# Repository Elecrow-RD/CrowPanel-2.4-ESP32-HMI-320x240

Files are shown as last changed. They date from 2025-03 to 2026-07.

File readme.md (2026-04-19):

### 1, Product picture

2 4_hmi_display

### 2, Product version number

| | Hardware | Software | Remark |
| ---- | --- | --- | --- |
| 1 | V1.0 | V1.0 | old |
| 1 | V1.1 | V1.0 | old |
| 1 | V2.0 | V1.0 | old |
| 1 | V2.1 | V1.0 | latest |

**Version 2.0/2.1** upgrades the automatic download feature from Version 1.0.

### 3, product information

- Model: 2.4 inches-CrowPanel ESP32 display
- Main Processor: ESP32-WROOM-32-N4
- Resolution: 240*320
- Touch Type: Resistive Touch Screen
- Display Type: TN Panel
- Screen: TFT-LCD Screen
- Display driver: ILI9341V
- External power supply: DC5V-2A
- Interface: 1\*TF Card Slot, 1* I2C, 1* GPIO, 1\*Speak, 1* UART1, 1*UART0
- Button: BOOT Button and Reset Button
- Active Area: 36.72\*48.96mm(W*H)
- Working Temperature: -20℃～70℃
- Storage Temperature: -30℃～80℃

### 4, Use the driver module

| Name | dependency library |
| ---- | --- |
| LVGL | lvgl/lvgl@8.3.3 |

### 5,Quick Start

##### Arduino IDE starts

1.Download the library files used by this product to the 'libraries' folder.

C:\Users\Documents\Arduino\libraries\



2.Open the Arduino IDE

arduino1

3.Open the code configuration environment and burn it

arduino2

##### ESP-IDF starts

1.Right-click on an empty space in the project folder and select "Open with VS Code" to open the project.



2.In the IDF plug-in, select the port, then compile and flash



##### PlatformIO starts

1.Right-click on an empty space in the project folder and select "Open with VS Code" to open the project.



2.In the PlatformIO plug-in, select the port, then compile and flash

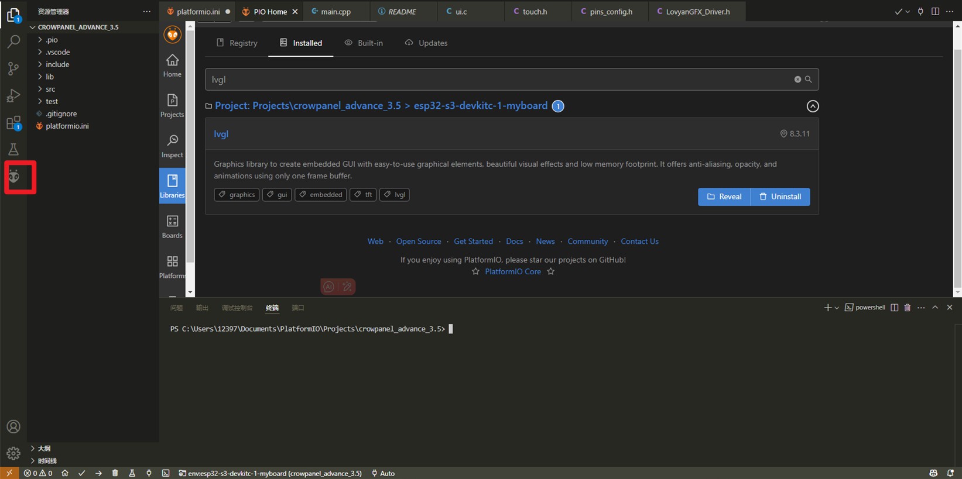
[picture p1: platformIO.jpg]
platformIO


##### Micropython starts

1,Right-click on an empty space in the project folder and select "Thonny" to open the project.

thonny

2,In thonny software, select the master and port, then run the program

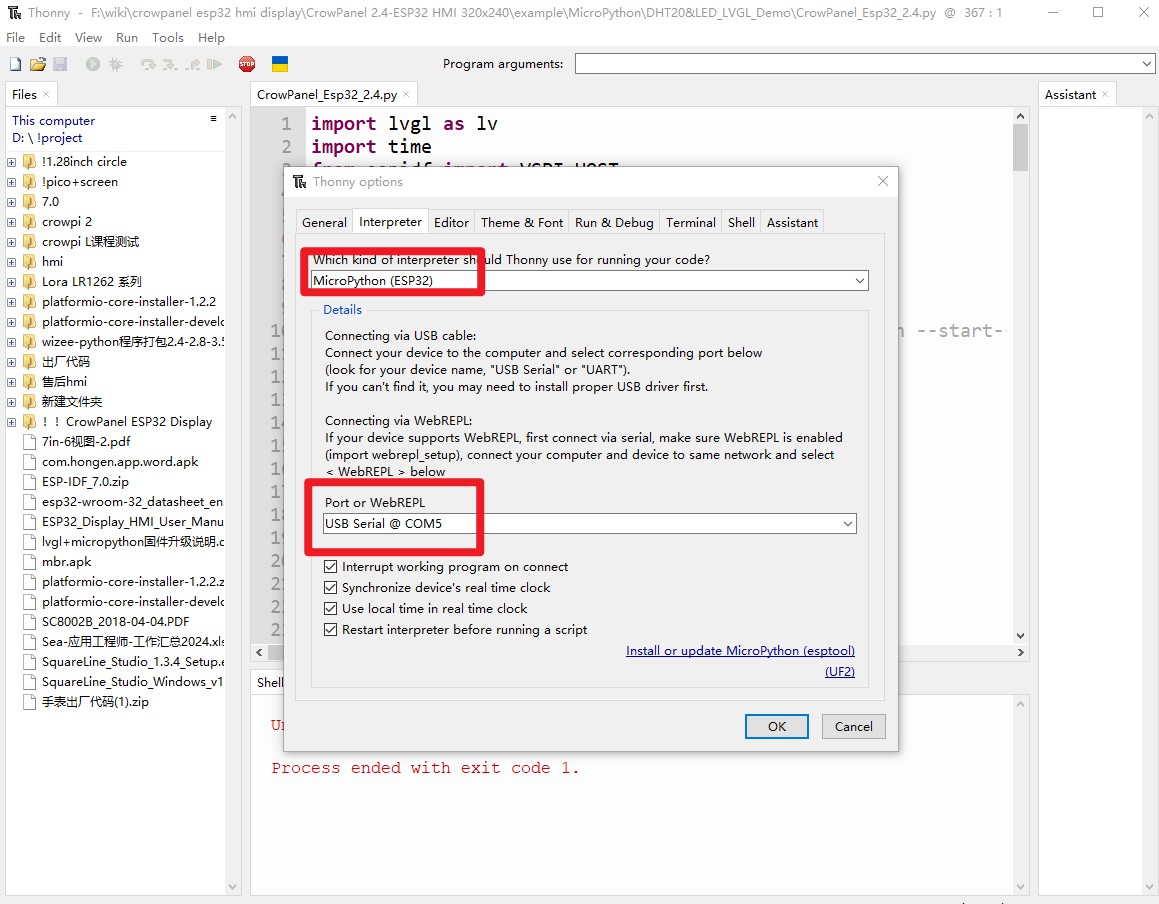
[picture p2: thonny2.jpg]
thonny2


### 6,Folder structure.

|--3D file： Contains 3D model files (.stp) for the hardware. These files can be used for visualization, enclosure design, or integration into CAD software.

|--Datasheet: Includes datasheets for components used in the project, providing detailed specifications, electrical characteristics, and pin configurations.

|--Eagle_SCH&PCB: Contains **Eagle CAD** schematic (`.sch`) and PCB layout (`.brd`) files. These are used for circuit design and PCB manufacturing.

|--example: Provides example code and projects to demonstrate how to use the hardware and libraries. These examples help users get started quickly.

|--factory_firmware: Stores pre-compiled factory firmware that can be directly flashed onto the device. This ensures the device runs the default functionality.

|--factory_sourcecode: Contains the source code for the factory firmware, allowing users to modify and rebuild the firmware as needed.

### 7,Pin definition

#define SD_MOSI 23

#define SD_MISO 19

#define SD_SCK 18

#define SD_CS 5

iic:

  Wire.begin(22, 21);

\#define TFT_BL   27            // LED back-light control pin

#define TFT_MISO 12 

#define TFT_MOSI 13 // In some display driver board, it might be written as "SDA" and so on. 

#define TFT_SCLK 14 #define TFT_CS   15  // Chip select control pin 

#define TFT_DC   2  // Data Command control pin 

#define TFT_RST  -1  // Reset pin (could connect to Arduino RESET pin) 

#define TFT_BL   27  // LED back-light 

#define TOUCH_CS 33     // Chip select pin (T_CS) of touch screen

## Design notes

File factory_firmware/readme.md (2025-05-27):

# How to install the factory demo firmware with flash download tool?

#### 1.Preparation:

- USB C cable
- Laptop/PC
- Crowpanel 2.4 HMI ESP32 Display
- Flash download tool

Check whether the materials on the PCBA board are defective. Such as less material, false welding, tin and other bad phenomena.

#### 2.Flash the firmware 

##### Step1 Connect the ESP32 display to the laptop/PC with USB-C cable. The power indicator will light up.

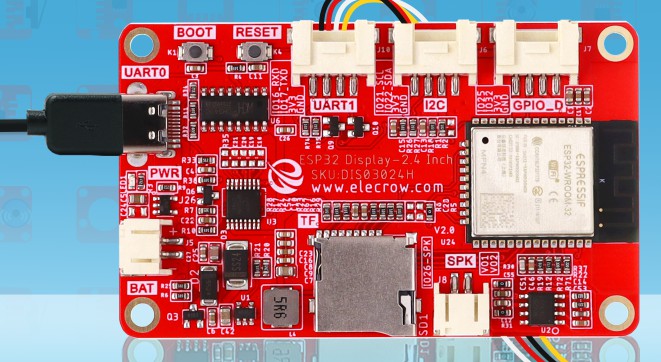
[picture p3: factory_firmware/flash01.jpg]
flash01


##### Step2 Open the flash download tool. 

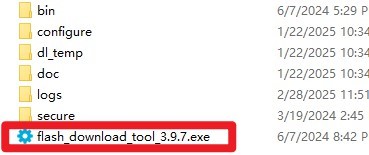
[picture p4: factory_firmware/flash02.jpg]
flash02


For the  Crowpanel 2.4 HMI ESP32 Display, the chip select ESP32:

firmware1

##### Step3

①Choose the firmware files;

flash0

②Enter the address: 

boot_app0.bin------0xe000

xxxx.ino.bin--------0x10000

xxxx.ino.bootloader.bin------0x1000

xxxx.ino.partitions.bin-------0x8000

③Check the firmware files;

④Select the correct port number;

⑤Click “Start” to download

firmware2

### Note: If it is v1.0 version, before downloading firmware or program, you need to press the boot button, then short press the reset button, and then release the boot button to enter the burn mode. If it is v2.0 or above, this step is not needed, it will automatically enter into burn mode.

##### Step5 After the download is complete, blue FINISH will be displayed, and the progress bar at the bottom shows that it has come to an end.

firmware3

##### Step6 Press the reset button to show the demo.

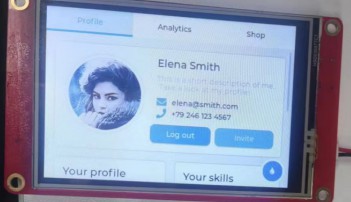
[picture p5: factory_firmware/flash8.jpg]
flash8


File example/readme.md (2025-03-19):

**Arduino**: This folder contains sample programs for the Arduino platform, which is known for its ease of use and versatility in creating interactive electronic projects.

#### NOTE!!!:When running this program , you need to download the officially provided libraries and place them in the libraries of arduino. esp32 version needs to be 2.0.14/2.0.15. the version of the libraries is the same as the officially provided version.

Link to the corresponding course wiki:https://www.elecrow.com/wiki/2.4-inch-esp32-dispaly-arduino-tutorial.html

homeassitant wiki:https://www.elecrow.com/wiki/2.4-inch-esp32-dispaly-homeAssistant-tutorial.html

Video Tutorial Links：https://www.youtube.com/watch?v=x4LrIeEJTls&t=2s

**ESP_IDF**: This directory holds example code for the Espressif IoT Development Framework (ESP-IDF), designed for developing applications on ESP32 and ESP8266 microcontrollers.

Link to the corresponding course wiki:https://www.elecrow.com/wiki/CrowPanel-ESP32-2.4-inch-with-ESP-IDF.html

**Esphome**: Here you'll find sample programs for Esphome, a firmware framework that simplifies the process of creating smart home devices using ESP8266/ESP32 chips.

Link to the corresponding course wiki:https://www.elecrow.com/wiki/CrowPanel_ESP32_2.4-inch_with_ESPHome.html

**MicroPython**: This section includes examples for MicroPython, a lean and efficient implementation of the Python programming language that can run on microcontrollers.

Link to the corresponding course wiki:https://www.elecrow.com/wiki/2.4-inch_ESP32_Display_MicroPython_Tutorial.html

**PlatformIO**: This folder contains sample projects for PlatformIO, an open-source ecosystem that streamlines the development process across various embedded platforms by providing a consistent environment for coding, compiling, and uploading firmware.:

Link to the corresponding course wiki:https://www.elecrow.com/wiki/CrowPanel_ESP32_2.4-inch_with_PlatformIO.html

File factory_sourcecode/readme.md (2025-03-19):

### NOTE!!!:When running this program arduino factory program, you need to download the officially provided libraries and place them in the libraries of arduino. esp32 version needs to be 2.0.14/2.0.15. the version of the libraries is the same as the officially provided version.

## Key Functions in the Arduino Program

### `setup()`
The `**setup()**` function is called once when the program starts. It initializes the serial communication, sets up the display, touchpad, and initializes the LVGL graphics library. It also sets the display rotation and initializes the display driver and input device driver for LVGL.

- `Serial.begin(115200)`: Initializes the serial communication with a baud rate of 115200.
- `lcd.begin()`: Initializes the TFT display.
- `lv_init()`: Initializes the LVGL graphics library.
- `lv_disp_drv_register(&disp_drv)`: Registers the display driver with LVGL.
- `lv_indev_drv_register(&indev_drv)`: Registers the input device driver (touchpad) with LVGL.
- `ui_init()`: Initializes the user interface.

### `loop()`
The `**loop()**` function is called repeatedly after `setup()`. It handles the main program logic, updating the display with temperature and humidity data and toggling an LED based on the `led` variable.

- `lv_label_set_text(ui_Label1, DHT_buffer)`: Updates the text of a label on the UI with the temperature value.
- `lv_label_set_text(ui_Label2, DHT_buffer)`: Updates the text of a label on the UI with the humidity value.
- `digitalWrite(25, HIGH)` and `digitalWrite(25, LOW)`: Sets the state of the LED connected to pin 25.
- `lv_timer_handler()`: Calls the LVGL task handler to process GUI tasks.

### `my_disp_flush()`
The `**my_disp_flush()**` function is a callback function used by LVGL to flush the display buffer to the screen.

- `lcd.startWrite()`: Begins a write transaction to the TFT display.
- `lcd.setAddrWindow(area->x1, area->y1, w, h)`: Sets the address window for the TFT display.
- `lcd.pushColors((uint16_t *)&color_p->full, w * h, true)`: Sends the color data to the TFT display.
- `lv_disp_flush_ready(disp)`: Informs LVGL that the flushing is done.

### `my_touchpad_read()`
The `**my_touchpad_read()**` function is a callback function used by LVGL to read touchpad data.

- `lcd.getTouch(&touchX, &touchY, 600)`: Reads the touch coordinates from the TFT display.
- `data->state = LV_INDEV_STATE_PR` or `LV_INDEV_STATE_REL`: Sets the state of the touchpad (pressed or released).
- `data->point.x = touchX` and `data->point.y = touchY`: Sets the touch coordinates for LVGL.

### `clearBufferArray()`
The `**clearBufferArray()**` function clears the serial buffer array.

- `buffer[i] = NULL`: Sets each element of the buffer array to NULL, effectively clearing it.

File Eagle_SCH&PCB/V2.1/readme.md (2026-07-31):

# CrowPanel ESP32 Display 2.4 V2.1 Hardware Driver Documentation

| Item | Content |
|---|---|
| Document Version | V1.0 |
| Corresponding Hardware | CrowPanel ESP32 Display-2.4 V2.1 (Schematic dated 2024-03-14) |
| Document Date | 2026-07-29 |
| Author | Codex (compiled by cross-referencing the project schematic and verified in-repo examples) |
| Intended Use | Hardware maintenance, Arduino driver porting, functional regression, and onboarding for new team members |

## 1. Scope and Validation Rules

The hardware basis for this documentation is `V2.1/CrowPanel ESP32 Display-2.4-V2.1-20240314.sch` (EAGLE 9.5.1) and the same-named PDF/BRD files; the software basis is the 8 peripheral examples under `Arduino/Course`, the LVGL composite example, and the project-bundled library configurations for TFT_eSPI/U8g2/XPT2046/SD/Crowbits_DHT20.

The evidence priority is as follows:

1. **Verified code (highest)**: The GPIO, bus mode, polarity, and parameters actually invoked in the examples.
2. **Project-specific library configuration**: Especially the active macros in `TFT_eSPI/User_Setup.h`.
3. **Schematic net connections**: Used to confirm electrical connections, pull-ups/pull-downs, power amplifiers, power supplies, and circuits not covered by code.
4. **General device characteristics**: Used only for explanation, not as a substitute for this board's measured behavior; content that cannot be verified from the repository is marked "to be measured."

Verification status definitions: **A** = confirmed by both schematic and running example; **B** = confirmed by schematic and project configuration but lacking an independent running example; **C** = confirmed by schematic only; **D** = externally connected expansion example, not an onboard device.

> Important: The repository contains no test logs, no pinned build-environment version files, and no measured waveforms. This documentation treats `Arduino/Course` as the "verified working code" referenced by the task, but it does not fabricate experimental results such as temperature, current, or waveforms.

## 2. Product and Software Architecture Overview

- Main controller: ESP32-WROOM-32-N4, 3.3 V logic, module integrates 4 MB SPI Flash and 2.4 GHz Wi-Fi/BLE.
- Software layer: Arduino-ESP32 (Arduino API + ESP-IDF driver headers), with no standalone RTOS tasks; the underlying FreeRTOS/Wi-Fi/BLE protocol stacks are managed by the Arduino core.
- Display: 2.4-inch 320×240 TFT module J1 (schematic library part `QD281801`), configured to run as **ILI9341, 4-wire SPI**.
- Input: 4-wire resistive touchscreen + XPT2046; two onboard buttons, BOOT and RESET.
- Storage: onboard microSD/TF card socket, on an independent VSPI bus.
- Audio: ESP32 DAC2 → SC8002B power amplifier → 2-pin speaker connector.
- Peripheral expansion: I2C, UART2, GPIO/ADC/DAC Crowtail/Twig interfaces.
- Power/Download: USB Type-C, CH340C, auto-download circuit, Li-ion charging/power path, RY3420 3.3 V regulator.

## 3. Peripheral Overview Table

| Peripheral/Device | Reference/Position | Interface and Key Pins (final code values) | Software/Driver | Status |
|---|---|---|---|---|
| ESP32-WROOM-32-N4 | U24 | GPIO0~39; UART0 GPIO1/3 | Arduino-ESP32 / ESP-IDF | A |
| ILI9341 TFT 320×240 | J1 | HSPI: SCLK14, MOSI13, MISO12, CS15, DC2; RST=-1; BL27 | TFT_eSPI | A |
| XPT2046 resistive touch | U3/J1 | Shares SCLK14/MOSI13/MISO12 with TFT; CS33; IRQ36 (unused in code) | TFT_eSPI built-in touch path | A/B |
| microSD/TF card | SD1 | VSPI: SCK18, MISO19, MOSI23, CS5 | SPI + SD + FS | A |
| 3.3 V power indicator LED | LED1 | 3V3→R3 4.7 kΩ→LED1→GND, always on | Pure hardware | C |
| GPIO25 controllable LED (code-defined) | Not mapped to LED1 in schematic | GPIO25; active-high (per verified code) | Arduino GPIO | A/C (with discrepancy) |
| Audio DAC/amplifier | U2/J8 | GPIO26/DAC2 → SC8002B → J8 | ESP-IDF `driver/dac.h` | A |
| I2C expansion port | J6 | **SDA22, SCL21**, 3V3, GND | Wire/U8g2/DHT20 | A/D |
| UART2 expansion port | J10 | MCU RX=16, TX=17, 3V3, GND | HardwareSerial(2) | A/D |
| GPIO/analog expansion port | J7 | GPIO25, GPIO32, 3V3, GND | GPIO/ADC/DAC (by usage) | C |
| Reserved analog/GPIO | Test/reserved nets | GPIO4, 34, 35, 39 | GPIO/ADC (34/35/39 input-only) | C |
| BOOT button | K1 | GPIO0, pulls to GND when pressed, active-low | ROM download boot strap | B |
| RESET button | K4 | EN, pulls to GND when pressed, active-low | Hardware reset | B |
| USB-UART | J3/U6 | Type-C D+/D− → CH340C → UART0 GPIO3/1 | USB serial driver + Serial | B |
| Auto-download | Q9/Q10 | CH340C DTR#/RTS# → GPIO0/EN | esptool/Arduino uploader | B |
| Wi-Fi | U24 internal | 2.4 GHz RF; no external GPIO | WiFi.h | A |
| Bluetooth LE | U24 internal | 2.4 GHz RF; no external GPIO | ESP32 BLE Arduino | A |
| Li-ion charging/power path | U26/Q3/D2/J5 | USB VBUS, BAT+, VIN | 4054A-class linear charging + PMOS/Schottky | C |
| 3.3 V power supply | U1/L4 | VIN → RY3420/HM3420B → 3V3 | Pure hardware, no software driver | C |
| External SSD1306 OLED | J6 external | SDA22, SCL21; software I2C | U8g2 | D |
| External DHT20 | J6 external | SDA22, SCL21; I2C address managed by library | Crowbits_DHT20 + Wire | D |
| External GPS | J10 external | GPS TX→GPIO16(RX2), GPS RX←GPIO17(TX2) | HardwareSerial(2) | D |

## 4. GPIO and Bus Resource Summary

| GPIO | Final Usage | Direction/Alternate | Electrical and Sharing Relationships |
|---:|---|---|---|
| 0 | BOOT | Input/boot strap | Pulled to GND when K1 pressed; must stay high during boot to boot normally from Flash |
| 1 | UART0 TX | Output/U0TXD | Via 22 Ω to CH340C RXD; used for download log |
| 2 | TFT D/C (RS) | Push-pull output | ESP32 boot strap pin; peripherals must not forcibly drive it to a wrong level during power-up |
| 3 | UART0 RX | Input/U0RXD | Via 22 Ω to CH340C TXD |
| 4 | Reserved GPIO/ADC2_CH0 | Bidirectional/ADC | ADC2 use is limited when concurrent with Wi-Fi |
| 5 | TF CS | Push-pull output/VSPI CS | Boot-strap-related pin; card socket has 10 kΩ pull-up network |
| 12 | TFT/touch MISO | Input/HSPIQ | GPIO12 is boot strap MTDI; being pulled high by a peripheral at power-up may change the Flash voltage configuration |
| 13 | TFT/touch MOSI | Output/HSPID | Shared by two devices, arbitrated by independent CS |
| 14 | Upper: TFT/touch SCLK | Output/HSPICLK | Shared by two devices; LCD 15.999999 MHz, touch 600 kHz |
| 15 | TFT CS | Push-pull output/HSPICS0 | Boot strap MTDO; should remain unselected before initialization |
| 16 | UART2 RX | Input/U2RXD | J10 pin 1; connects to peripheral TX |
| 17 | UART2 TX | Output/U2TXD | J10 pin 2; connects to peripheral RX |
| 18 | TF SCK | Output/VSPICLK | SD dedicated bus |
| 19 | TF MISO | Input/VSPIQ | SD dedicated bus |
| 21 | I2C SCL | Open-drain bidirectional (code role) | J6 pin 1, via 1 kΩ series; schematic net name `IO21_SCL` |
| 22 | I2C SDA | Open-drain bidirectional (code role) | J6 pin 2, via 1 kΩ series; schematic net name `IO22_SDA` |
| 23 | TF MOSI | Output/VSPID | SD dedicated bus |
| 25 | Code-defined controllable LED/J7 pin 1 | Push-pull output; also DAC1/ADC2 | Code controls LED high/low; V2.1 schematic only clearly connects it to J7, not to LED1 |
| 26 | Speaker | DAC2 analog output | Fed to SC8002B via coupling/feedback network; must not be reused as a normal digital peripheral |
| 27 | LCD backlight | Push-pull/PWM optional | Drives 2N7002 gate; code HIGH turns it on |
| 32 | J7 pin 2 | GPIO/ADC1_CH4 | 3.3 V logic; usable as a reliable ADC input |
| 33 | Touch CS | Push-pull output | Independent chip-select for XPT2046 |
| 34 | Reserved ADC1_CH6 | **Input only** | No internal output drive capability |
| 35 | Reserved ADC1_CH7 | **Input only** | No internal output drive capability |
| 36 | Touch IRQ | **Input only**/ADC1_CH0 | XPT2046 PENIRQ; current example polls, no attachInterrupt |
| 39 | Reserved ADC1_CH3 | **Input only** | No internal output drive capability |

Bus isolation: display/touch use the HSPI pin group 12/13/14, while the TF card uses the VSPI pin group 19/23/18, so they can operate in parallel; on the same HSPI bus, TFT CS15 and Touch CS33 must be mutually exclusive.

## 5. Per-Peripheral Driver Description

### 5.1 ESP32-WROOM-32-N4 Main Controller

**Hardware**: U24, 3.3 V supply, module model explicitly N4 (4 MB Flash). EN is pulled up by 10 kΩ and connected to the reset button/auto-download circuit; GPIO0 is controlled by the BOOT button and the auto-download circuit. UART0 connects to USB via CH340C.

**Software layer**: Arduino sketch → Arduino-ESP32 core → ESP-IDF HAL/drivers and FreeRTOS. The code contains no bare-metal register writes and no self-created RTOS tasks.

**Basic configuration example**:

```cpp
void setup() {
  Serial.begin(115200);       // Debug baud rate used by most examples
  pinMode(25, OUTPUT);
}
```

When porting, select the classic ESP32 target (not S2/S3/C3), and configure Flash to at least 4 MB. The repository does not record the Arduino core version, partition table, CPU frequency, or Flash mode, so a build manifest should be added during maintenance.

### 5.2 TFT LCD (J1, code configured as ILI9341)

**Connections**: GPIO14=SCLK, 13=MOSI/SDI, 12=MISO/SDO, 15=CS, 2=D/C; TFT RESET does not occupy a GPIO—the project configures `TFT_RST -1`, and the schematic's `TFT_RESET` connects to the main reset EN via R5/C28. GPIO27 controls the backlight cathode through a 2N7002, HIGH turns it on. The display supply and LED anode are 3.3 V.

**Protocol/parameters**: 4-wire hardware SPI; ILI9341; physically portrait 240×320, rotated to 320×240 after the composite example calls `setRotation(1)`; write frequency **15,999,999 Hz**, read frequency 20 MHz. TFT_eSPI's `lcd.begin()` sends the controller initialization register table.

**Software dependencies**: TFT_eSPI; the LVGL example additionally depends on LVGL 9-style APIs. The key project configuration is in `Arduino/libraries/TFT_eSPI/User_Setup.h`.

```cpp
#define ILI9341_DRIVER
#define TFT_MISO 12
#define TFT_MOSI 13
#define TFT_SCLK 14
#define TFT_CS   15
#define TFT_DC    2
#define TFT_RST  -1
#define TFT_BL   27
#define SPI_FREQUENCY 15999999

TFT_eSPI lcd;
lcd.begin();
lcd.fillScreen(TFT_BLACK);
pinMode(27, OUTPUT);
digitalWrite(27, HIGH);
lcd.setRotation(1);
```

**Initialization order**: SPI/controller init → clear to black → delay 300 ms (composite example) → backlight HIGH → set rotation → register LVGL flush. This reduces power-on display artifacts.

**Discrepancy note**: The schematic only uses the module part number `QD281801` and does not directly state ILI9341; the code and the active TFT_eSPI macros explicitly select ILI9341, so maintenance and porting should be based on ILI9341. The `TFT_WIDTH/TFT_HEIGHT` comment text mentions ST7789, but the active driver is ILI9341; this is leftover commentary from a generic configuration file and does not mean this board uses ST7789.

### 5.3 XPT2046 Resistive Touch

**Connections**: XPT2046 U3 shares GPIO14/DCLK, 13/DIN, 12/DOUT with the TFT; GPIO33=CS; GPIO36=PENIRQ. The touchscreen's four wires XP/XN/YP/YN connect to J1 through 100 pF filter capacitors. Supply/IOVDD/VREF are all 3.3 V.

**Protocol/parameters**: SPI, project sets `SPI_TOUCH_FREQUENCY 600000` (600 kHz); CS active-low. The current code polls using `lcd.getTouch()`, with a pressure threshold of 600 and no GPIO36 interrupt. The calibration array is for this specific unit/orientation: `{557, 3263, 369, 3493, 3}`.

```cpp
#define TOUCH_CS 33
#define SPI_TOUCH_FREQUENCY 600000
uint16_t calData[5] = {557, 3263, 369, 3493, 3};
lcd.setRotation(1);
lcd.setTouch(calData);
bool pressed = lcd.getTouch(&x, &y, 600);
```

**Note**: After changing the screen, changing the touch lamination orientation, or changing rotation, `calibrateTouch()` must be re-run; do not treat this calibration set as valid across the entire production batch. If switching to interrupt mode, GPIO36 is input-only—confirm on the actual board using PENIRQ active-low/falling-edge before enabling.

### 5.4 microSD/TF Card

**Connections**: GPIO18=SCK, 23=MOSI/CMD, 19=MISO/DATA0, 5=CS/DATA3, 3.3 V supply. CMD, CS, and DATA0/1/2/3 all have 10 kΩ pull-ups, meeting SD/SPI idle requirements.

**Protocol/parameters**: SPI mode of the Arduino SD library. The code explicitly maps VSPI pins and calls `SD.begin(5)` after a 100 ms wait; no frequency is passed, so the actual initial/operating frequency is determined by the Arduino-ESP32 SD library version in use—the repository cannot give a fixed value.

```cpp
SPI.begin(18, 19, 23);  // SCK, MISO, MOSI
delay(100);
if (!SD.begin(5)) { /* mount failed */ }
```

**Dependencies**: `SPI.h`, `SD.h`, `FS.h`. The example verifies mounting, card type, capacity, and two-level directory traversal.

**Note**: The card accepts 3.3 V signals only; the filesystem must finish writing before hot-swapping. The board has no card-detect GPIO confirmed from code/net names, so applications should judge insertion/removal via `SD.begin()`/I/O errors.

### 5.5 Power Indicator LED, GPIO25 Controllable LED, and GPIO Expansion

The LED1 in the schematic is a red **power indicator LED**: 3V3 connects through R3=4.7 kΩ to the LED1 anode, with the cathode to GND, so it stays on during power-up and has no electrical connection to GPIO25. GPIO25 connects to J7 pin 1 through R18=1 kΩ.

The verified example explicitly defines GPIO25 as the `on-board LED`, turned on with HIGH and off with LOW. Following the "make code run first" principle, software porting still uses GPIO25 and this polarity as the effective driving baseline; however, the V2.1 schematic cannot explain this controllable LED's on-board connection—it may be a board revision not synchronized with the schematic, an example targeting a different assembly version, or an LED that must be externally connected via J7. Maintenance personnel should confirm via PCB trace inspection/continuity testing with a multimeter, and must not treat the schematic's LED1 as this GPIO25 controllable LED.

```cpp
pinMode(25, OUTPUT);
digitalWrite(25, HIGH); // Verified example: LED on
```

J7: pin1=GPIO25, pin2=GPIO32, pin3=3V3, pin4=GND. GPIO25 also has DAC1/ADC2, and GPIO32 has ADC1_CH4; expansion peripherals will share GPIO25 with the code-defined LED control. Peripheral current must not directly exceed the ESP32 GPIO drive capability; high loads should add a MOSFET/transistor.

### 5.6 Speaker and SC8002B Amplifier

**Connections**: GPIO26/DAC2 enters U2 SC8002B through R12=4.7 kΩ and an AC/feedback network; U2 is 3.3 V supplied, with differential outputs VO1/VO2 connecting to the J8 speaker connector—neither end may be grounded. The schematic connects SHUTDOWN to AGND and assigns no software enable pin.

**Drive method**: ESP32 built-in 8-bit DAC channel 2. The example outputs via busy-waiting using a 256-point sine table; at 1 kHz the nominal sample rate is 256 ksample/s, playing for 1 s, muted for 2 s, then returning to the mid code 128 at the end to reduce DC step.

```cpp
#include <driver/dac.h>
dac_output_enable(DAC_CHANNEL_2);       // GPIO26
dac_output_voltage(DAC_CHANNEL_2, sample8bit);
```

**Risk**: The current `delayMicroseconds()` software timing occupies the CPU, and the actual frequency is affected by function overhead, making it unsuitable for high-fidelity output or strong concurrency with UI/Wi-Fi. For production, switch to I2S/DAC DMA or timer-driven output, and measure the amplifier gain, clipping, speaker impedance, and temperature rise. Do not perform single-ended oscilloscope ground measurements on the bridged amplifier output.

### 5.7 I2C Expansion Port, SSD1306, and DHT20

J6 pin1=GPIO21, pin2=GPIO22, pin3=3V3, pin4=GND; each signal has a 1 kΩ series resistor. **The final software definition is GPIO22=SDA, GPIO21=SCL**.

```cpp
Wire.begin(22, 21); // SDA, SCL
Crowbits_DHT20 dht20;
dht20.begin();
```

The external OLED example uses U8g2 software I2C:

```cpp
U8G2_SSD1306_128X64_NONAME_F_SW_I2C u8g2(
  U8G2_R0, /* clock */ 21, /* data */ 22, U8X8_PIN_NONE);
u8g2.begin();
```

**Parameters**: The SSD1306 example is 128×64 with no independent reset; the DHT20 example does not set address/frequency at the application layer and uses library defaults. The repository code does not lock the I2C clock and slave address, so they should be verified via the library implementation/bus scan before porting; common values cannot substitute for this project's evidence.

**Schematic discrepancy**: The net names are `IO21_SCL`, `IO22_SDA`, which are consistent with the code and the Arduino `Wire.begin(SDA,SCL)` parameters forming the "21=SCL, 22=SDA" connection; this itself is consistent, but old comments in the example files have easily caused the two to be misread in order. All new code must explicitly write `Wire.begin(22,21)`, and must not guess the parameter order based solely on interface names.

### 5.8 UART2 / External GPS

J10 pin1=GPIO16/RX2, pin2=GPIO17/TX2, pin3=3V3, pin4=GND. The example bridges GPS and the USB serial using UART2, 9600 baud, 8N1 full-duplex:

```cpp
HardwareSerial gpsSerial(2);
gpsSerial.begin(9600, SERIAL_8N1, 16, 17); // RX, TX
```

Wiring must be crossed: GPS TX→J10 RX/GPIO16, GPS RX←J10 TX/GPIO17, and share ground. J10 logic level is 3.3 V and must not be directly connected to RS-232 levels. The composite LVGL example only writes `Serial2.begin(9600)`, relying on the ESP32 default UART2 mapping; when porting, explicitly specifying 16/17 is recommended to avoid core/board-type differences.

### 5.9 Wi-Fi

The ESP32 module has built-in 2.4 GHz Wi-Fi with no additional driver GPIO. The example uses Arduino `WiFi.h`, STA mode, auto-reconnect, and blocks waiting for connection:

```cpp
WiFi.begin(ssid, password);
WiFi.setAutoReconnect(true);
while (WiFi.status() != WL_CONNECTED) delay(100);
```

The example contains plaintext demonstration SSID/password and should not enter production firmware. The blocking wait has no timeout; production code should add a timeout, network provisioning, and secure credential storage. When using Wi-Fi, analog sampling on ADC2 (GPIO2/4/12/13/14/15/25/26, etc.) is limited by ESP32 hardware constraints; prefer ADC1's GPIO32/34/35/36/39.

### 5.
10 Bluetooth Low Energy

Using the classic ESP32 BLE Arduino stack, device name `ESP32SPI-BLE`; establish a custom service and a READ/WRITE/NOTIFY characteristic:

```cpp
BLEDevice::init("ESP32SPI-BLE");
auto server = BLEDevice::createServer();
auto service = server->createService(SERVICE_UUID);
auto characteristic = service->createCharacteristic(
  CHARACTERISTIC_UUID,
  BLECharacteristic::PROPERTY_READ |
  BLECharacteristic::PROPERTY_WRITE |
  BLECharacteristic::PROPERTY_NOTIFY);
```

This example has no pairing, encryption, authentication, or write callback and cannot be used directly as a secure product protocol.
If you need to notify the client, you must also set a new value after connection and call `notify()`; the example only demonstrates the advertising/GATT setup path.

### 5.11 USB Type-C, CH340C, and Auto-Download

J3 is the USB Type-C USB 2.0 data/5 V input; CC1/CC2 each have a 5.1 kΩ pulldown, declaring the device side (sink/UFP). D+/D− run through 22 Ω series resistors to CH340C U6. The CH340C UART connects to ESP32 UART0 via 22 Ω: CH340 TXD → GPIO3/RX0, CH340 RXD ← GPIO1/TX0.

The CH340C DTR#/RTS# automatically control GPIO0 and EN via Q9/Q10 (S9013), implementing the download/reset sequence; K1/K4 allow manual control of BOOT/RESET. On the software side, `Serial` uses UART0; the example baud rates are inconsistent between 9600 and 115200, so the serial monitor must match the current sketch.

Maintenance note: UART0 handles both downloading and logging; external devices must not drive GPIO1/3 strongly during reset/download. Type-C only depicts USB 2.0 and does not support USB-PD negotiation; it must not be powered via PD high voltage.

### 5.12 Battery Charging, Power Path, and 3.3 V Supply

**Charging/Path**: J5 is the battery connector, pin1=BAT+, the remaining visible pins are grounded; U26 is marked `4054A`, powered by USB VBUS, with PROG setting the charge current via R9=2 kΩ; Q3 (PMOS-3401) and D2 (1N5817) form the USB/battery-to-VIN path and reverse-current protection. The specific charge-current formula, termination voltage, and battery polarity must be verified against the actual mounted U26 datasheet and silkscreen; the repository contains no BOM/datasheet, and this document makes no assumptions.

**3.3 V**: U1 schematic deviceset `HM3420B`, value `RY3420`, L4=5.6 µH; feedback R20=45.3 kΩ, R21=10 kΩ, output net name 3V3. It is a switching power supply topology supplying the MCU, LCD, touch, SD, and interfaces. The code has no power enable control.

**Risks**:

- Only allow a single-cell Li-ion system to be connected after confirming the specific U26 model; J5 polarity must be verified on the actual board.
- The charge current corresponding to R9=2 kΩ must not be taken into mass production directly from a generic 4054 formula; the actual part number must be checked and temperature rise verified.
- USB/battery switching, undervoltage behavior, maximum 3.3 V load, and ripple are not covered by the software example and require dedicated power testing.
- All external interfaces are rated at 3.3 V nominal; 5 V GPIO levels must not be applied.

### 5.13 BOOT, RESET, and Reserved Analog Pins

- K1: GPIO0→GND, active low; hold BOOT then reset to enter ROM download mode.
- K4: EN→GND, active low hard reset; EN has a pull-up and capacitor forming the power-on reset.
- GPIO34/35/39: schematic marked as a reserved ADC/analog network, input only, with no internal pull-up/pull-down.
- GPIO4: reserved GPIO/ADC2; its ADC2 function should not be relied upon when Wi-Fi is in use.
- GPIO36: already connected to touch PENIRQ and cannot be used unconditionally as a general-purpose ADC.

## 6. LVGL Comprehensive Driver Path

The comprehensive example simultaneously validates TFT, touch, GPIO25, I2C DHT20, and retains UART2 initialization. LVGL uses a 320×240 landscape display with a 1/8-screen single buffer: `320*240/8` `lv_color_t` units. The flush callback writes via a TFT_eSPI transaction; the input callback polls the touch.

```cpp
static lv_color_t buf1[320 * 240 / 8];
lv_init();
lv_tick_set_cb(millis);

lv_display_t *disp = lv_display_create(320, 240);
lv_display_set_flush_cb(disp, my_disp_flush);
lv_display_set_buffers(disp, buf1, NULL, sizeof(buf1),
                       LV_DISPLAY_RENDER_MODE_PARTIAL);

lv_indev_t *indev = lv_indev_create();
lv_indev_set_type(indev, LV_INDEV_TYPE_POINTER);
lv_indev_set_read_cb(indev, my_touchpad_read);
```

The main loop calls `lv_timer_handler()` every 10 ms but also synchronously reads DHT20 and prints heavily to the serial port. For production, the sensor sampling frequency should be reduced (e.g., via a separate timer/timestamp period) to avoid I2C or serial blocking that degrades UI frame rate.

## 7. Schematic–Code Cross-Verification Conclusions

| Item | Schematic | Verified Code/Config | Conclusion and Handling |
|---|---|---|---|
| LCD controller | J1 only marked `QD281801` | `ILI9341_DRIVER` | Use ILI9341 as reference; module part number does not equal controller name |
| LCD SPI | 14/13/12, CS15, DC2 | exactly the same | Consistent |
| LCD reset | `TFT_RESET` to EN (via R5/C28) | `TFT_RST=-1` | Consistent: no independent GPIO |
| Backlight | GPIO27→2N7002 | GPIO27 HIGH then lights up | Consistent; PWM can be added |
| Touch | XPT2046, shared SPI, CS33, IRQ36 | Shared SPI, CS33; polling does not use IRQ | Connection consistent; IRQ function not verified in code |
| TF card | SCK18/MOSI23/MISO19/CS5 | exactly the same | Consistent |
| I2C | Net name 21=SCL, 22=SDA | `Wire.begin(22,21)` | Consistent; note the API parameter order is SDA, SCL |
| UART2 | RX16/TX17 | Explicit example identical | Consistent; comprehensive example suggests adding explicit pins |
| Speaker | GPIO26/DAC2→SC8002B | DAC_CHANNEL_2 | Consistent |
| LED | LED1 is a 3V3 always-on power light; GPIO25 only clearly connects to J7 | Code refers to GPIO25 as the onboard LED, HIGH=on | Clearly inconsistent; drive follows code, physical connection reason pending continuity confirmation |
| TFT SPI frequency | Undefined in schematic | 15,999,999 Hz | Follow project configuration |
| Touch SPI frequency | Undefined in schematic | 600 kHz | Follow project configuration |
| DHT20/OLED/GPS | Only expansion ports provided, no onboard devices | External module examples | Marked as external capability, not listed as onboard devices |

Apart from the GPIO25 controllable LED, no clear "schematic pin conflicting with running code" was found. The GPIO25 discrepancy can only list possible causes (board revision/assembly version/external LED), and without physical continuity evidence no single cause can be asserted.

## 8. Risks and Notes Checklist

### 8.1 High Priority

1. **Strap-pin conflict**: GPIO0, 2, 5, 12, and 15 all involve boot configuration or onboard SPI; peripherals strongly pulling at power-on may prevent booting. In particular, a high level on GPIO12 may select an incompatible Flash power-supply configuration.
2. **3.3 V level**: I2C/UART/GPIO/SPI are not 5 V-tolerant interfaces; 5 V modules must add level shifting.
3. **Amplifier is differential output**: Neither terminal of J8 is ground; do not ground the negative terminal or directly short it with a grounded oscilloscope probe clip.
4. **Battery safety not closed**: With no BOM and no specific U26 datasheet, charge current, temperature rise, battery polarity, and protection capability must be confirmed by measurement.
5. **Credential leakage**: The Wi-Fi example contains a plaintext demo password; for mass production it must be removed and the real credentials rotated.

### 8.2 Medium Priority

1. GPIO25 simultaneously carries the code-defined LED function and an expansion port; GPIO36 simultaneously connects to the touch IRQ; do not reassign them. GPIO25's LED physical connection needs re-checking per the discrepancy noted above.
2. TFT and touch share SPI; any self-written driver must correctly pull up the non-target CS and avoid holding transactions across devices.
3. GPIO34/35/36/39 are input only; they cannot drive an LED, CS, or bus clock.
4. ADC2 conflicts with Wi-Fi concurrency; analog sampling should prefer GPIO32/34/35/39 (of which 36 is already occupied).
5. The software DAC sine implementation keeps the CPU busy and jitters under UI, BLE/Wi-Fi concurrency.
6. Touch calibration is related to screen orientation/individual unit; recalibrate after changing the screen.
7. The SD card has no card-detect pin visible; removing the card during writing will corrupt the filesystem.

### 8.3 Maintainability

1. The repository does not pin versions of Arduino-ESP32, TFT_eSPI, LVGL, etc.; a reproducible build manifest should be added.
2. Example serial baud rates mix 9600/115200; unify the product logging configuration.
3. `TFT_eSPI/User_Setup.h` is a global library configuration that may be overwritten on library upgrade/reinstall; migrate it to a standalone setup file or build macro.
4. The comprehensive example has no explicit touch `setTouch(calData)`; if the library does not save/load calibration, coordinates may be wrong and should be set explicitly during product initialization.
5. The BLE example has no security mechanism and the Wi-Fi connection has no timeout; both are teaching code and should not be carried into production as-is.

## 9. Driver Porting Checklist

1. Select the classic ESP32 target, 4 MB Flash, and confirm Flash mode and the GPIO12 boot state.
2. Pin the versions of Arduino-ESP32, TFT_eSPI, LVGL, U8g2, SD, and Crowbits_DHT20.
3. Import this project's valid TFT_eSPI macros; confirm ILI9341 and HSPI 12/13/14.
4. Keep TFT CS15, Touch CS33, and SD CS5 deselected at power-on.
5. Start the display following the sequence "LCD init and clear screen → backlight GPIO27 HIGH".
6. After setting rotation=1, recalibrate the touch and save calibration data for each screen assembly orientation.
7. For I2C explicitly call `Wire.begin(22,21)`; for UART2 explicitly call `begin(...,16,17)`.
8. For SD explicitly call `SPI.begin(18,19,23)` then `SD.begin(5)`, and perform plug/unplug and power-loss tests.
9. Check that GPIO25, 26, 27, 36, and the strap pins are not re-assigned by the application.
10. Complete USB/battery switching, maximum load, backlight PWM, audio clipping/temperature-rise, and EMC measurements.

## 10. Suggested Hardware Regression Tests

| Test | Method | Pass Criteria |
|---|---|---|
| Boot/Download | USB cold start, auto-download, manual BOOT+RESET, 20 times each | No boot failures, stable download |
| 3.3 V Supply | USB/battery, no-load/full-load ripple and drop measurement | Meets MCU/LCD/SD device specifications |
| LCD | RGB/solid color/full-screen refresh/read ID (if supported) | No glitch, color error, or tearing anomaly |
| Backlight | GPIO27 switch and PWM sweep | No flicker; MOS/LED temperature rise qualified |
| Touch | Five-point calibration, corners, long press, swipe | Coordinate error meets product spec, no false touches |
| SD | Multiple capacity/speed-class cards, repeated mount and large-file read/write | No CRC/I/O errors; power-loss strategy effective |
| I2C | Scan, DHT20/OLED on same bus, long-line stress | No address conflict/NACK; waveform rise time qualified |
| UART2 | 9600 8N1 loopback and GPS long-duration reception | No packet loss/frame error |
| Audio | Multiple frequency/amplitude, rated speaker, temperature rise | No obvious clipping/DC bias; temperature rise qualified |
| RF | Wi-Fi/BLE concurrency, throughput during LCD/SD refresh | No unacceptable dropout or interference |
| Battery | Charge curve, termination, hot-plug, reverse current, undervoltage | Complies with actual U26/battery specifications and safety requirements |

## 11. Evidence File Index

- Schematic: `V2.1/CrowPanel ESP32 Display-2.4-V2.1-20240314.sch`
- Schematic PDF: `V2.1/CrowPanel ESP32 Display-2.4-V2.1-20240314.pdf`
- PCB: `V2.1/CrowPanel ESP32 Display-2.4-V2.1-20240314.brd`
- LCD/touch config: `Arduino/libraries/TFT_eSPI/User_Setup.h`
- Comprehensive example: `Arduino/Course/LVGL_Arduino2.4/LVGL_Arduino2.4.ino`
- Single examples: `Arduino/Course/Example1_LED_blinking` through `Example8_GPS_Module`
- Related libraries: TFT_eSPI, XPT2046_Touchscreen, SD, U8g2, Crowbits_DHT20, LVGL

---

**Handoff Conclusion**: The core driver baseline of this board consists of two non-overlapping SPI groups (LCD/touch HSPI and TF VSPI), I2C SDA22/SCL21, UART2 RX16/TX17, DAC2/GPIO26 audio, GPIO27 high-active backlight, and the code-defined GPIO25 controllable LED (whose on-board connection requires physical verification). The most error-prone aspects when porting are the TFT_eSPI global configuration, touch calibration, I2C API parameter order, external levels on the strap pins, and carrying the teaching examples' blocking/plaintext/no-security logic directly into product firmware.

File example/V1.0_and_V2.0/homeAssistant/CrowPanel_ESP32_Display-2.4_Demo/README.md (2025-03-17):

**If you are using this demo code for the first time, I suggest that you watch this video lesson first.**

video link:

[Create and Export Stunning UI with SquareLine Studio for ESP32 Display | LVGL Tutorial - YouTube](https://www.youtube.com/watch?v=Ls0uLyeAgiw)

---

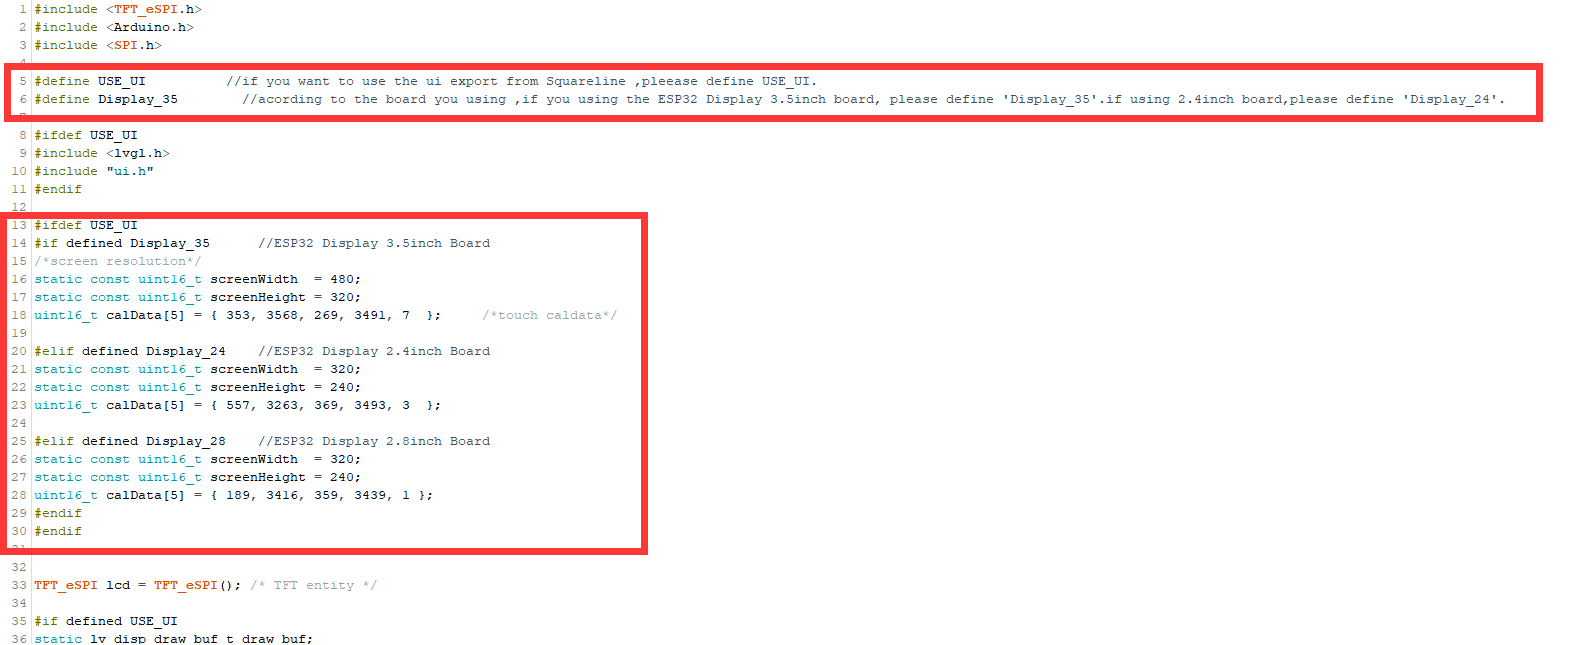
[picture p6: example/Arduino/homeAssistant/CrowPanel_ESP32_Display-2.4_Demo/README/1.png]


Please notice the tips inside the demo code,that is very important.

**If you don't want to use the UI export from Squareline Studio ,please del the UI file, and open the demo program again, then you can compile the program, or your program may happen some errors.**

---

And make sure that the 'User_Setup.h' file of the TFT_eSPI library is already correctly configured.

Or you can find the 'User_Setup.h' file from the 'User_Setup' floder.

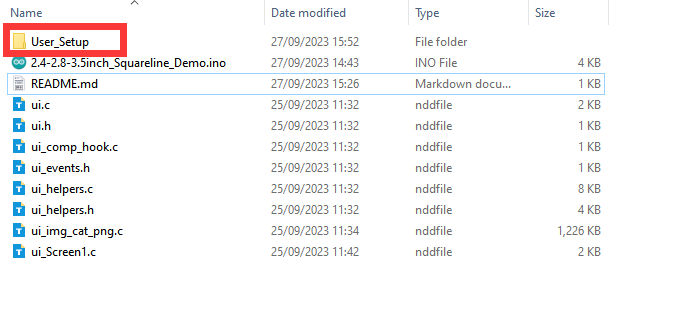
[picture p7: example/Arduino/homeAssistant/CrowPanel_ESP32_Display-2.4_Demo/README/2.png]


You need to copy the 'User_Setup.h' file according the board you're using to the TFT_eSPI library directory, and then, rename it to 'User_Setup.h'

If you already have a 'User_Setup.h' file in the TFT_eSPI library directory, replace it.

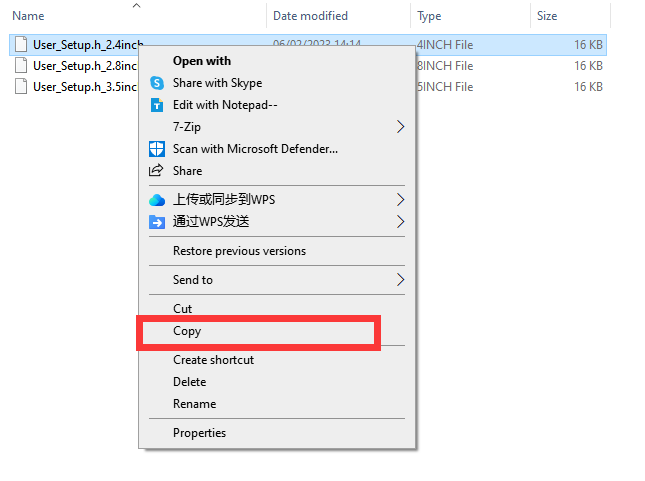
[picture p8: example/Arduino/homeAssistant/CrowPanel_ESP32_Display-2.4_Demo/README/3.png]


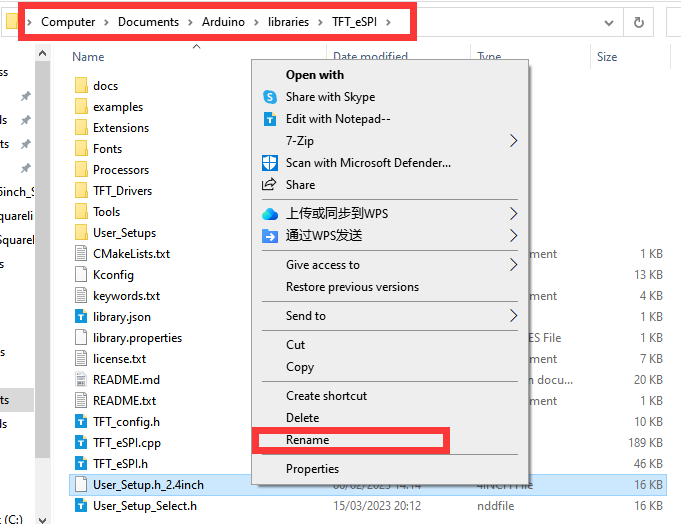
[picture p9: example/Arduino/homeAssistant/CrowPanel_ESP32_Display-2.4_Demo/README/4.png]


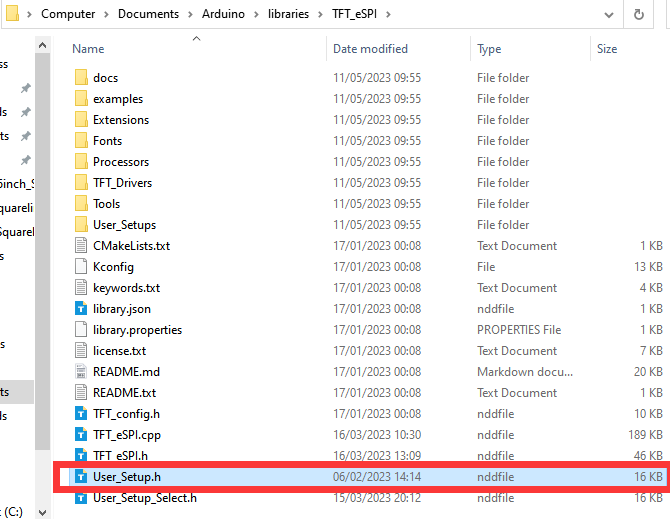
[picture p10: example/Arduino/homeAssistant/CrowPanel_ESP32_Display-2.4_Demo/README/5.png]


-------------------------------------------------------------END----------------------------------------------------------

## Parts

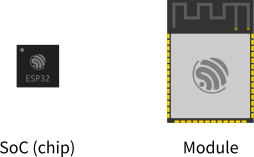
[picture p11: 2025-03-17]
example/V1.0_and_V2.0/ESP_IDF/ESP-IDF_2.4/2.4/Demo/components/arduino-esp32-master/docs/source/_static/soc-module.png

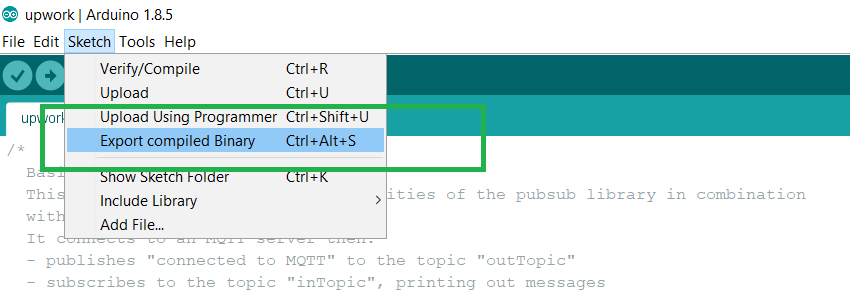
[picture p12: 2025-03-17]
example/V1.0_and_V2.0/ESP_IDF/ESP-IDF_2.4/2.4/Demo/components/arduino-esp32-master/docs/source/_static/ota_export_to_binary.png

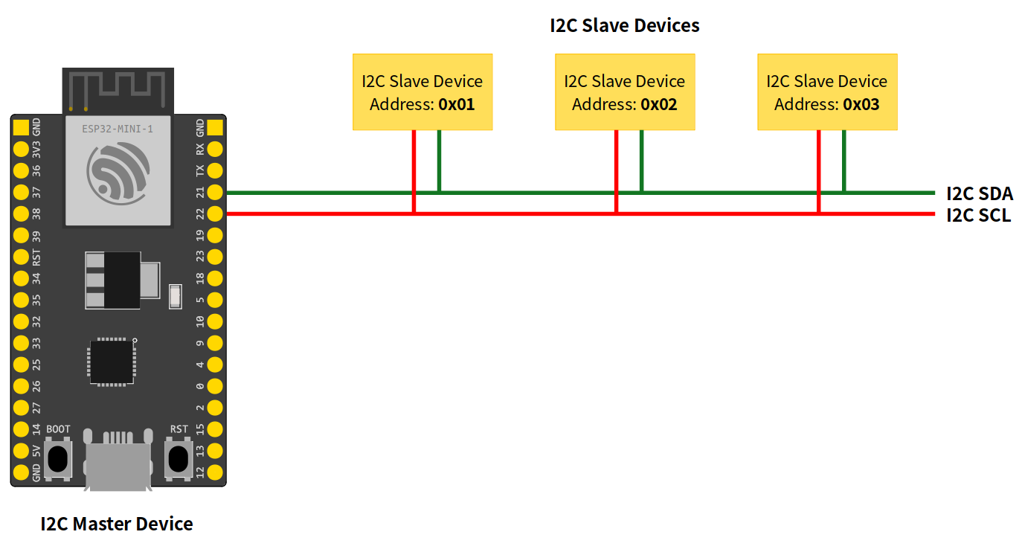
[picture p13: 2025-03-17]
example/V1.0_and_V2.0/ESP_IDF/ESP-IDF_2.4/2.4/Demo/components/arduino-esp32-master/docs/source/_static/arduino_i2c_master.png

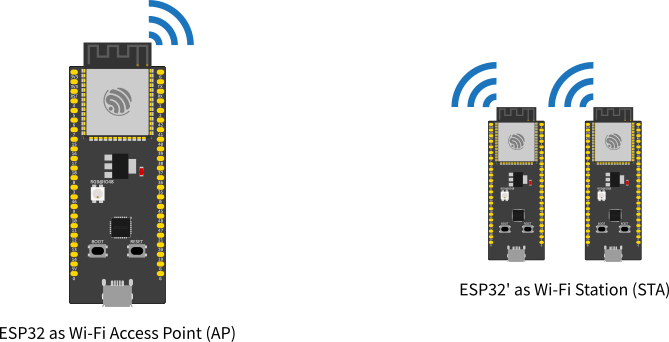
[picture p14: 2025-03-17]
example/V1.0_and_V2.0/ESP_IDF/ESP-IDF_2.4/2.4/Demo/components/arduino-esp32-master/docs/source/_static/wifi_esp32_ap.png

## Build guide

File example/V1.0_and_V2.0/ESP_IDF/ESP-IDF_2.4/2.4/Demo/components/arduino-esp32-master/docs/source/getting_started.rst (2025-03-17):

###############
Getting Started
###############

About Arduino ESP32
-------------------

Welcome to the Arduino ESP32 support documentation! Here you will find important information on how to use the project.

First Things First
------------------

.. note::
    Before continuing, we must be clear that this project is supported by `Espressif Systems`_ and the community.
    Everyone is more than welcome to contribute back to this project.

ESP32 is a single 2.4 GHz Wi-Fi-and-Bluetooth SoC (System On a Chip) designed by `Espressif Systems`_.

ESP32 is designed for mobile, wearable electronics, and Internet-of-Things (IoT) applications. It features all the state-of-the-art characteristics 
of low-power chips, including fine-grained clock gating, multiple power modes,and dynamic power scaling. For instance, in a low-power IoT sensor 
hub application scenario, ESP32 is woken-up periodically and only when a specified condition is detected. Low-duty cycle is used to minimize the 
amount of energy that the chip expends. 

The output of the power amplifier is also adjustable, thus contributing to an optimal trade-off between communication range, data rate and 
power consumption.

The ESP32 series is available as a chip or module.

.. _supported_socs:

Supported SoC's
---------------

Here are the ESP32 series supported by the Arduino-ESP32 project:

======== ====== =========== ===================================
SoC      Stable Development Datasheet
======== ====== =========== ===================================
ESP32    Yes    Yes         `ESP32`_
ESP32-S2 Yes    Yes         `ESP32-S2`_
ESP32-C3 Yes    Yes         `ESP32-C3`_
ESP32-S3 No     Yes         `ESP32-S3`_
======== ====== =========== ===================================

See `Boards <boards/boards.html>`_ for more details about ESP32 development boards.

Arduino Core Reference
----------------------

This documentation is built on the ESP32 and we are not going to cover the common Arduino API. To see the Arduino reference documentation, 
please consider reading the official documentation.

Arduino Official Documentation: `Arduino Reference`_.

Supported Operating Systems
---------------------------

+-------------------+-------------------+-------------------+
|     |       |       |
+-------------------+-------------------+-------------------+
| Windows           | Linux             | macOS             |
+-------------------+-------------------+-------------------+





Supported IDEs
---------------------------

Here is the list of supported IDE for Arduino ESP32 support integration.

+-------------------+-------------------+
|     |         |
+-------------------+-------------------+
| Arduino IDE       | PlatformIO        |
+-------------------+-------------------+




See `Installing Guides <installing.html>`_ for more details on how to install the Arduino ESP32 support.

Support
-------

This is an open project and it's supported by the community. Fell free to ask for help in one of the community channels.

Community
---------

The Arduino community is huge! You can find a lot of useful content on the Internet.
Here are some community channels where you may find information and ask for some help, if needed.

- `ESP32 Forum`_: Official Espressif Forum.
- `ESP32 Forum - Arduino`_: Official Espressif Forum for Arduino related discussions.
- `ESP32 Forum - Hardware`_: Official Espressif Forum for Hardware related discussions.
- `Gitter`_
- `Espressif MCUs (Discord)`_
- `ESP32 on Reddit`_

Issues Reporting
----------------

Before opening a new issue, please read this: 

Be sure to search for a similar reported issue. This avoids duplicating or creating noise in the GitHub Issues reporting.
We also have the troubleshooting guide to save your time on the most common issues reported by users.

For more details about creating new Issue, see the `Issue Template <https://github.com/espressif/arduino-esp32/blob/master/.github/ISSUE_TEMPLATE/Issue-report.yml>`_.

If you have any new idea, see the `Feature request Template <https://github.com/espressif/arduino-esp32/blob/master/.github/ISSUE_TEMPLATE/Feature-request.yml>`_.

First Steps
-----------

Here are the first steps to get the Arduino ESP32 support running.

To install Arduino-ESP32, please see the dedicated section on the Installation guide. We recommend you install it using the boards manager.

.. toctree::
    :maxdepth: 2
    
    How to Install <installing>
    Development Boards <boards/boards>

Examples
--------

After installing the toolchain into your environment, you will be able to see all the dedicated examples for the ESP32. These examples are located
in the examples menu or inside each library folder.

    https://github.com/espressif/arduino-esp32/tree/master/libraries

.. include:: common/datasheet.inc

Resources
---------

.. _Espressif Systems: https://www.espressif.com 
.. _Espressif Product Selector: https://products.espressif.com/
.. _Arduino.cc: https://www.arduino.cc/en/Main/Software
.. _Arduino Reference: https://www.arduino.cc/reference/en/
.. _ESP32 Forum: https://esp32.com
.. _ESP32 Forum - Arduino: https://esp32.com/viewforum.php?f=19
.. _ESP32 Forum - Hardware: https://esp32.com/viewforum.php?f=12
.. _Gitter: https://gitter.im/espressif/arduino-esp32
.. _Adafruit (Discord): https://discord.gg/adafruit
.. _Espressif MCUs (Discord): https://discord.gg/nKxMTnkD
.. _ESP32 on Reddit: https://www.reddit.com/r/esp32

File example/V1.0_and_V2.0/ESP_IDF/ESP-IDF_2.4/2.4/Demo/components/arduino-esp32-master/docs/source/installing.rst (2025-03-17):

##########
Installing
##########

This guide will show how to install the Arduino-ESP32 support.

Before Installing
-----------------

We recommend you install the support using your favorite IDE, but other options are available depending on your operating system. 
To install Arduino-ESP32 support, you can use one of the following options.

Installing using Arduino IDE
----------------------------



This is the way to install Arduino-ESP32 directly from the Arduino IDE.

.. note::
   For overview of SoC's support, take a look on `Supported Soc's table <https://docs.espressif.com/projects/arduino-esp32/en/latest/getting_started.html#supported-soc-s>`_ where you can find if the particular chip is under stable or development release.

- Stable release link::

   https://raw.githubusercontent.com/espressif/arduino-esp32/gh-pages/package_esp32_index.json

- Development release link::

   https://raw.githubusercontent.com/espressif/arduino-esp32/gh-pages/package_esp32_dev_index.json

.. note::
   Starting with the Arduino IDE version 1.6.4, Arduino allows installation of third-party platform 
   packages using Boards Manager. We have packages available for Windows, macOS, and Linux.

To start the installation process using the Boards Managaer, follow these steps:

-  Install the current upstream Arduino IDE at the 1.8 level or later. The current version is at the `arduino.cc`_ website.

-  Start Arduino and open the Preferences window.



-  Enter one of the release links above into *Additional Board Manager URLs* field. You can add multiple URLs, separating them with commas.



-  Open Boards Manager from Tools > Board menu and install *esp32* platform (and do not forget to select your ESP32 board from Tools > Board menu after installation).



- Restart Arduino IDE.

Installing using PlatformIO
---------------------------



PlatformIO is a professional collaborative platform for embedded development. It has out-of-the-box support for ESP32 SoCs and allows working with Arduino ESP32 as well as ESP-IDF from Espressif without changing your development environment. PlatformIO includes lots of instruments for the most common development tasks such as debugging, unit testing, and static code analysis.

A detailed overview of the PlatformIO ecosystem and its philosophy can be found in `the official documentation <https://docs.platformio.org/en/latest/core/index.html>`_.

PlatformIO can be used in two flavors:

- `PlatformIO IDE <https://platformio.org/platformio-ide>`_ is a toolset for embedded C/C++ development available on Windows, macOS and Linux platforms

- `PlatformIO Core (CLI) <https://docs.platformio.org/en/latest/core/index.html>`_ is a command-line tool that consists of a multi-platform build system, platform and library managers and other integration components. It can be used with a variety of code development environments and allows integration with cloud platforms and web services

To install PlatformIO, you can follow this Getting Started, provided at `docs.platformio.org`_.

Using the stable code
*********************

.. note::
   A detailed overview of supported development boards, examples and frameworks can be found on `the official Espressif32 dev-platform page <https://registry.platformio.org/platforms/platformio/espressif32>`_ in the PlatformIO Registry.

The most reliable and easiest way to get started is to use the latest stable version of the ESP32 development platform that passed all tests/verifications and can be used in production.

Create a new project and select one of the available boards. You can change after by changing the `platformio.ini <https://docs.platformio.org/en/latest/projectconf/index.html>`_ file.

- For ESP32

.. code-block:: bash

   [env:esp32dev]
   platform = espressif32
   board = esp32dev
   framework = arduino

- For ESP32-S2 (ESP32-S2-Saola-1 board)

.. code-block:: bash

   [env:esp32-s2-saola-1]
   platform = espressif32
   board = esp32-s2-saola-1
   framework = arduino

- For ESP32-C3 (ESP32-C3-DevKitM-1 board)

.. code-block:: bash

   [env:esp32-c3-devkitm-1]
   platform = espressif32
   board = esp32-c3-devkitm-1
   framework = arduino

How to update to the latest code
********************************

To test the latest Arduino ESP32, you need to change your project *platformio.ini* accordingly.
The following configuration uses the upstream version of the Espressif development platform and the latest Arduino core directly from the Espressif GitHub repository:

.. code-block:: bash

   [env:esp32-c3-devkitm-1]
   platform = https://github.com/platformio/platform-espressif32.git
   board = esp32-c3-devkitm-1
   framework = arduino
   platform_packages =
       framework-arduinoespressif32 @ https://github.com/espressif/arduino-esp32#master

To get more information about PlatformIO, see the following links:

- `PlatformIO Core (CLI) <https://docs.platformio.org/en/latest/core/index.html>`_

- `PlatformIO Home <https://docs.platformio.org/en/latest/home/index.html>`_

- `Tutorials and Examples <https://docs.platformio.org/en/latest/tutorials/index.html>`_

- `Library Management <https://docs.platformio.org/en/latest/librarymanager/index.html>`_

Windows (manual installation)
-----------------------------

.. warning:: Arduino ESP32 core v2.x.x cannot be used on Windows 8.x x86 (32 bits), Windows 7 or earlier. The Windows 32 bits OS is no longer supported by this toolchain.

   The Arduino ESP32 v1.0.6 still works on WIN32. You might want to install python 3.8.x because it is the latest release supported by Windows 7.

Steps to install Arduino ESP32 support on Windows:

**Step 1**

1. Download and install the latest Arduino IDE ``Windows Installer`` from [arduino.cc](https://www.arduino.cc/en/Main/Software)
2. Download and install Git from [git-scm.com](https://git-scm.com/download/win)
3. Start ``Git GUI`` and do the following steps:

- Select ``Clone Existing Repository``



- Select source and destination
   - Sketchbook Directory: Usually ``C:/Users/[YOUR_USER_NAME]/Documents/Arduino`` and is listed underneath the "Sketchbook location" in Arduino preferences.
   - Source Location: ``https://github.com/espressif/arduino-esp32.git``
   - Target Directory: ``[ARDUINO_SKETCHBOOK_DIR]/hardware/espressif/esp32``
   - Click ``Clone`` to start cloning the repository

**Step 2**



**Step 3**



- open a `Git Bash` session pointing to ``[ARDUINO_SKETCHBOOK_DIR]/hardware/espressif/esp32`` and execute ```git submodule update --init --recursive``` 
- Open ``[ARDUINO_SKETCHBOOK_DIR]/hardware/espressif/esp32/tools`` and double-click ``get.exe``

**Step 4**



- When ```get.exe``` finishes, you should see the following files in the directory

**Step 5**



1. Plug your ESP32 board and wait for the drivers to install (or install manually any that might be required)
2. Start Arduino IDE
3. Select your board in ``Tools > Board`` menu
4. Select the COM port that the board is attached to
5. Compile and upload (You might need to hold the boot button while uploading)



How to update to the latest code
********************************

1. Start ``Git GUI`` and you should see the repository under ``Open Recent Repository``. Click on it!



1. From menu ``Remote`` select ``Fetch from`` > ``origin``



1. Wait for git to pull any changes and close ``Git GUI``
2. Open ``[ARDUINO_SKETCHBOOK_DIR]/hardware/espressif/esp32/tools`` and double-click ``get.exe``



Linux
-----



Debian/Ubuntu
*************

- Install latest Arduino IDE from `arduino.cc`_.

- Open Terminal and execute the following command (copy -> paste and hit enter):

.. code-block:: bash

   sudo usermod -a -G dialout $USER && \
   sudo apt-get install git && \
   wget https://bootstrap.pypa.io/get-pip.py && \
   sudo python3 get-pip.py && \
   sudo pip3 install pyserial && \
   mkdir -p ~/Arduino/hardware/espressif && \
   cd ~/Arduino/hardware/espressif && \
   git clone https://github.com/espressif/arduino-esp32.git esp32 && \
   cd esp32/tools && \
   python3 get.py

- Restart Arduino IDE.

- If you have Arduino installed to ~/, modify the installation as follows, beginning at `mkdir -p ~/Arduino/hardware`:

.. code-block:: bash

   cd ~/Arduino/hardware
   mkdir -p espressif && \
   cd espressif && \
   git clone https://github.com/espressif/arduino-esp32.git esp32 && \
   cd esp32/tools && \
   python3 get.py

Fedora
******

- Install the latest Arduino IDE from `arduino.cc`_.

.. note::
   Command ``$ sudo dnf -y install arduino`` will most likely install an older release.

- Open Terminal and execute the following command (copy -> paste and hit enter):

.. code-block:: bash

   sudo usermod -a -G dialout $USER && \
   sudo dnf install git python3-pip python3-pyserial && \
   mkdir -p ~/Arduino/hardware/espressif && \
   cd ~/Arduino/hardware/espressif && \
   git clone https://github.com/espressif/arduino-esp32.git esp32 && \
   cd esp32/tools && \
   python get.py

- Restart Arduino IDE.

openSUSE
********

- Install the latest Arduino IDE from `arduino.cc`_.

- Open Terminal and execute the following command (copy -> paste and hit enter):

.. code-block:: bash

   sudo usermod -a -G dialout $USER && \
   if [ `python --version 2>&1 | grep '2.7' | wc -l` = "1" ]; then \
   sudo zypper install git python-pip python-pyserial; \
   else \
   sudo zypper install git python3-pip python3-pyserial; \
   fi && \
   mkdir -p ~/Arduino/hardware/espressif && \
   cd ~/Arduino/hardware/espressif && \
   git clone https://github.com/espressif/arduino-esp32.git esp32 && \
   cd esp32/tools && \
   python get.py

- Restart Arduino IDE.

macOS
-----

- Install the latest Arduino IDE from `arduino.cc`_.

- Open Terminal and execute the following command (copy -> paste and hit enter):

.. code-block:: bash

   mkdir -p ~/Documents/Arduino/hardware/espressif && \
   cd ~/Documents/Arduino/hardware/espressif && \
   git clone https://github.com/espressif/arduino-esp32.git esp32 && \
   cd esp32/tools && \
   python get.py 

Where ``~/Documents/Arduino`` represents your sketch book location as per "Arduino" > "Preferences" > "Sketchbook location" (in the IDE once started). Adjust the command above accordingly.

- If you get the error below, install through the command line dev tools with `xcode-select --install` and try the command above again:

.. code-block:: bash

   xcrun: error: invalid active developer path (/Library/Developer/CommandLineTools), missing xcrun at: /Library/Developer/CommandLineTools/usr/bin/xcrun

- Run the command:

.. code-block:: bash

   xcode-select --install

- Try ``python3`` instead of ``python`` if you get the error: ``IOError: [Errno socket error] [SSL: TLSV1_ALERT_PROTOCOL_VERSION] tlsv1 alert protocol version (_ssl.c:590)`` when running ``python get.py``

- If you get the following error when running ``python get.py`` urllib.error.URLError: <urlopen error SSL: CERTIFICATE_VERIFY_FAILED, go to Macintosh HD > Applications > Python3.6 folder (or any other python version), and run the following scripts: Install Certificates.command and Update Shell Profile.command

- Restart Arduino IDE.

.. _Arduino.cc: https://www.arduino.cc/en/Main/Software
.. _docs.platformio.org: https://docs.platformio.org/en/latest/integration/ide/pioide.html

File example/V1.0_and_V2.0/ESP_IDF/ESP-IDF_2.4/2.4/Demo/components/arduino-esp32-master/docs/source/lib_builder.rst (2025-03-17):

###############
Library Builder
###############

About
-----

Espressif provides a `tool <https://github.com/espressif/esp32-arduino-lib-builder>`_ to simplify building your own compiled libraries for use in Arduino IDE (or your favorite IDE).

This tool can be used to change the project or a specific configuration according to your needs.

Installing
----------

To install the Library Builder into your environment, please, follow the instructions below.

- Clone the ESP32 Arduino lib builder:

.. code-block:: bash

    git clone https://github.com/espressif/esp32-arduino-lib-builder

- Go to the ``esp32-arduino-lib-builder`` folder:

.. code-block:: bash

    cd esp32-arduino-lib-builder

- Build:

.. code-block:: bash

    ./build.sh

If everything works, you may see the following message: ``Successfully created esp32 image.``

Dependencies
************

To build the library you will need to install some dependencies. Maybe you already have installed it, but it is a good idea to check before building.

- Install all dependencies (**Ubuntu**):

.. code-block:: bash

    sudo apt-get install git wget curl libssl-dev libncurses-dev flex bison gperf cmake ninja-build ccache jq

- Install Python and upgrade pip:

.. code-block:: bash

    sudo apt-get install python3
    sudo pip install --upgrade pip

- Install all required packages:

.. code-block:: bash

    pip install --user setuptools pyserial click cryptography future pyparsing pyelftools

Building
--------

If you have all the dependencies met, it is time to build the libraries.

To build using the default configuration:

.. code-block:: bash

    ./build.sh

Custom Build
************

There are some options to help you create custom libraries. You can use the following options:

Usage
^^^^^

.. code-block:: bash

    build.sh [-s] [-A arduino_branch] [-I idf_branch] [-i idf_commit] [-c path] [-t <target>] [-b <build|menuconfig|idf_libs|copy_bootloader|mem_variant>] [config ...]

Skip Install/Update
^^^^^^^^^^^^^^^^^^^

Skip installing/updating of ESP-IDF and all components

.. code-block:: bash

    ./build.sh -s

This option can be used if you already have the ESP-IDF and all components already in your environment.

Set Arduino-ESP32 Branch
^^^^^^^^^^^^^^^^^^^^^^^^

Set which branch of arduino-esp32 to be used for compilation

.. code-block:: bash

    ./build.sh -A <arduino_branch>

Set ESP-IDF Branch
^^^^^^^^^^^^^^^^^^

Set which branch of ESP-IDF is to be used for compilation

.. code-block:: bash

    ./build.sh -I <idf_branch>

Set the ESP-IDF Commit
^^^^^^^^^^^^^^^^^^^^^^

Set which commit of ESP-IDF to be used for compilation

.. code-block:: bash

    ./build.sh -i <idf_commit>

Deploy
^^^^^^

Deploy the build to github arduino-esp32

.. code-block:: bash

    ./build.sh -d

Set the Arduino-ESP32 Destination Folder
^^^^^^^^^^^^^^^^^^^^^^^^^^^^^^^^^^^^^^^^

Set the arduino-esp32 folder to copy the result to. ex. '$HOME/Arduino/hardware/espressif/esp32'

.. code-block:: bash

    ./build.sh -c <path>

This function is used to copy the compiled libraries to the Arduino folder.

Set the Target
^^^^^^^^^^^^^^

Set the build target(chip). ex. 'esp32s3'

.. code-block:: bash

    ./build.sh -t <target>

This build command will build for the ESP32-S3 target. You can specify other targets.

* esp32
* esp32s2
* esp32c3
* esp32s3

Set Build Type
^^^^^^^^^^^^^^

Set the build type. ex. 'build' to build the project and prepare for uploading to a board.

.. note:: This command depends on the ``-t`` argument.

.. code-block:: bash

    ./build.sh -t esp32 -b <build|menuconfig|idf_libs|copy_bootloader|mem_variant>

Additional Configuration
^^^^^^^^^^^^^^^^^^^^^^^^

Specify additional configs to be applied. ex. 'qio 80m' to compile for QIO Flash@80MHz. Requires -b

.. note:: This command requires the ``-b`` to work properly.

.. code-block:: bash

    ./build.sh -t esp32 -b idf_libs qio 80m

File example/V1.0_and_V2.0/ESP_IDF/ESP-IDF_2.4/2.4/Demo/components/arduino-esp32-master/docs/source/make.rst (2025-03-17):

==============
makeEspArduino
==============

The `makeEspArduino <https://github.com/plerup/makeEspArduino>`_ is a generic makefile for any ESP8266/ESP32 Arduino project. 
Using it instead of the Arduino IDE makes it easier to do automated and production builds.

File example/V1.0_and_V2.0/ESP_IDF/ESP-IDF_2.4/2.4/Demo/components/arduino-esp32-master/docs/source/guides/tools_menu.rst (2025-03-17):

######################
Arduino IDE Tools Menu
######################

Introduction
------------

This guide is a walkthrough of the Arduino IDE configuration menu for the ESP32 System on Chip (SoC's). In this guide, you will see the most relevant configuration
to get your project optimized and working.

Since some boards and SoC's may vary in terms of hardware configuration, be sure you know all the board characteristics that you are using, like flash memory size, SoC variant (ESP32 family), PSRAM, etc.

.. note:: To help you identify the characteristics, you can see the `Espressif Product Selector`_.

Arduino IDE
-----------

The Arduino IDE is widely used for ESP32 on Arduino development and offers a wide variety of configurations.

Tools Menu
----------

To properly configure your project build and flash, some settings must be done in order to get it compiled and flashed without any issues.
Some boards are natively supported and almost no configuration is required. However, if your is not yet supported or you have a custom board, you need to configure the environment by yourself.

For more details or to add a new board, see the `boards.txt`_ file.

Generic Options
---------------

Most of the options are available for every ESP32 family. Some options will be available only for specific targets, like the USB configuration.

Board
*****

This option is the target board and must be selected in order to get all the default configuration settings. Once you select the correct board, you will see that some configurations will be automatically selected, but be aware that some boards can have multiple versions (i.e different flash sizes).

To select the board, go to ``Tools -> Board -> ESP32 Arduino`` and select the target board.

If your board is not present on this list, you can select the generic ``ESP32-XX Dev Module``.

Currently, we have one generic development module for each of the supported targets.

If the board selected belongs to another SoC family, you will see the following information at the build output:

    ``A fatal error occurred: This chip is ESP32 not ESP32-S2. Wrong --chip argument?``

Upload Speed
************

To select the flashing speed, change the ``Tools -> Upload Speed``. This value will be used for flashing the code to the device.

.. note:: If you have issues while flashing the device at high speed, try to decrease this value. This could be due to the external serial-to-USB chip limitations.

CPU Frequency
*************

On this option, you can select the CPU clock frequency. This option is critical and must be selected according to the high-frequency crystal present on the board and the radio usage (Wi-Fi and Bluetooth).

In some applications, reducing the CPU clock frequency is recommended in order to reduce power consumption.

If you don't know why you should change this frequency, leave the default option.

Flash Frequency
***************

Use this function to select the flash memory frequency. The frequency will be dependent on the memory model.

* **40MHz**
* **80MHz**

If you don't know if your memory supports **80Mhz**, you can try to upload the sketch using the **80MHz** option and watch the log output via the serial monitor.

.. note:: In some boards/SoC, the flash frequency is automatically selected according to the flash mode. In some cases (i.e ESP32-S3), the flash frequency is up to 120MHz.

Flash Mode
**********

This option is used to select the SPI communication mode with the flash memory.

Depending on the application, this mode can be changed in order to increase the flash communication speed.

* **QIO** - Quad I/O Fast Read
    * Four SPI pins are used to write to the flash and to read from the flash.

* **DIO** - Dual I/O Fast Read
    * Two SPI pins are used to write to the flash and to read from the flash.

* **QOUT** - Quad Output Fast Read
    * Four SPI pins are used to read the flash data.

* **DOUT** - Dual Output Fast Read
    * Two SPI pins are used to read flash data.

* **OPI** - Octal I/O
    * Eight SPI pins are used to write and to read from the flash.

If you don't know how the board flash is physically connected or the flash memory model, try the **QIO** at **80MHz** first.

Flash Size
**********

This option is used to select the flash size. The flash size should be selected according to the flash model used on your board.

* **2MB** (16Mb)
* **4MB** (32Mb)
* **8MB** (64Mb)
* **16MB** (128Mb)

If you choose the wrong size, you may have issues when selecting the partition scheme.

Embedded Flash
^^^^^^^^^^^^^^

Some SoC has embedded flash. The ESP32-S3 is a good example.

.. note:: Check the manufacturer part number of your SoC/module to see the right version.

Example: **ESP32-S3FH4R2**

This particular ESP32-S3 variant comes with 4MB Flash and 2MB PSRAM.

**Options for Embedded Flash**

* **Fx4** 4MB Flash (*QIO*)
* **Fx8** 8MB Flash (*QIO*)
* **V** 1.8V SPI

The **x** stands for the temperature range specification.

* **H** High Temperature (*-40 to 85ºC*)
* **N** Low Temeprature (*-40 to 65ºC*)

For more details, please see the corresponding datasheet at `Espressif Product Selector`_.

Partition Scheme
****************

This option is used to select the partition model according to the flash size and the resources needed, like storage area and OTA (Over The Air updates).

.. note:: Be careful selecting the right partition according to the flash size. If you select the wrong partition, the system will crash.

Core Debug Level
****************

This option is used to select the Arduino core debugging level to be printed to the serial debug.

* **None** - Prints nothing.
* **Error** - Only at error level.
* **Warning** - Only at warning level and above.
* **Info** - Only at info level and above.
* **Debug** - Only at debug level and above.
* **Verbose** - Prints everything.

PSRAM
*****

The PSRAM is an internal or external extended RAM present on some boards, modules or SoC.

This option can be used to ``Enable`` or ``Disable`` PSRAM. In some SoCs, you can select the PSRAM mode as the following.

* **QSPI PSRAM** - Quad PSRAM
* **OPI PSRAM** - Octal PSRAM

Embedded PSRAM
^^^^^^^^^^^^^^

Some SoC has embedded PSRAM. The ESP32-S3 is a good example.

Example: **ESP32-S3FH4R2**

This particular ESP32-S3 comes with 4MB Flash and 2MB PSRAM.

**Options for Embedded Flash and PSRAM**

* **R2** 2MB PSRAM (*QSPI*)
* **R8** 8MB PSRAM (*OPI*)
* **V** 1.8V SPI

The **x** stands for the temperature range specification.

* **H** High Temperature (*-40 to 85ºC*)
* **N** Low Temeprature (*-40 to 65ºC*)

For more details, please see the corresponding datasheet at `Espressif Product Selector`_.

Arduino Runs On
***************

This function is used to select the core that runs the Arduino core. This is only valid if the target SoC has 2 cores.

When you have some heavy task running, you might want to run this task on a different core than the Arduino tasks. For this reason, you have this configuration to select the right core.

Events Run On
*************

This function is also used to select the core that runs the Arduino events. This is only valid if the target SoC has 2 cores.

Port
****

This option is used to select the serial port to be used on the flashing and monitor.

USB Options
-----------

Some ESP32 families have a USB peripheral. This peripheral can be used for flashing and debugging.

To see the supported list for each SoC, see this section: `Libraries <../libraries.html>`_.

The USB option will be available only if the correct target is selected.

USB CDC On Boot
***************

The USB Communications Device Class, or USB CDC, is a class used for basic communication to be used as a regular serial controller (like RS-232).

This class is used for flashing the device without any other external device attached to the SoC.

This option can be used to ``Enable`` or ``Disable`` this function at the boot. If this option is ``Enabled``, once the device is connected via USB, one new serial port will appear in the list of the serial ports.
Use this new serial port for flashing the device.

This option can be used as well for debugging via the ``Serial Monitor`` using **CDC** instead of the **UART0**.

To use the UART as serial output, you can use ``Serial0.print("Hello World!");`` instead of ``Serial.print("Hello World!");`` which will be printed using USB CDC.

USB Firmware MSC On Boot
************************

The USB Mass Storage Class, or USB MSC, is a class used for storage devices, like a USB flash drive.

This option can be used to ``Enable`` or ``Disable`` this function at the boot. If this option is ``Enabled``, once the device is connected via USB, one new storage device will appear in the system as a storage drive.
Use this new storage drive to write and read files or to drop a new firmware binary to flash the device.

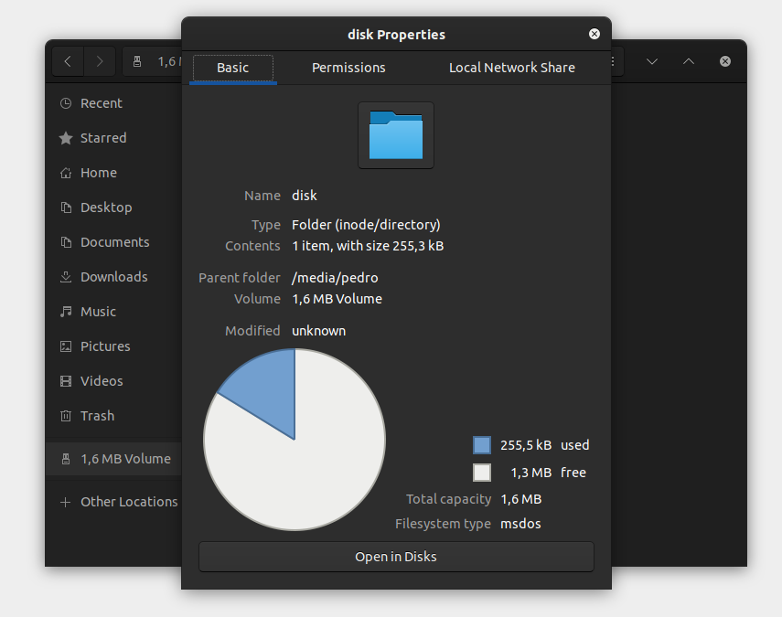
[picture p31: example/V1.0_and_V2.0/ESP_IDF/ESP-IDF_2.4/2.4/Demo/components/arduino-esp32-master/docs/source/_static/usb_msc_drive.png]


USB DFU On Boot
***************

The USB Device Firmware Upgrade is a class used for flashing the device through USB.

This option can be used to ``Enable`` or ``Disable`` this function at the boot. If this option is ``Enabled``, once the device is connected via USB, the device will appear as a USB DFU capable device.

.. _Espressif Product Selector: https://products.espressif.com/
.. _boards.txt: https://github.com/espressif/arduino-esp32/blob/master/boards.txt

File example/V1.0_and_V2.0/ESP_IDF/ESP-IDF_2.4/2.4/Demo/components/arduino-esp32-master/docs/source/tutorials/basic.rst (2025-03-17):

##############
Basic Tutorial
##############

Introduction
------------

This is the basic tutorial and should be used as template for other tutorials.

Requirements
------------

* Arduino IDE
* ESP32 Board
* Good USB Cable

Steps
-----

Here are the steps for this tutorial.

1. Open the Arduino IDE

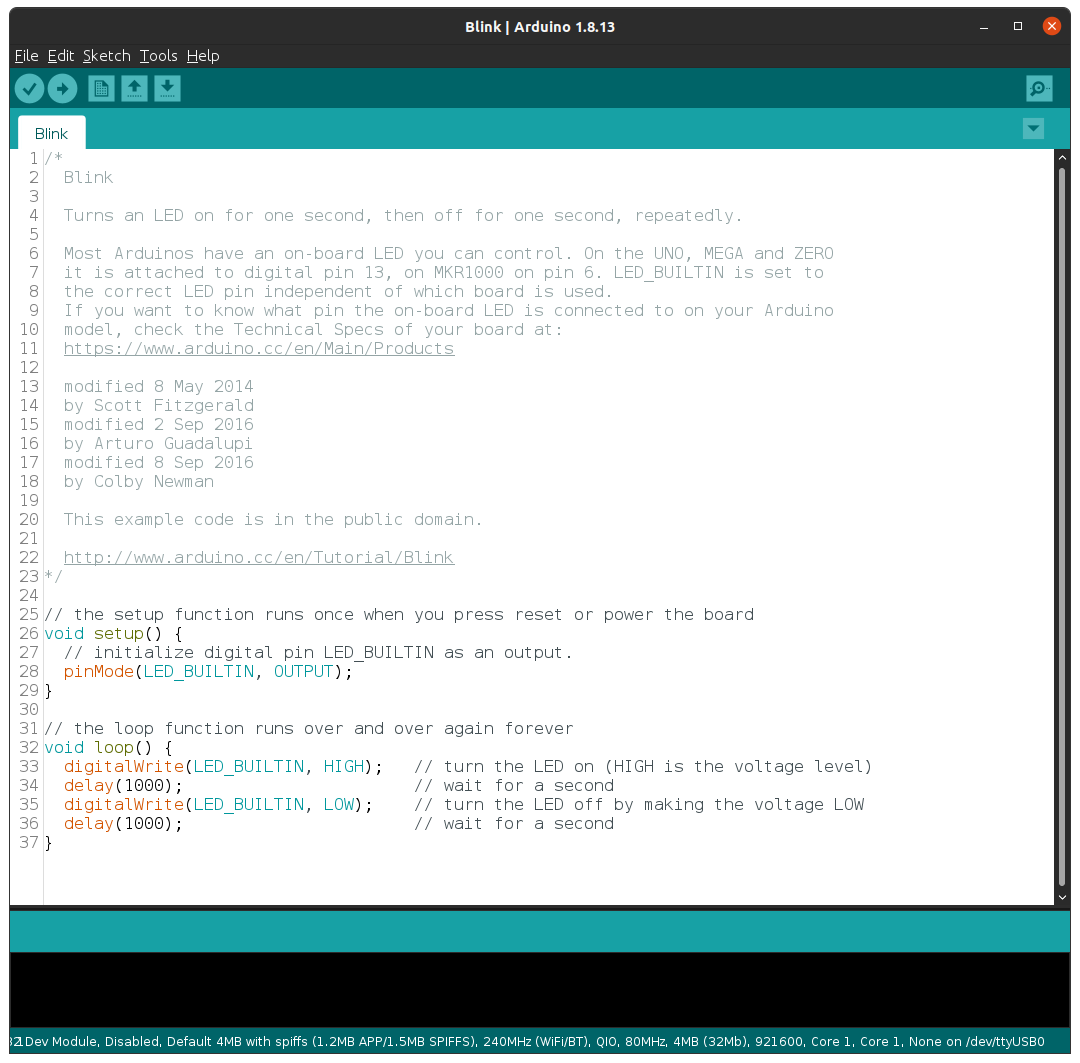
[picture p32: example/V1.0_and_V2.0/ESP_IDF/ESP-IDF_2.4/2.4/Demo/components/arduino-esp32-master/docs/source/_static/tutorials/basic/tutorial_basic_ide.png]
Arduino IDE (click to enlarge)


2. Build and Flash the `blink` project.

Code
----

.. code-block:: arduino
    :caption: Blink.ino

    /*
    Blink

    Turns an LED on for one second, then off for one second, repeatedly.

    Most Arduinos have an on-board LED you can control. On the UNO, MEGA and ZERO
    it is attached to digital pin 13, on MKR1000 on pin 6. LED_BUILTIN is set to
    the correct LED pin independent of which board is used.
    If you want to know what pin the on-board LED is connected to on your Arduino
    model, check the Technical Specs of your board at:
    https://www.arduino.cc/en/Main/Products

    modified 8 May 2014
    by Scott Fitzgerald
    modified 2 Sep 2016
    by Arturo Guadalupi
    modified 8 Sep 2016
    by Colby Newman

    This example code is in the public domain.

    http://www.arduino.cc/en/Tutorial/Blink
    */

    // the setup function runs once when you press reset or power the board
    void setup() {
    // initialize digital pin LED_BUILTIN as an output.
    pinMode(LED_BUILTIN, OUTPUT);
    }

    // the loop function runs over and over again forever
    void loop() {
    digitalWrite(LED_BUILTIN, HIGH);   // turn the LED on (HIGH is the voltage level)
    delay(1000);                       // wait for a second
    digitalWrite(LED_BUILTIN, LOW);    // turn the LED off by making the voltage LOW
    delay(1000);                       // wait for a second
    }

Log Output
----------

If the log output from the serial monitor is relevant, please add here:

.. code-block::

    I (0) cpu_start: App cpu up.
    I (418) cpu_start: Pro cpu start user code
    I (418) cpu_start: cpu freq: 160000000

Resources
---------

* `ESP32 Datasheet`_ (Datasheet)

.. _ESP32 Datasheet: https://www.espressif.com/sites/default/files/documentation/esp32_datasheet_en.pdf

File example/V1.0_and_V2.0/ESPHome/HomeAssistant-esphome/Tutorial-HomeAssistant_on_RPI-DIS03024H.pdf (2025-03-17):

# HOMEASSISTANT---ESPHOME

## DIS03024H

### 1. Go to https://www.home-assistant.io/

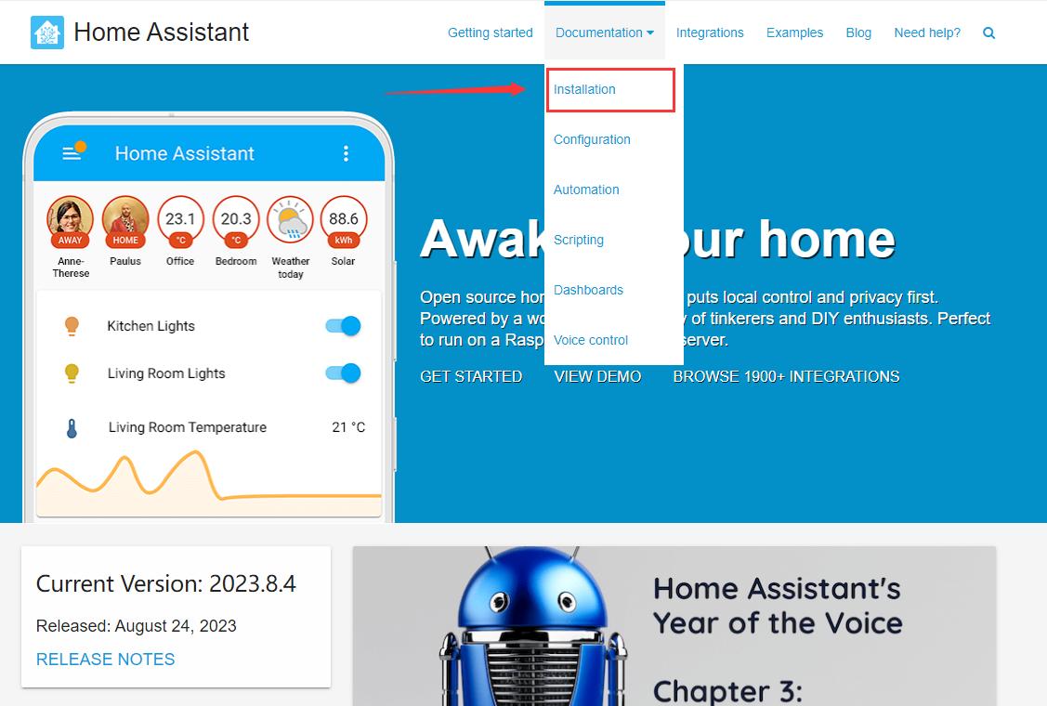
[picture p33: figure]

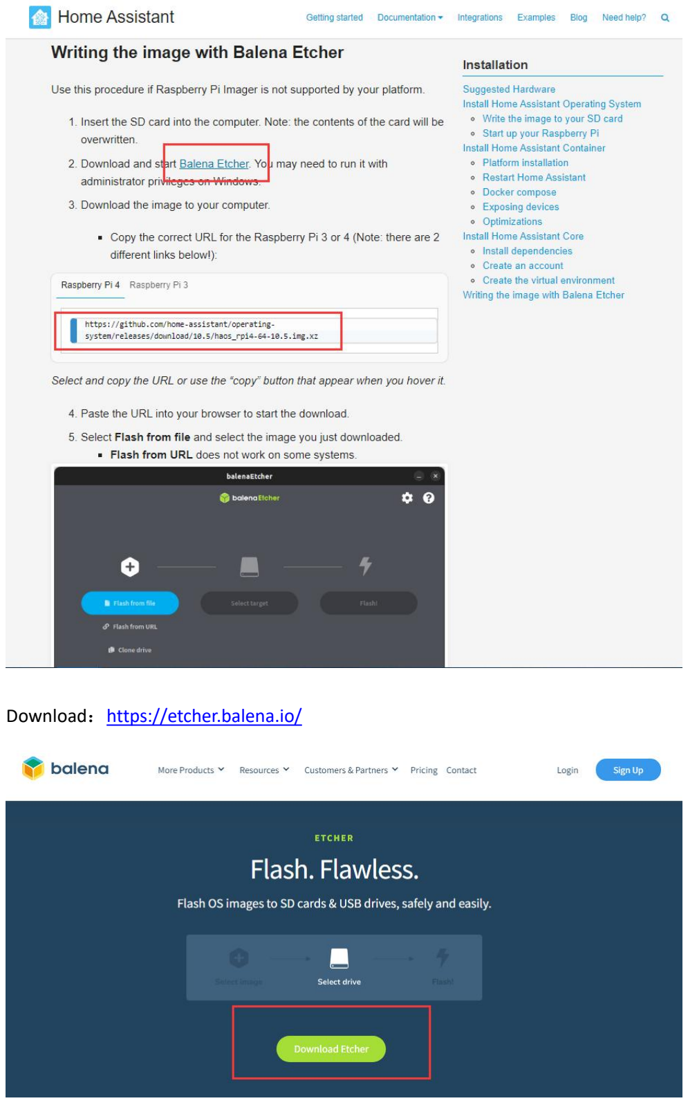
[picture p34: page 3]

Download：https://etcher.balena.io/

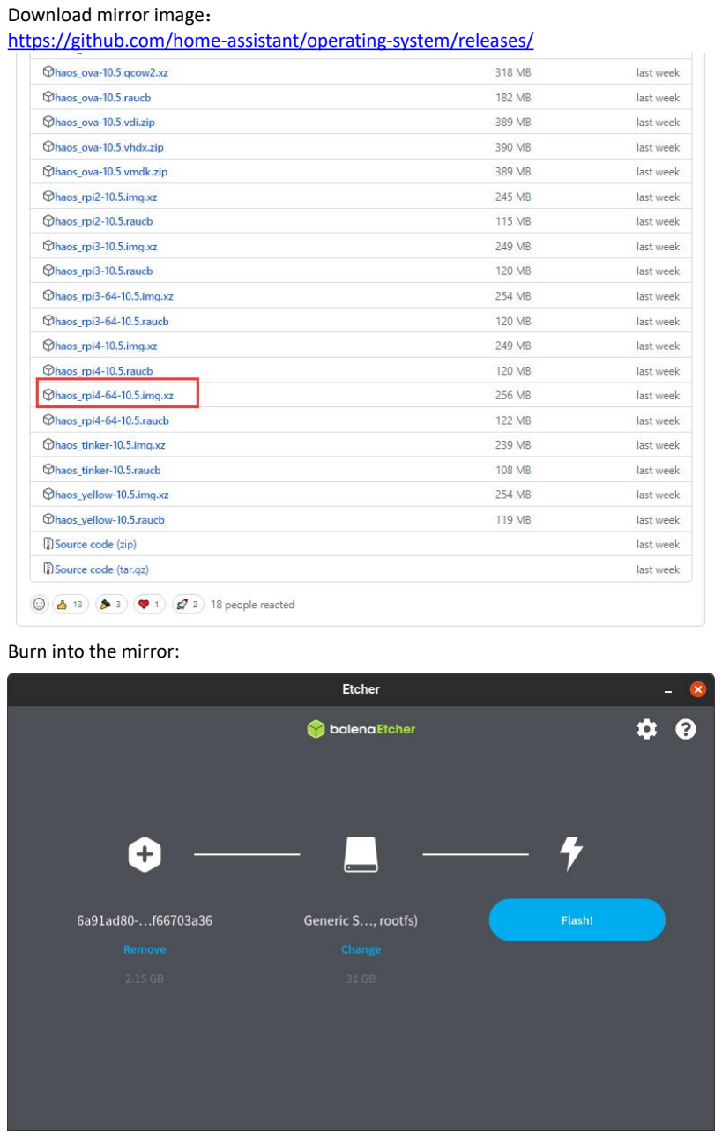
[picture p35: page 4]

Download mirror image：
https://github.com/home-assistant/operating-system/releases/

Burn into the mirror:

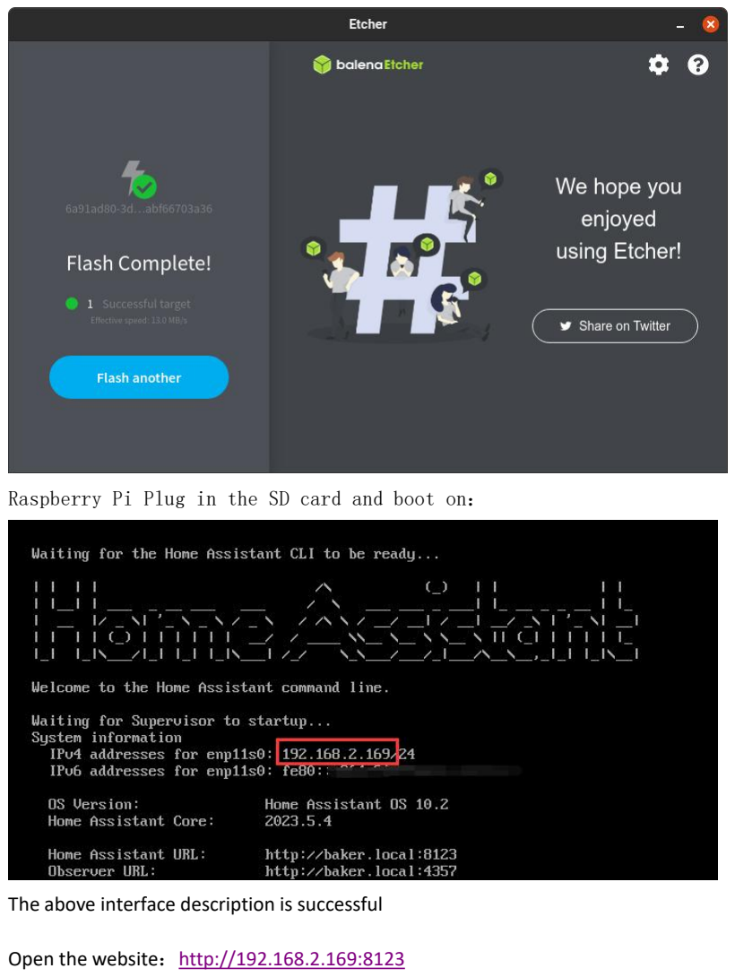
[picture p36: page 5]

Raspberry Pi Plug in the SD card and boot on：

The above interface description is successful

Open the website：http://192.168.2.169:8123

The following interface appears after setting the account and password：

Start downloading and installing the ESPHOME

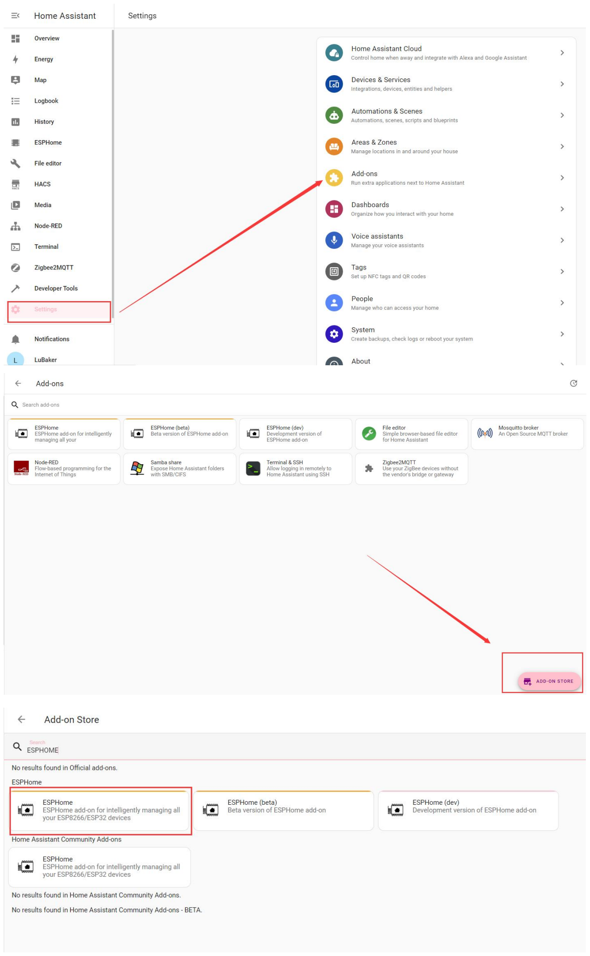
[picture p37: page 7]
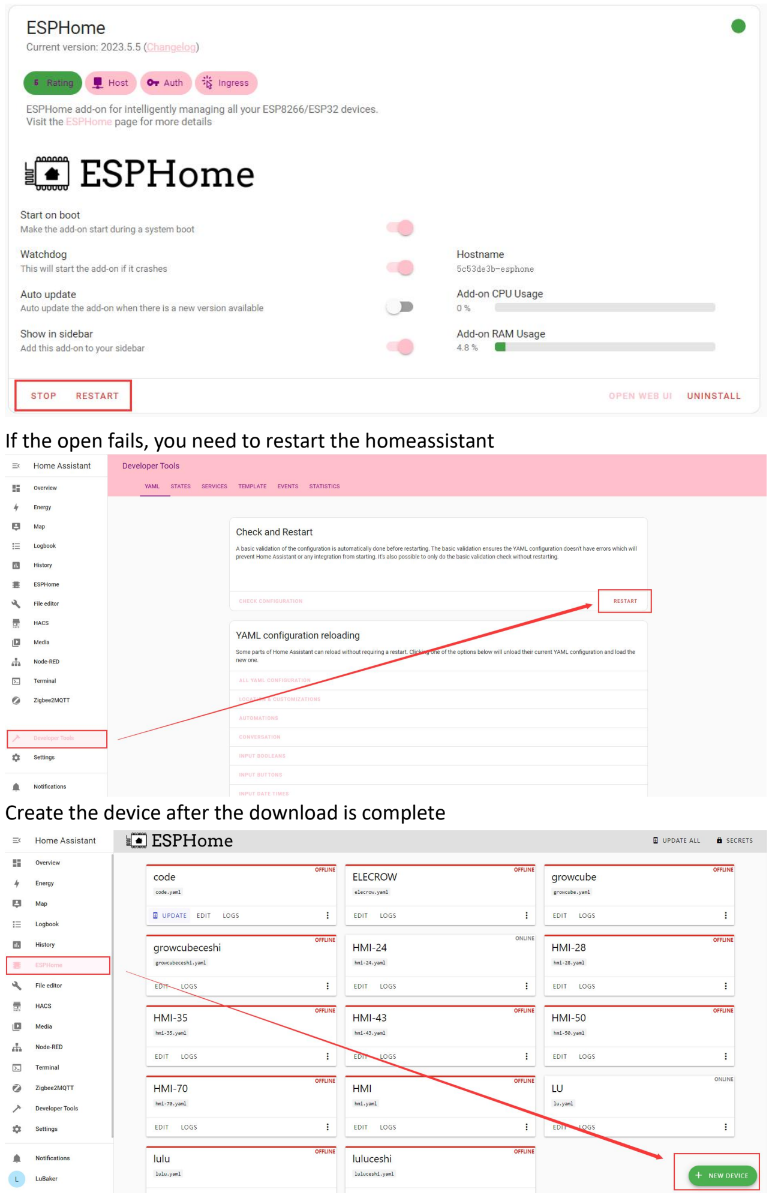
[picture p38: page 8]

If the open fails, you need to restart the homeassistant

Create the device after the download is complete

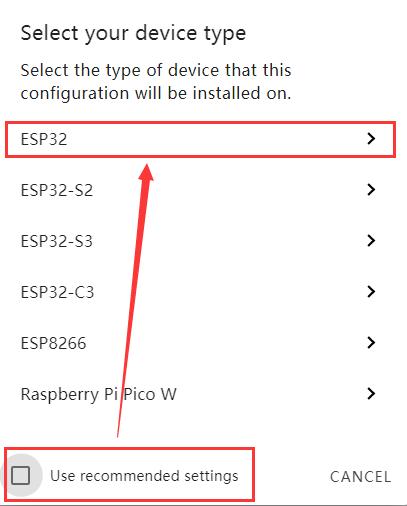
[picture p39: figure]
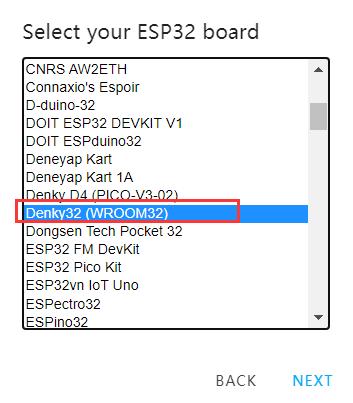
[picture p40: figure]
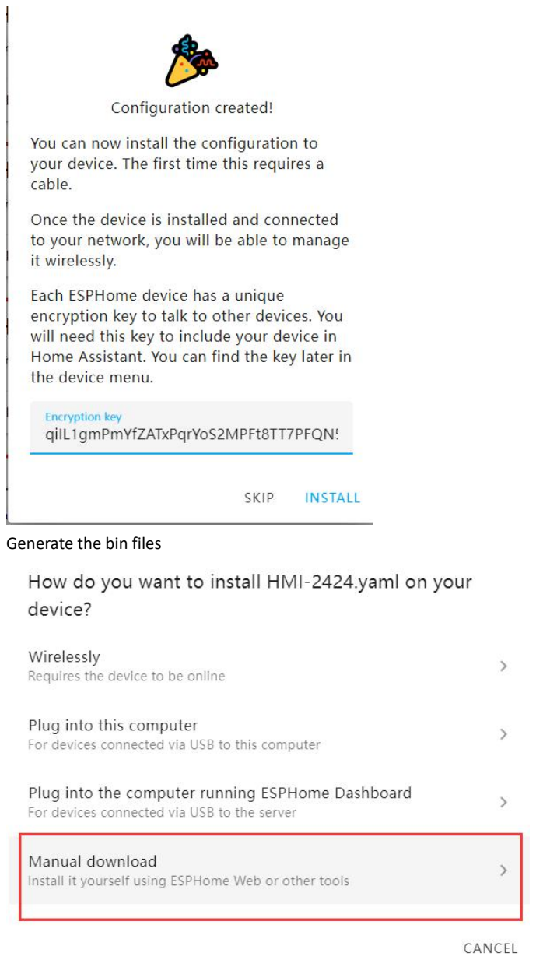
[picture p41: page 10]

Generate the bin files

Open the website:https://web.esphome.io/?dashboard_wizard

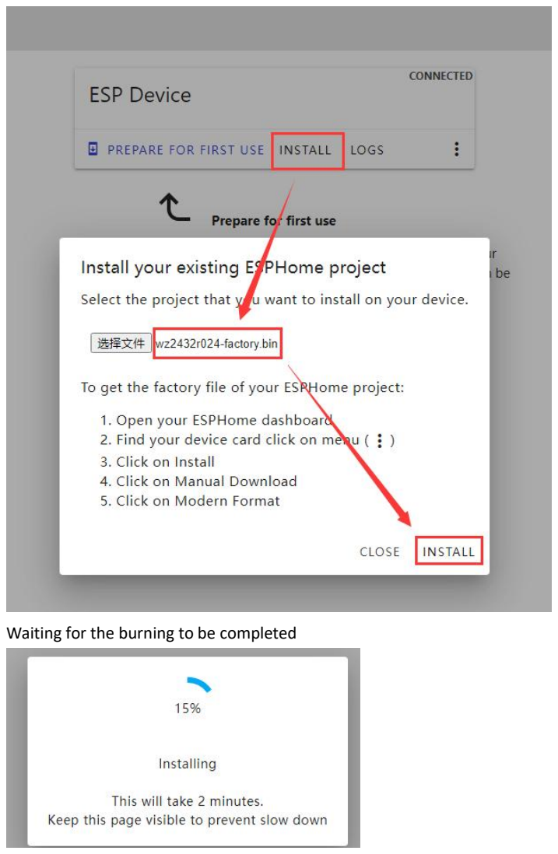
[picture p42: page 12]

Waiting for the burning to be completed

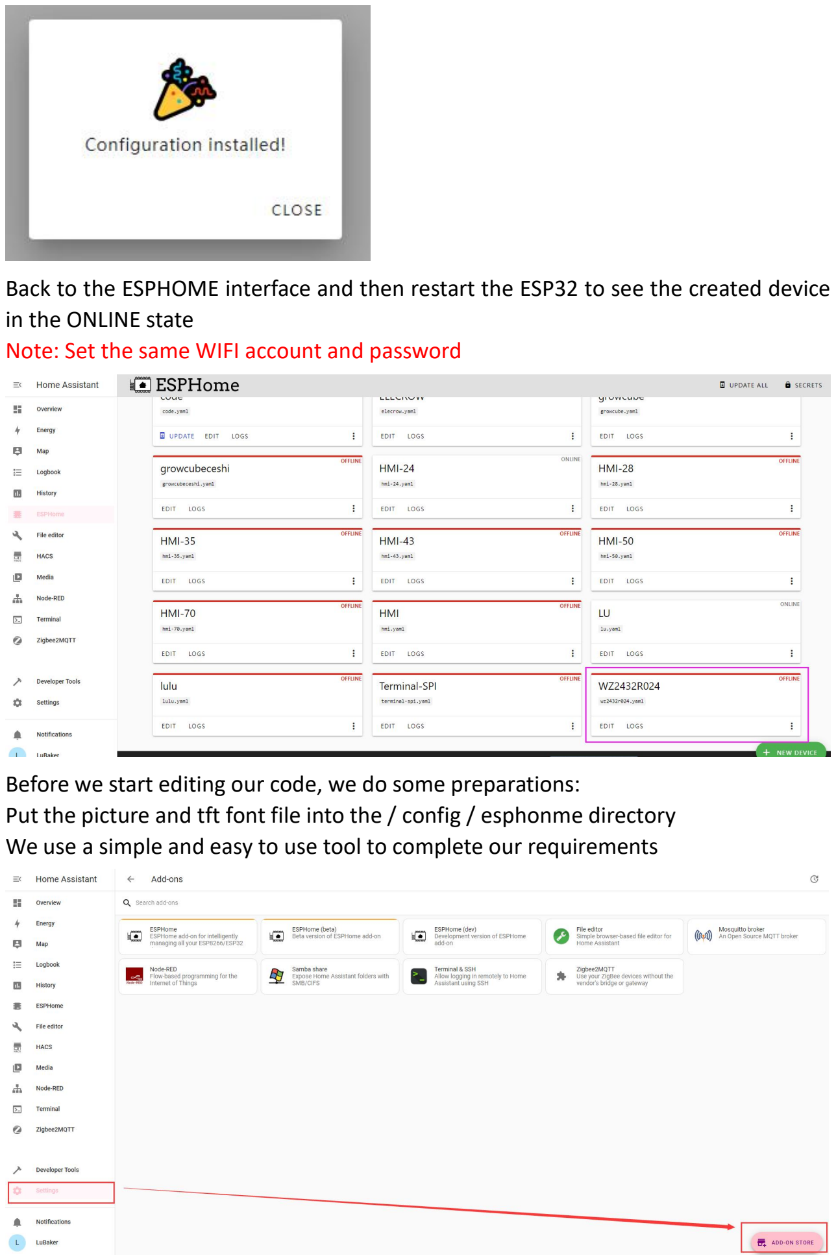
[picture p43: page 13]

Back to the ESPHOME interface and then restart the ESP32 to see the created device in the ONLINE state
Note: Set the same WIFI account and password

Before we start editing our code, we do some preparations:
Put the picture and tft font file into the / config / esphonme directory We use a simple and easy to use tool to complete our requirements

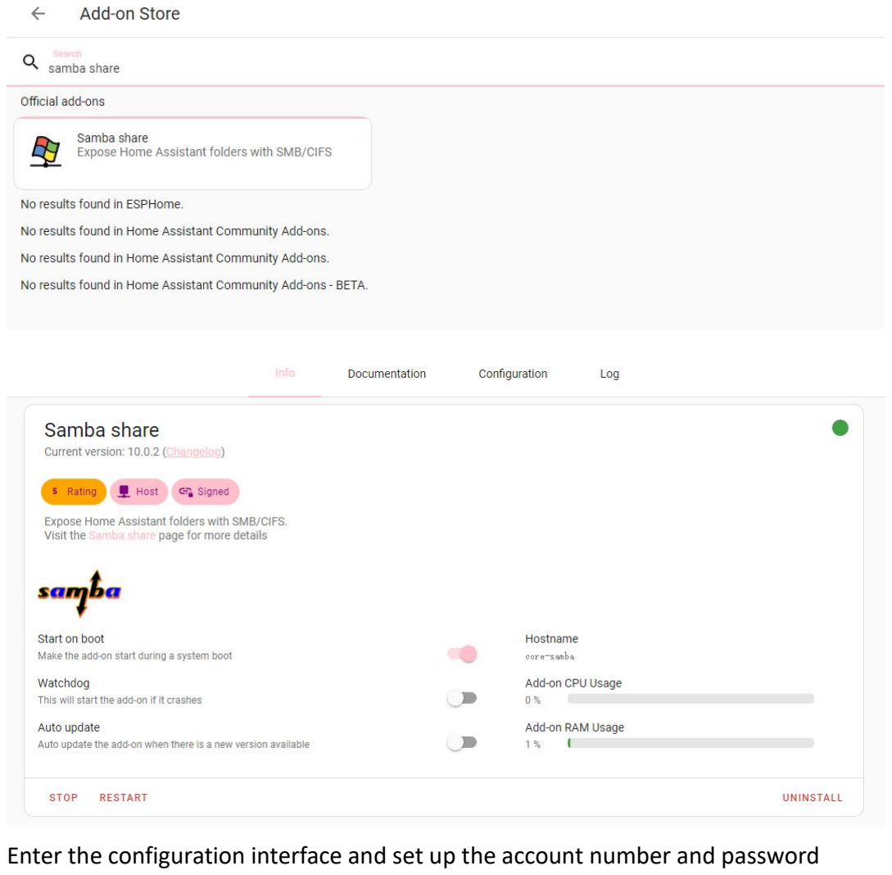
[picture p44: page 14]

Enter the configuration interface and set up the account number and password

Then open my computer input \\192.168.2.169 and display the following interface, and then we enter the / config / esphome directory

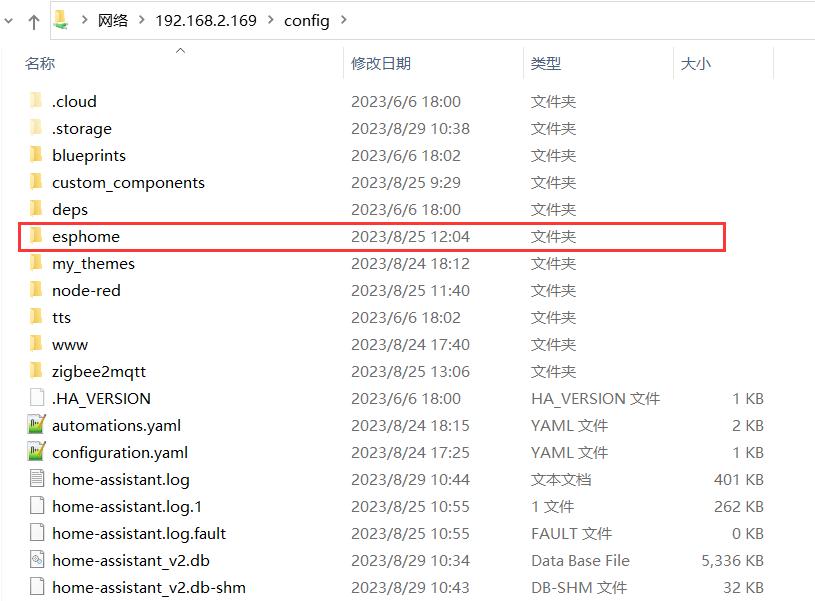
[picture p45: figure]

Put the following files into the folder

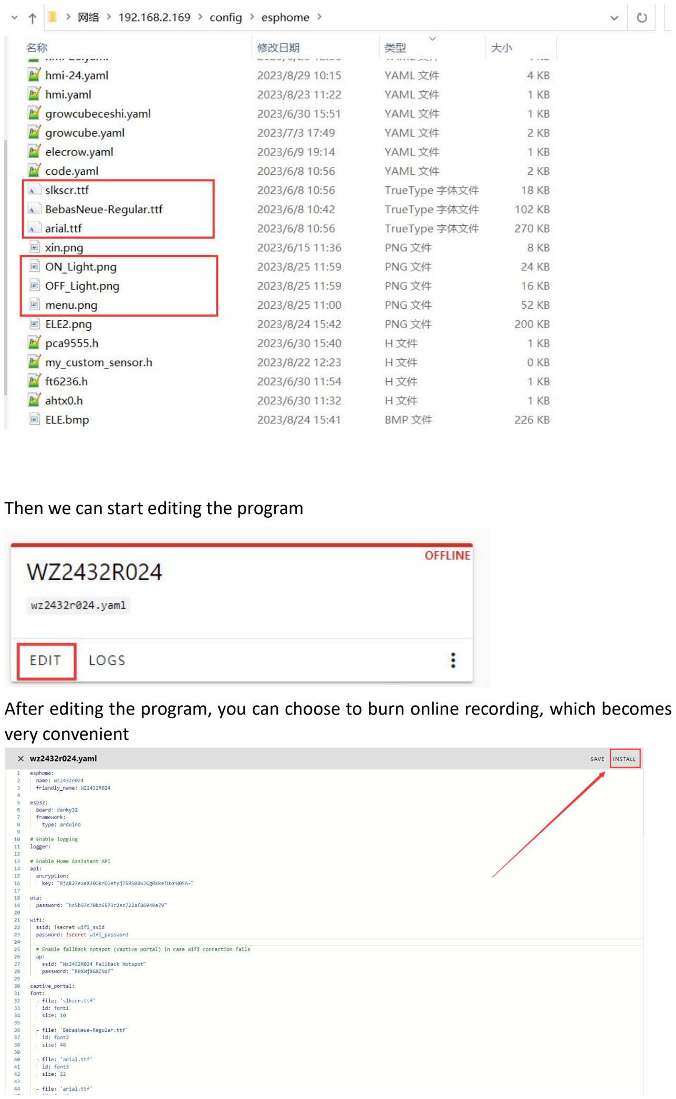
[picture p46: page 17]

Then we can start editing the program

After editing the program, you can choose to burn online recording, which becomes very convenient

Successful burning:

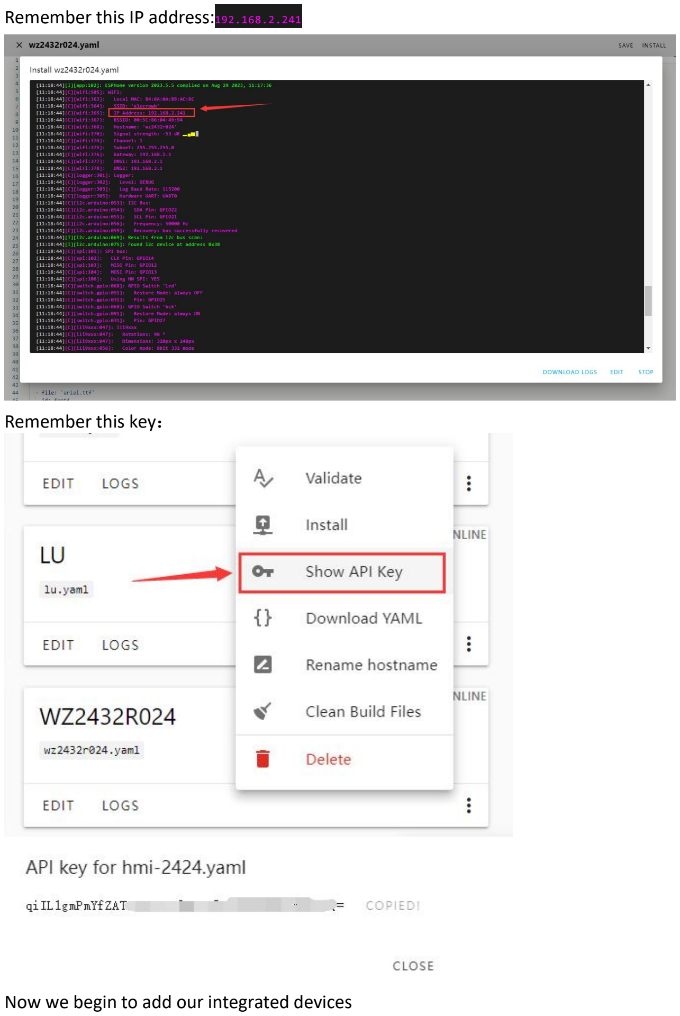
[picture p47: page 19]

Remember this IP address:192.168.2.241

Remember this key：

Now we begin to add our integrated devices

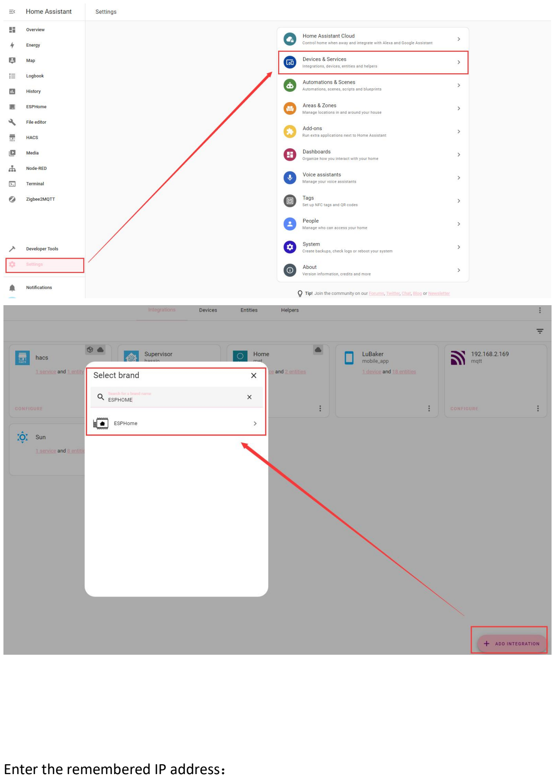
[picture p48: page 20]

Enter the remembered IP address：

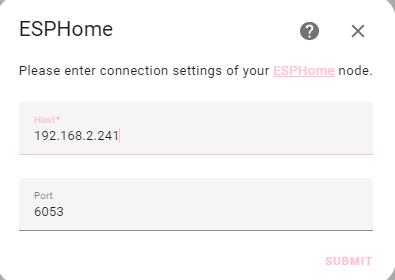
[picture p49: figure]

Enter the remembered key：

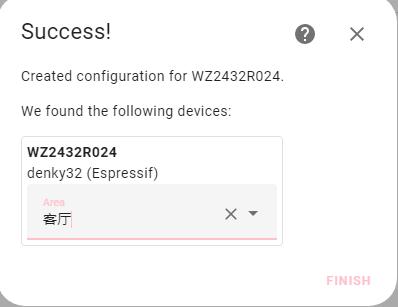
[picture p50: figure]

After completion, we can see that our device was added successfully：

You can see the entities we created inside：

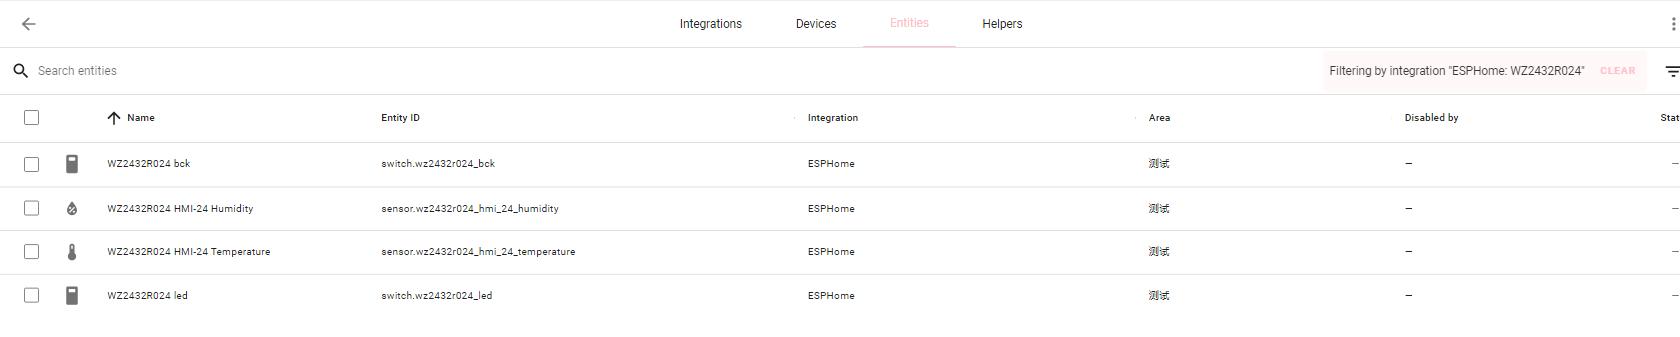
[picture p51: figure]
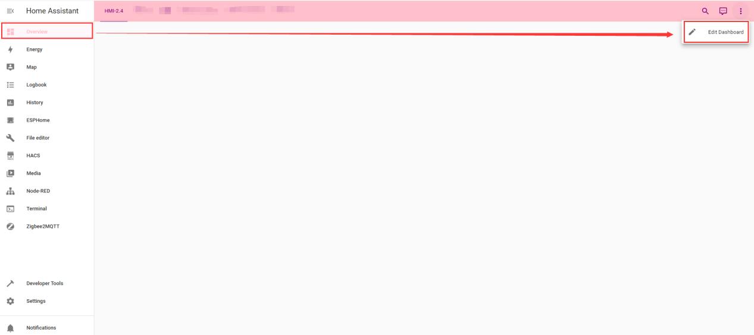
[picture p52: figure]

Now we start adding entities to the main interface

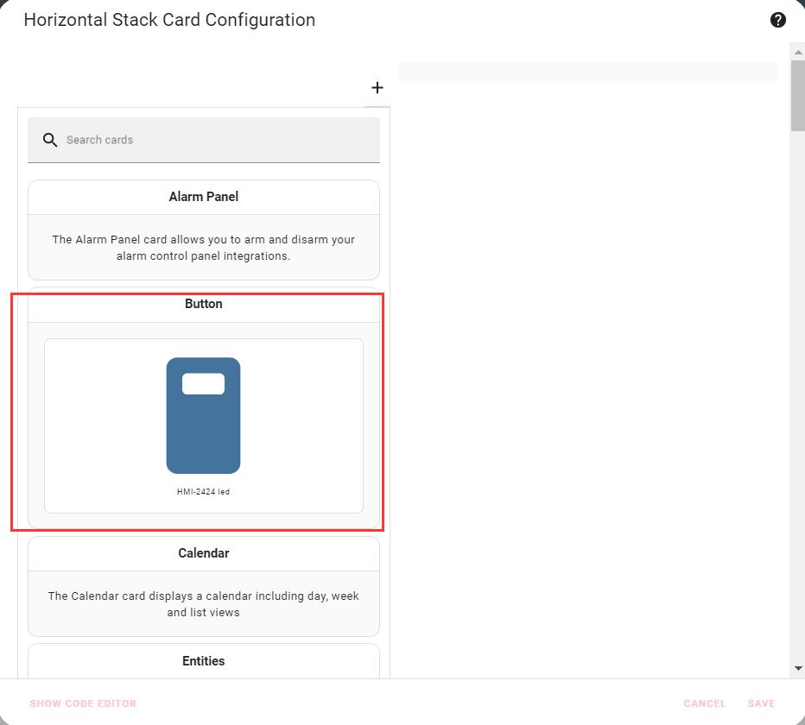
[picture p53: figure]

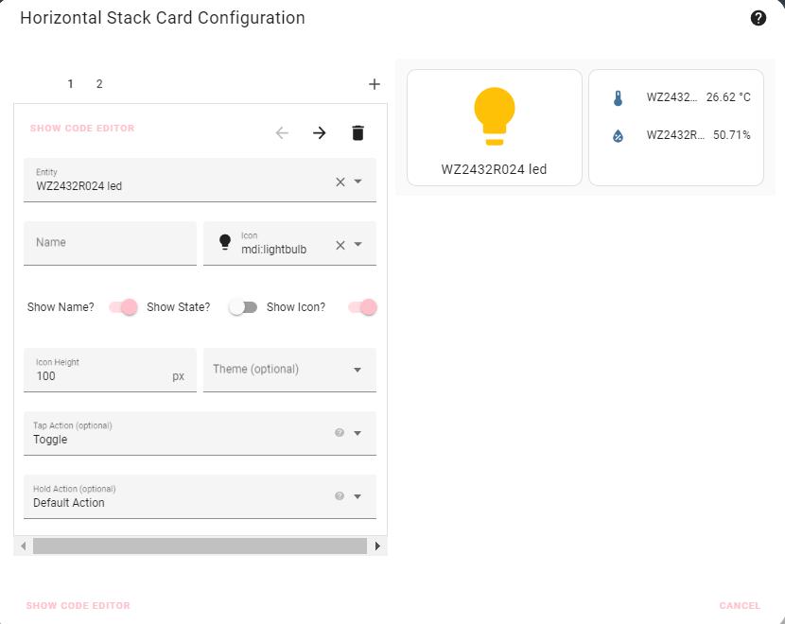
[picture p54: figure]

Click on the light：

Next, we make a graph of the temperature and humidity：


done ！

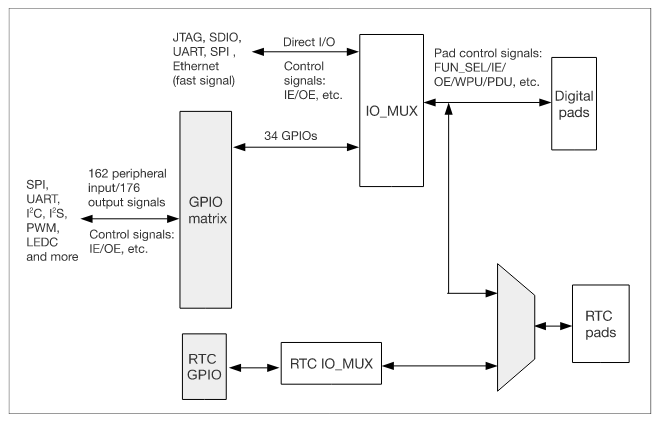
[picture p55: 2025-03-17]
example/V1.0_and_V2.0/ESP_IDF/ESP-IDF_2.4/2.4/Demo/components/arduino-esp32-master/docs/source/_static/tutorials/peripherals/tutorial_peripheral_diagram.png

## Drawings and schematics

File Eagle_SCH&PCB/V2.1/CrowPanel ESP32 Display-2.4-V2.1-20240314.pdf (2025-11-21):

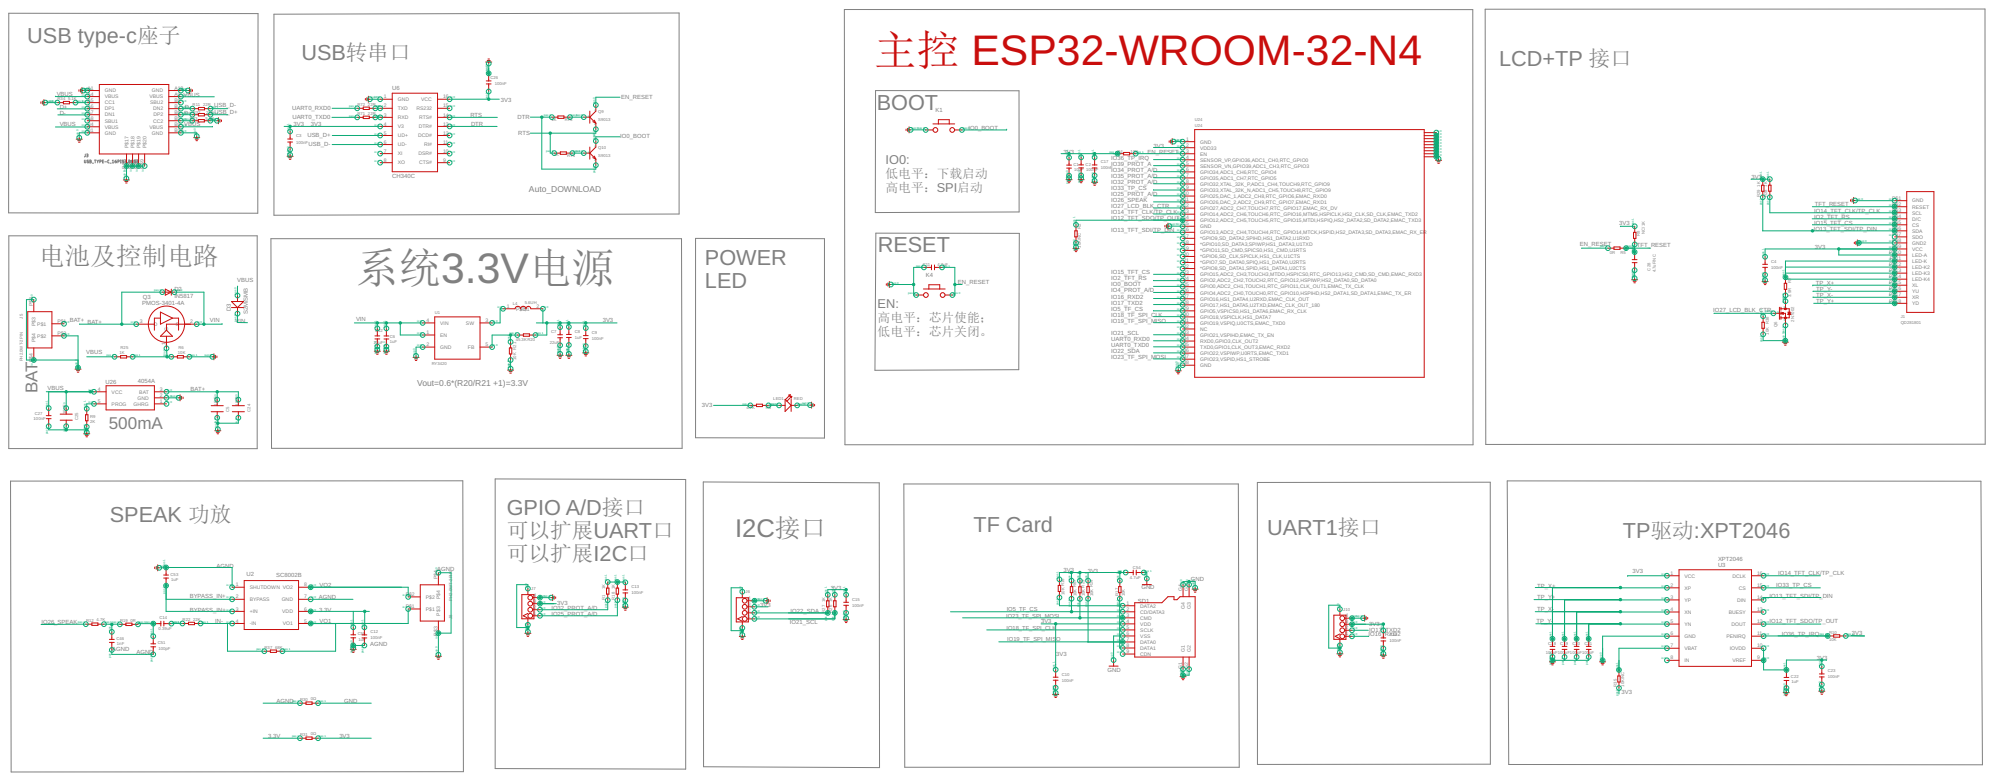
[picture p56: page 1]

pas 1 pas 1 pas 1 pas 1 sup 0

pas 0 pas 0 pas 1 pas 1

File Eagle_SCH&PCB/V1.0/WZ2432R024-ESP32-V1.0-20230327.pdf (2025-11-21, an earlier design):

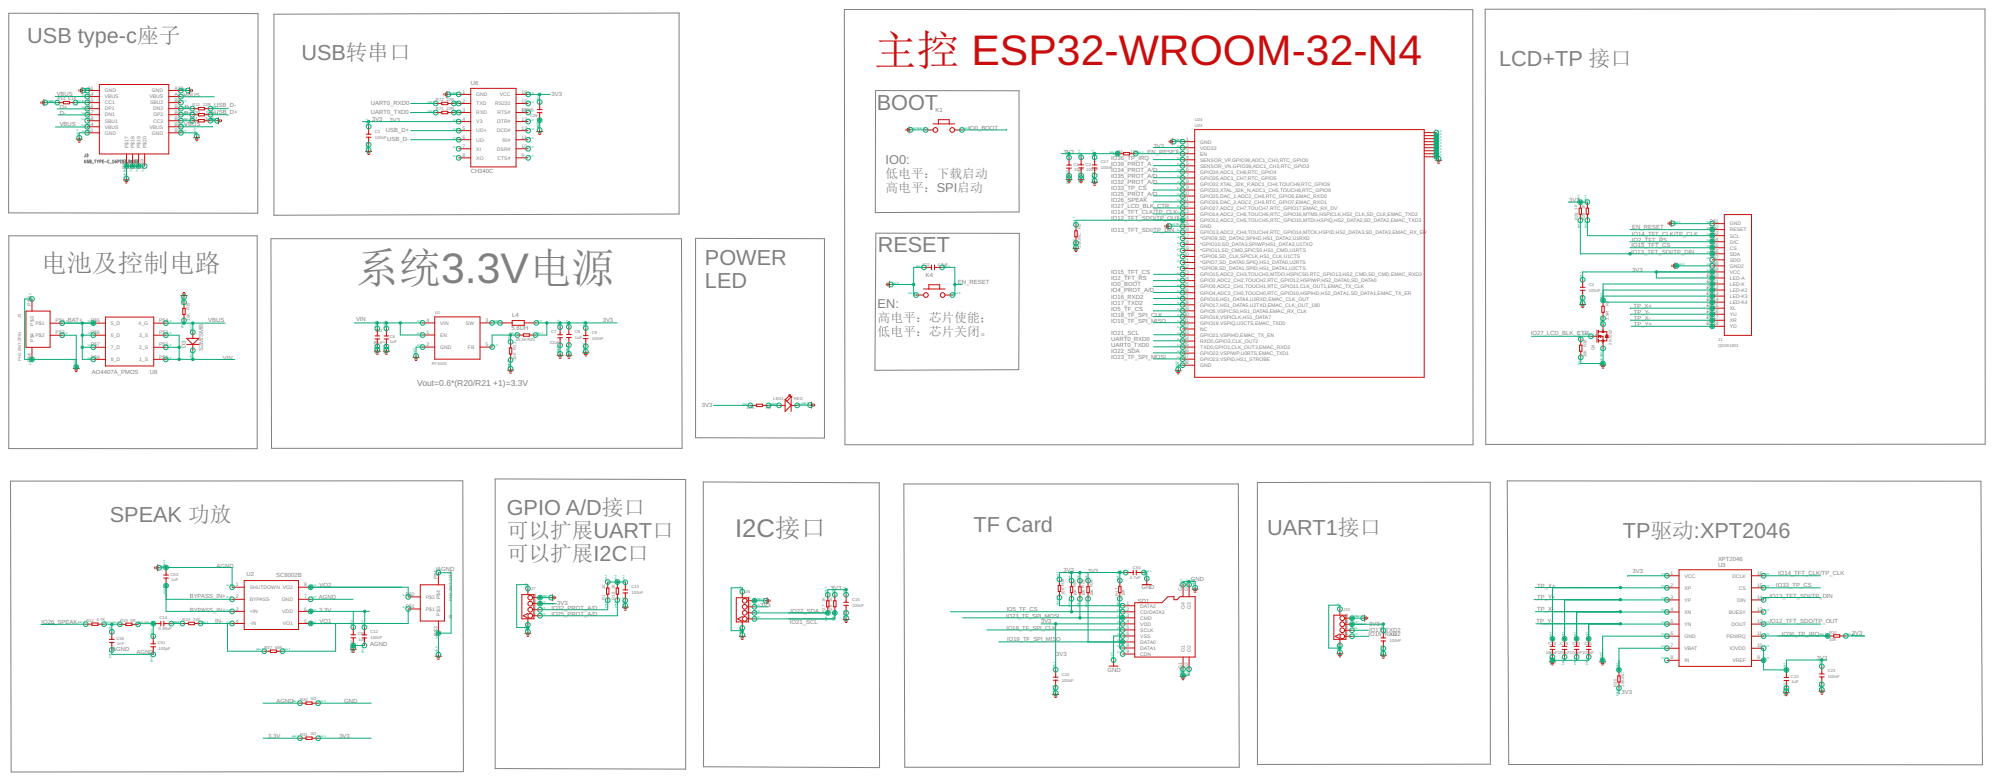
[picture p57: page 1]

pas 0 pas 0 pas 1 pas 1

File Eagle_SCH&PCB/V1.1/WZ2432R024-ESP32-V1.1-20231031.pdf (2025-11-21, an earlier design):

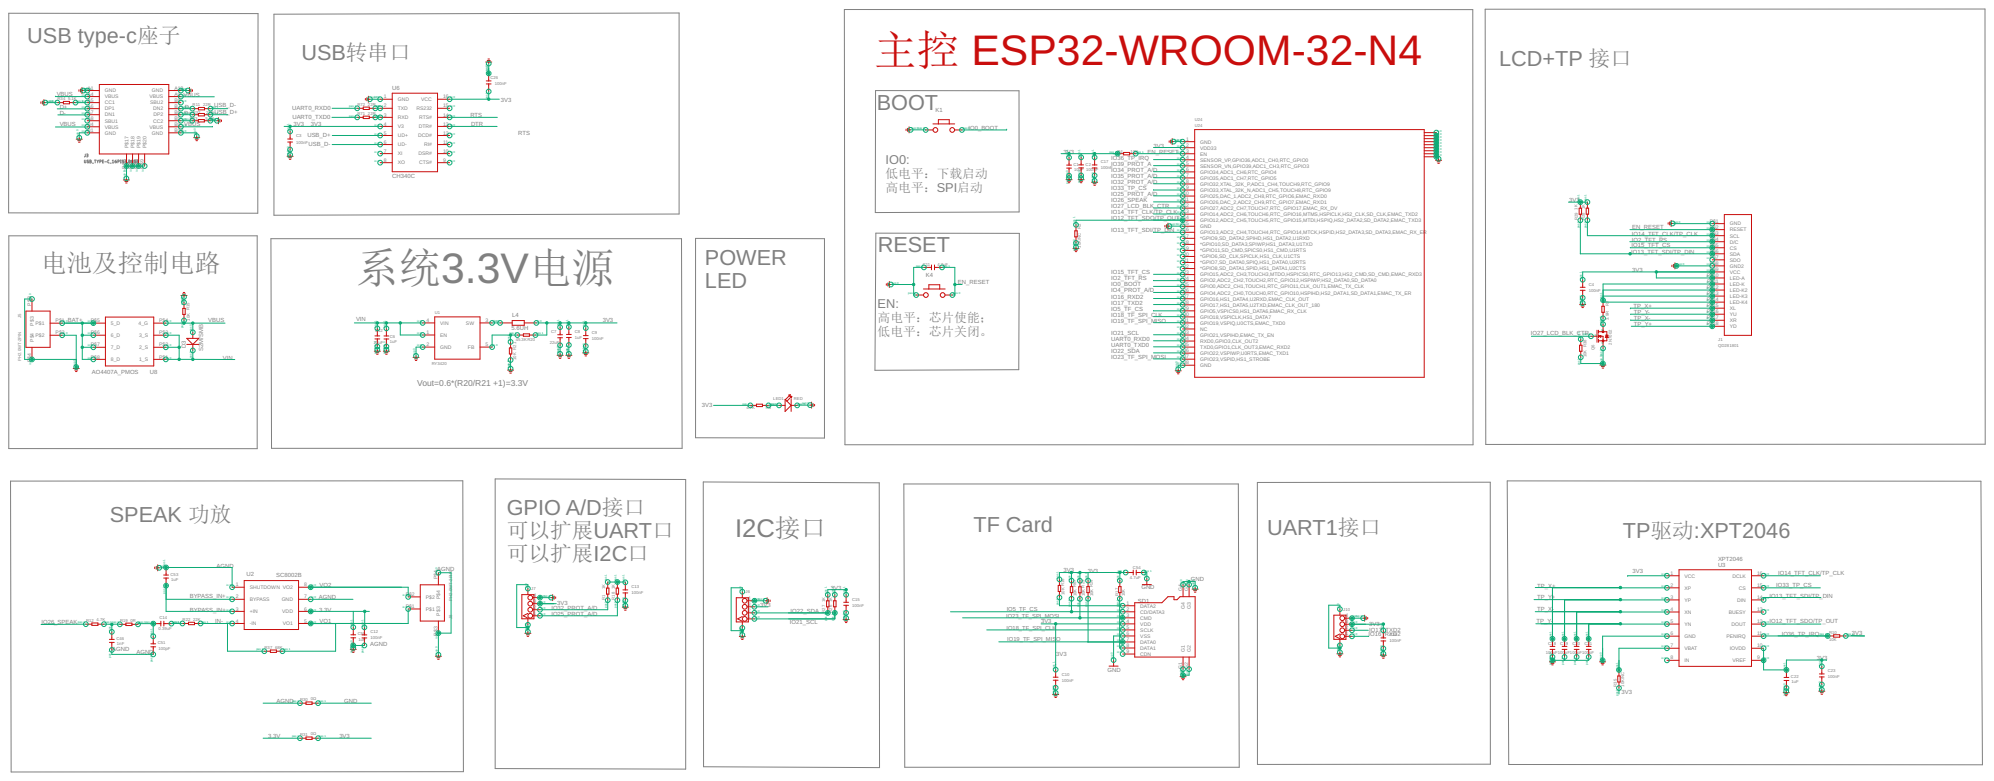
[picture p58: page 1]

pas 0 pas 0 pas 1 pas 1

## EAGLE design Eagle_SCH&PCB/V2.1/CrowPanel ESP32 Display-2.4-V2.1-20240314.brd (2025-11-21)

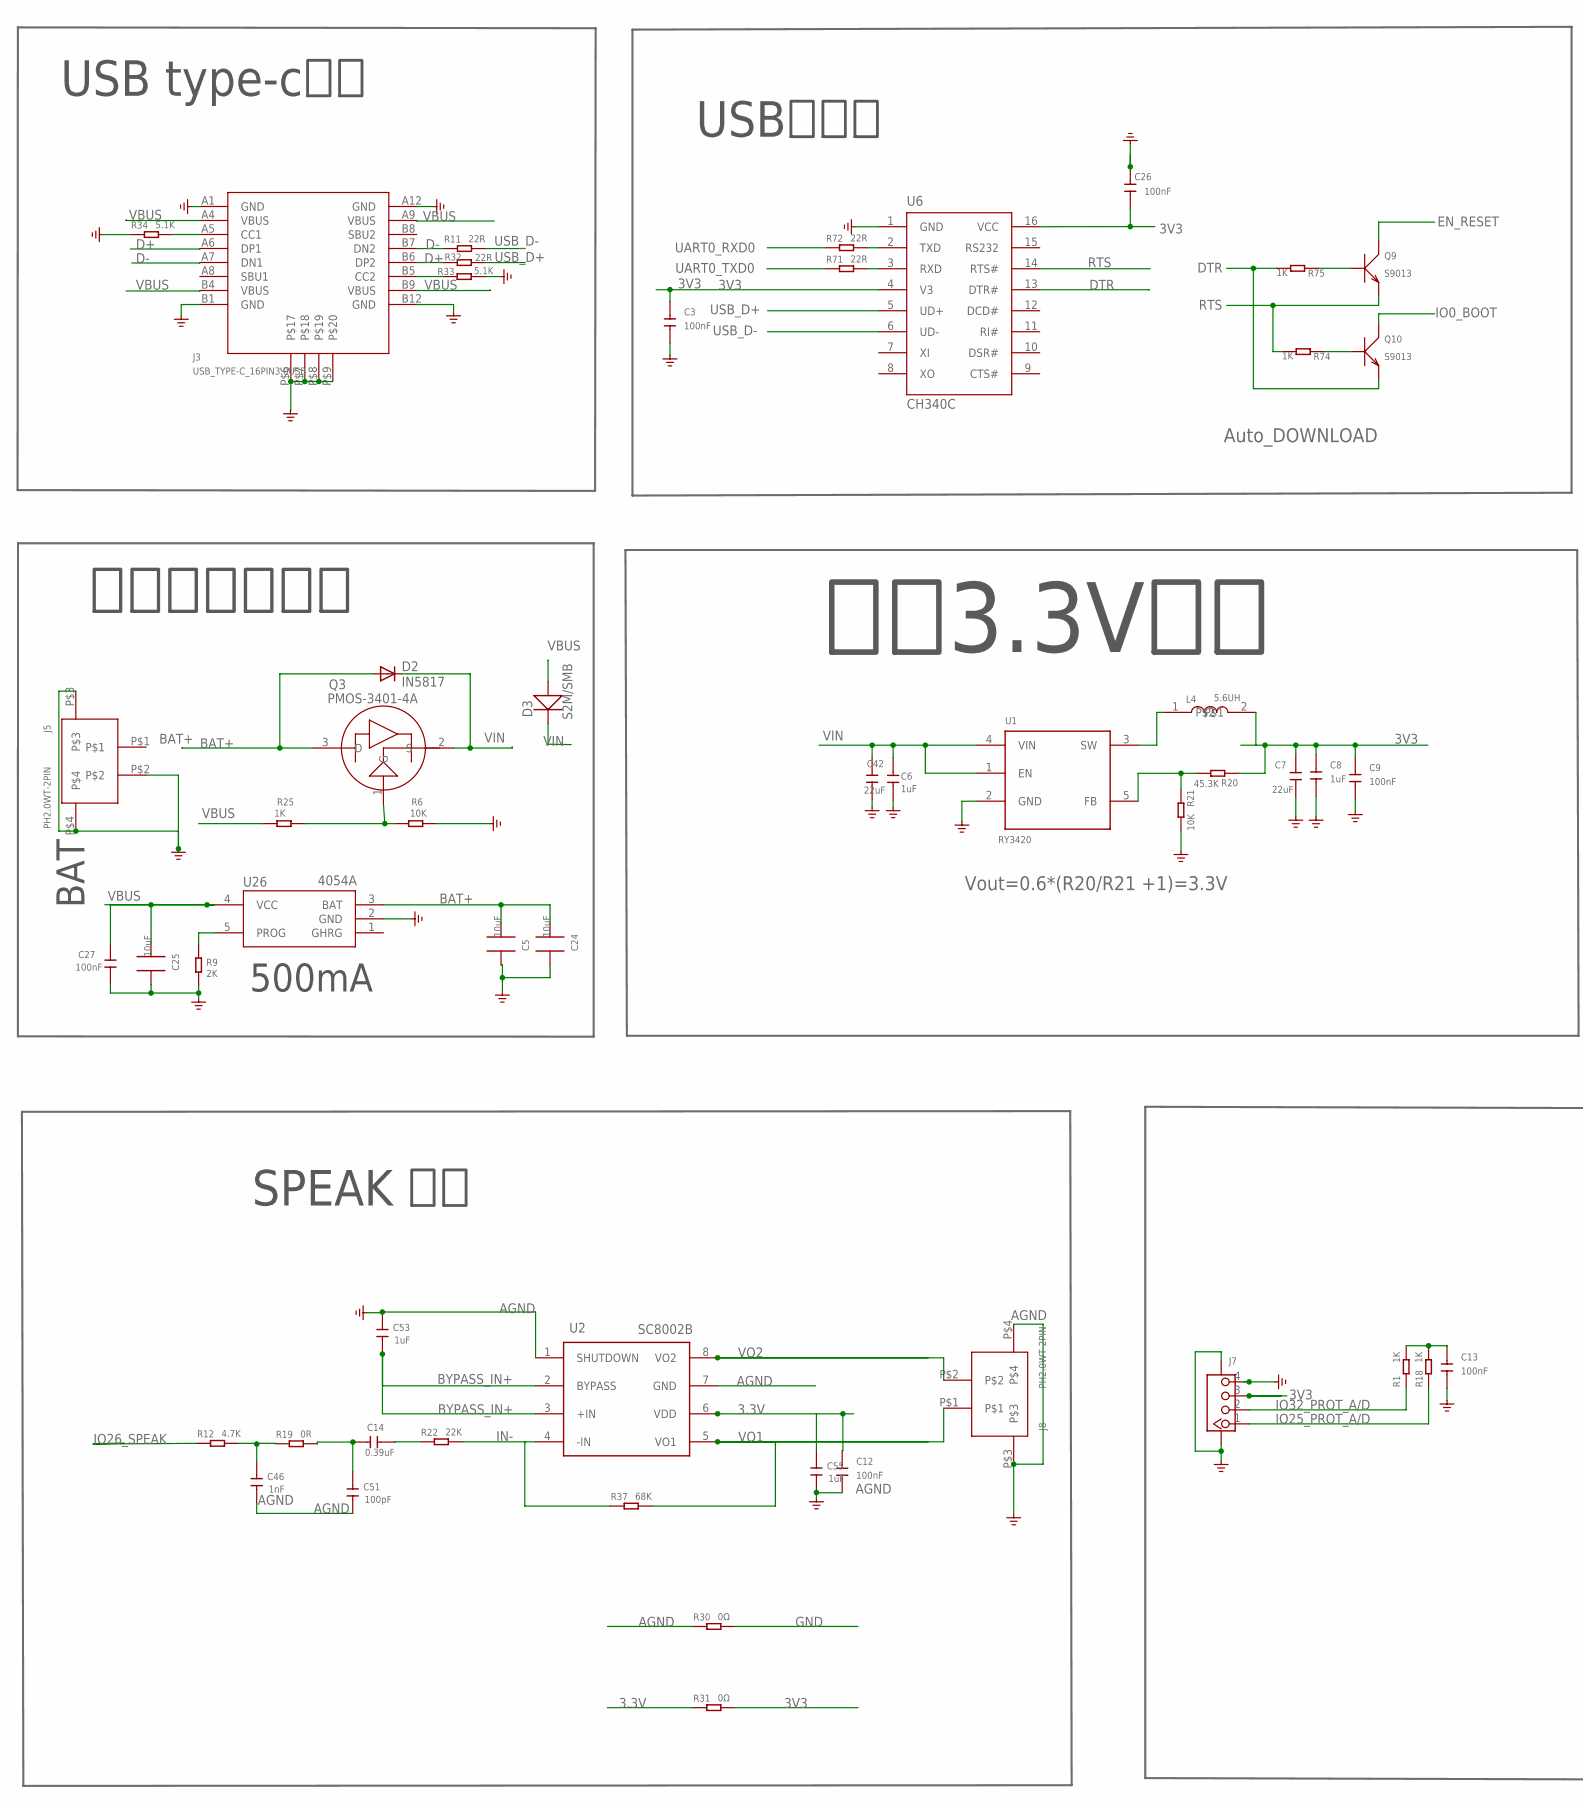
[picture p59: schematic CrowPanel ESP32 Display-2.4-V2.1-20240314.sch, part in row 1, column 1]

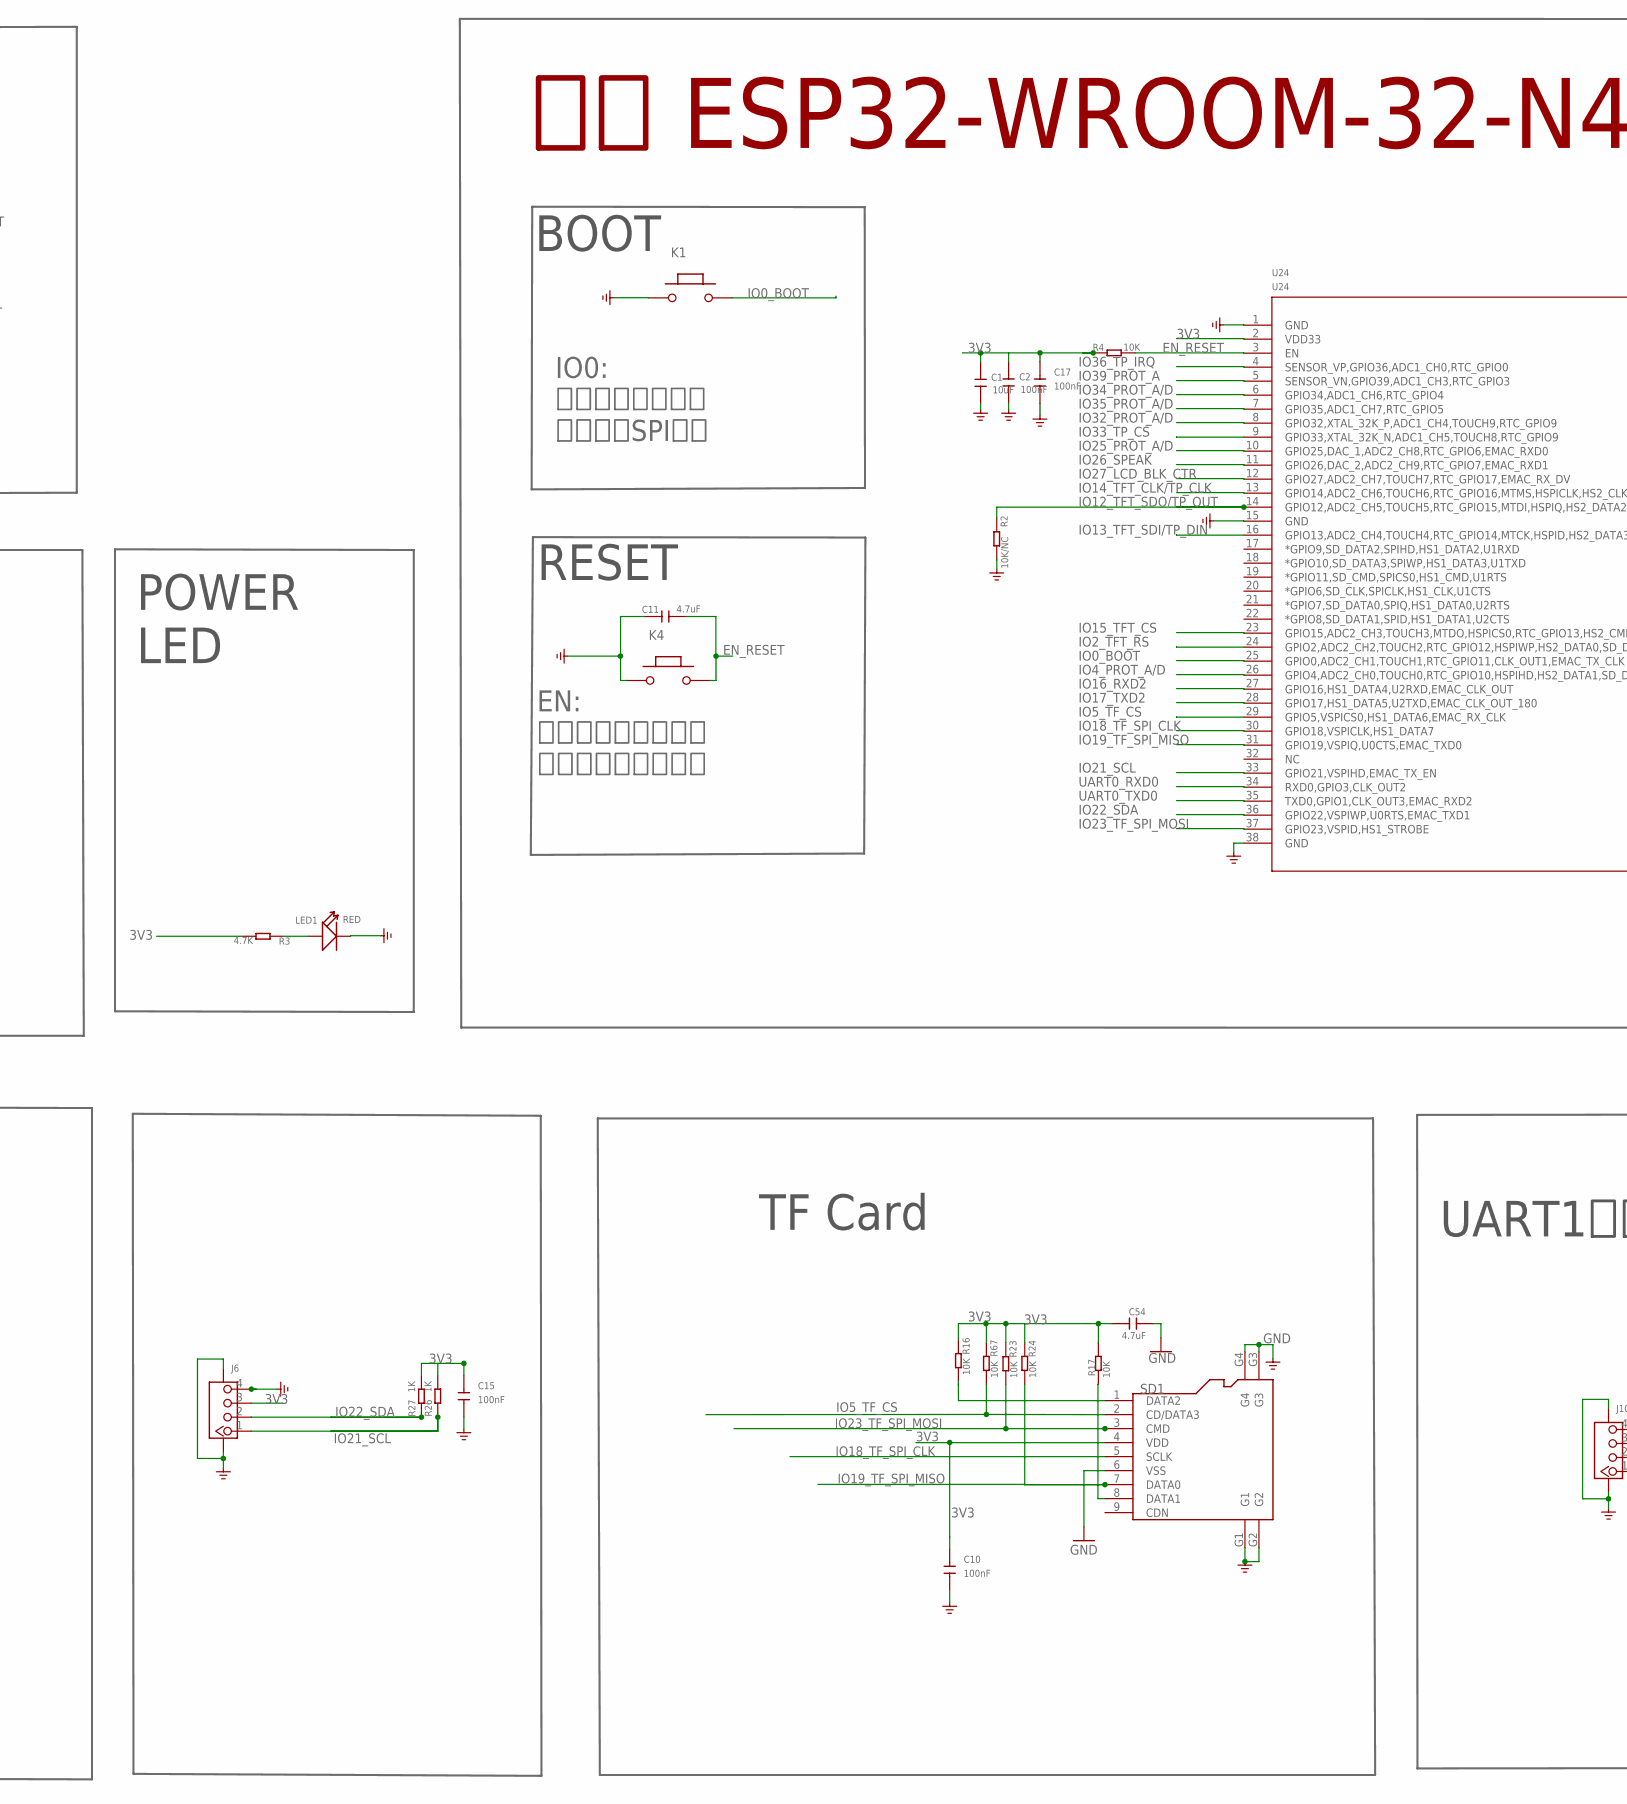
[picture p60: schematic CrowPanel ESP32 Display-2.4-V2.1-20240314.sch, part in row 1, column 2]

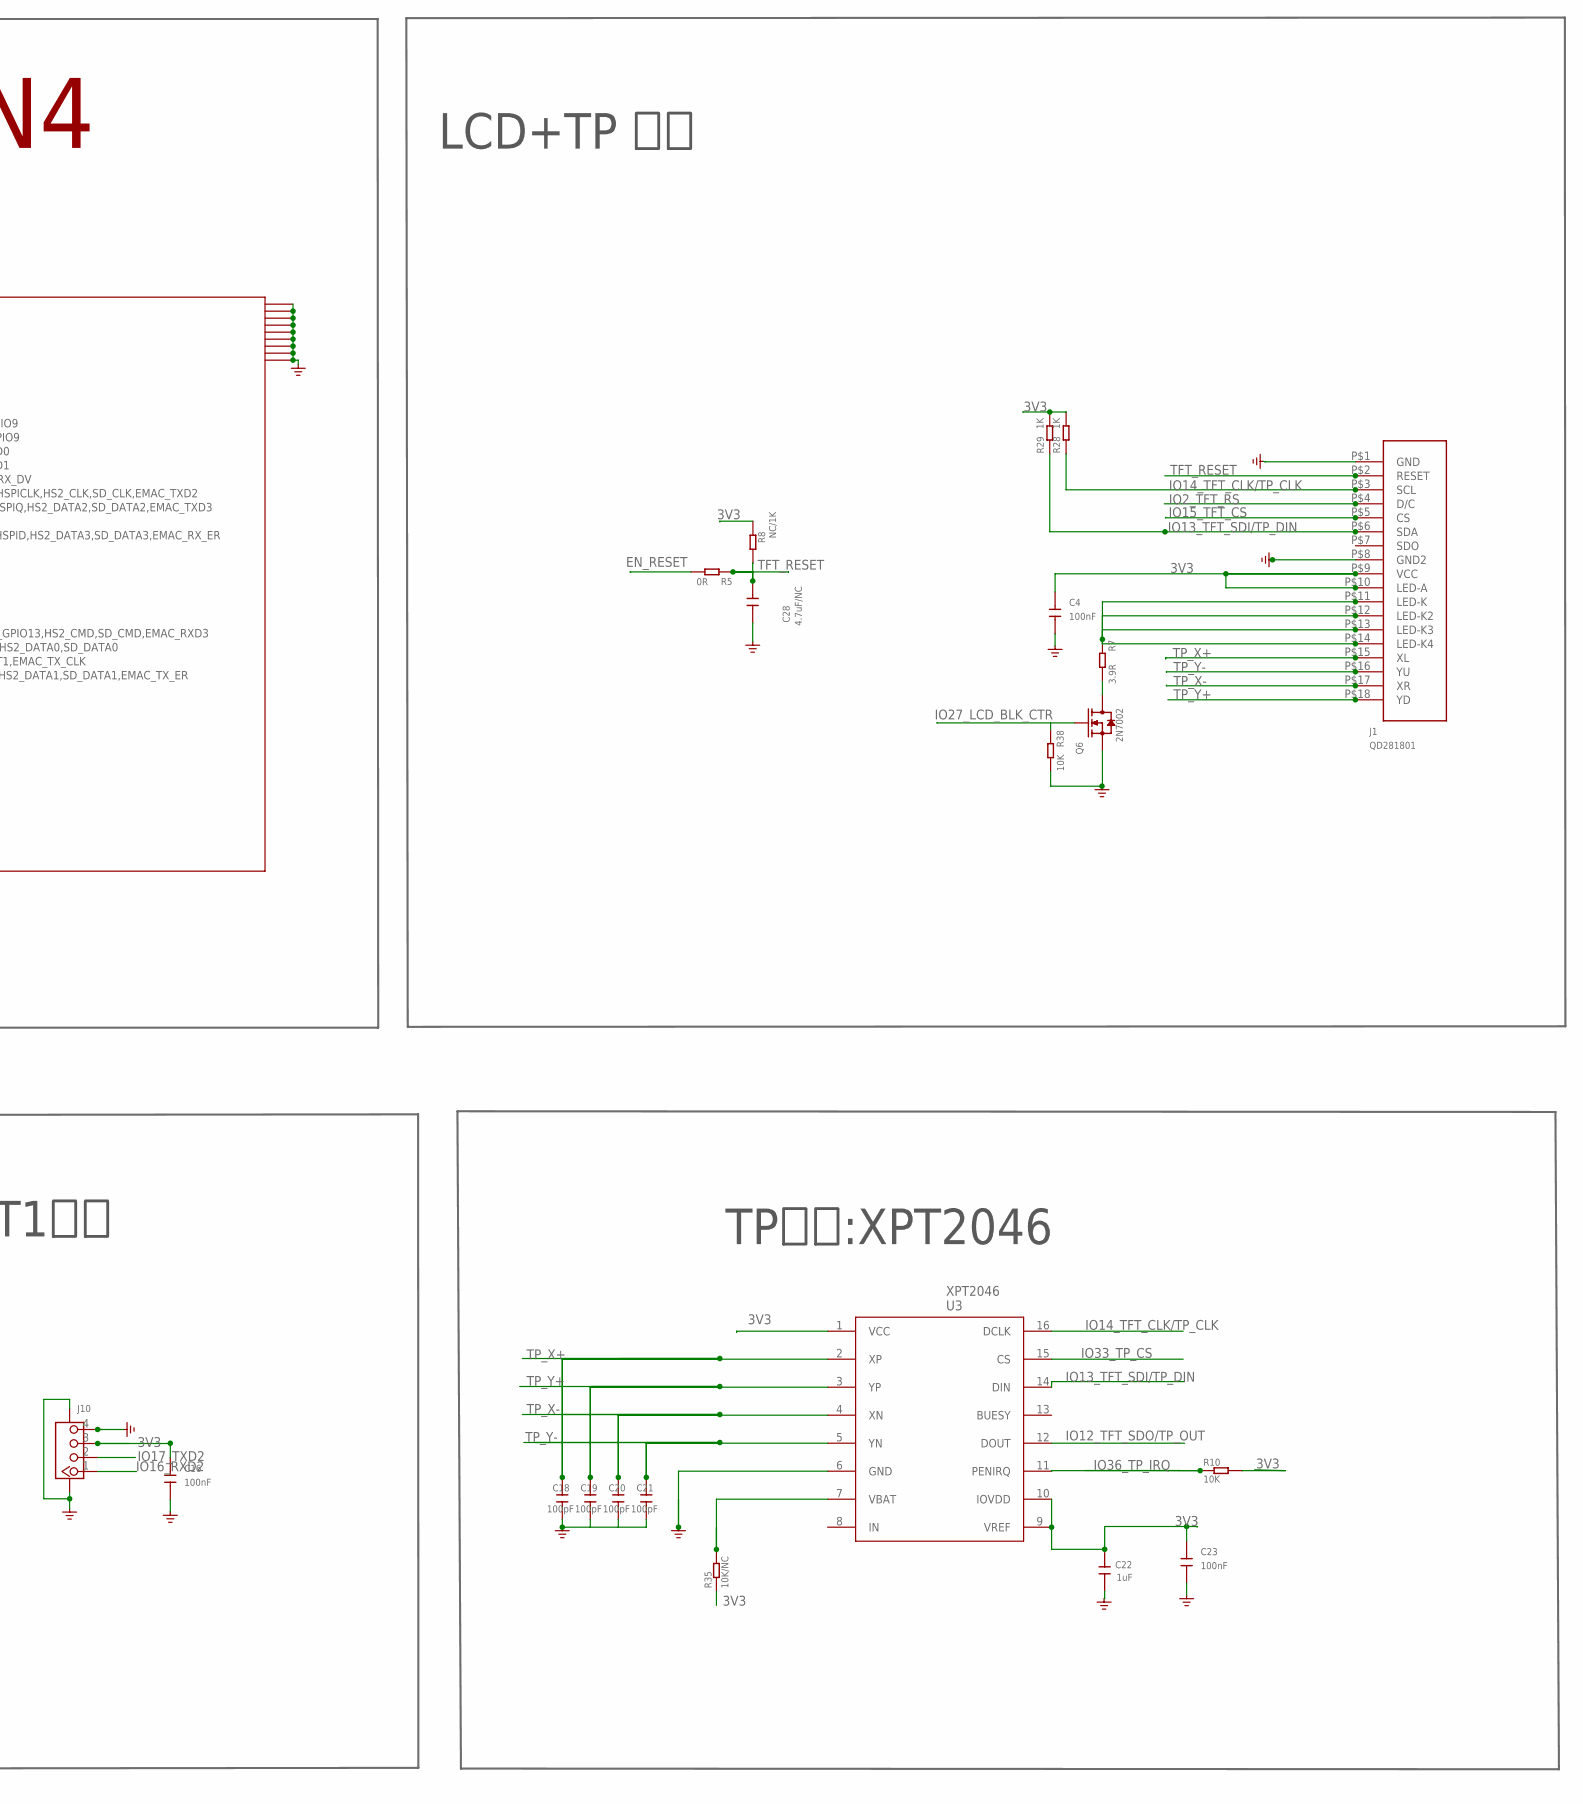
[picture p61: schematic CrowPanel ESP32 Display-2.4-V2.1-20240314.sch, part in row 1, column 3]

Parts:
C1: 10uF; DISCRETE_C0603
C2: 100nF; DISCRETE_C0603
C3, C4, C9, C10, C12, C13, C15, C16, C17, C23, C26: 100nF; 0603
C5, C24, C25: 10uF; 0805_S
C6, C8: 1uF; 0603
C7, C42: 22uF; 0805
C11: 4.7uF; 0603
C14: 0.39uF; DISCRETE_C0603
C18, C19, C20, C21: 100pF; 0603
C22, C53, C55: 1uF; DISCRETE_C0603
C27: 100nF; C0603
C28: 4.7uF/NC; 0603
C46: 1nF; DISCRETE_C0603
C51: 100pF; DISCRETE_C0603
C54: 4.7uF; DISCRETE_C0603
D2: IN5817; DO-214AC
D3: S2M/SMB; 214AB
J1: QD281801; QD241801-18PIN*0.8
J3: USB_TYPE-C_16PIN3.0USB; KEVIN_3.0TYPEC-SMD
J5, J8: PH2.0WT-2PIN
J6, J7, J10: CONNECTOR_TWIG-4P-2.0-SMD-FEMALE-REINFORCE90D; CONNECTOR_4P-SMD-2.0-90D
K1, K4: BUTTON; 157SW
L4: 5.6UH; CD54_CD54
LED1: RED; DISCRETE_LED-0603
Q3: PMOS-3401-4A; SOT-23
Q6: 2N7002; SOT23
Q9, Q10: S9013; SOT23@1
R1, R18, R25, R26, R27, R28, R29, R74, R75: 1K; DISCRETE_R0603
R2, R35: 10K/NC; DISCRETE_R0603
R3, R12: 4.7K; DISCRETE_R0603
R4: 10K; R0603
R5, R19: 0R; DISCRETE_R0603
R6, R10, R16, R17, R21, R23, R24, R38, R67: 10K; DISCRETE_R0603
R7: 3.9R; DISCRETE_R0603
R8: NC/1K; DISCRETE_R0603
R9: 2K; DISCRETE_R0603
R11, R32, R71, R72: 22R; DISCRETE_R0603
R20: 45.3K; DISCRETE_R0603
R22: 22K; DISCRETE_R0603
R30, R31: 0Ω; DISCRETE_R0603
R33, R34: 5.1K; DISCRETE_R0603
R37: 68K; DISCRETE_R0603
SD1: HOLDER-MICROSD-9P; 9P-SMD-W/-RING
U1: RY3420; A_XBJ_SOT23-5
U2: SC8002B; AT24C02_SOP8
U3: XPT2046; XP2046-SSOP16
U6: CH340C; SOP-16
U24: U24; ESP32-WROOM-32-N4
U26: 4054A; SOP23-5

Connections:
3.3V: C12.2, C55.2, R31.1, U2.6 (VDD)
3V3: C1.2, C2.2, C3.2, C4.2, C7.2, C8.2, C9.2, C10.2, C13.2, C15.2, C16.2, C17.2, C22.2, C23.2, C26.1, C54.2, J1.P$9 (VCC), J1.P$10 (LED-A), J6.3, J7.3, J10.3, L4.2, R1.2, R3.2, R4.1, R8.2, R10.2, R16.1, R17.1, R18.2, R20.1, R23.1, R24.1, R26.2, R27.2, R28.2, R29.2, R31.2, R35.1, R67.1, SD1.4 (VDD), U3.1 (VCC), U3.9 (VREF), U3.10 (IOVDD), U6.4 (V3), U6.16 (VCC), U24.2 (VDD33)
AGND: C12.1, C46.1, C51.1, C53.2, C55.1, J8.P$3, J8.P$4, R30.1, U2.1 (SHUTDOWN), U2.7 (GND)
BAT+: C5.2, C24.2, D2.A, J5.P$1, Q3.3 (D), U26.3 (BAT)
BYPASS_IN+: C53.1, U2.2 (BYPASS), U2.3 (+IN)
D+: J3.A6 (DP1), J3.B6 (DP2), R32.1
D-: J3.A7 (DN1), J3.B7 (DN2), R11.1
DTR: Q10.2 (E), R75.2, U6.13 (DTR#)
EN_RESET: C11.1, K4.2, Q9.3 (C), R4.2, R5.2, U24.3 (EN)
GND: C1.1, C2.1, C3.1, C4.1, C5.1, C6.1, C7.1, C8.1, C9.1, C10.1, C11.2, C13.1, C15.1, C16.1, C17.1, C18.1, C19.1, C20.1, C21.1, C22.1, C23.1, C24.1, C25.1, C26.2, C27.2, C28.2, C42.1, C54.1, J1.P$1 (GND), J1.P$8 (GND2), J3.A1 (GND), J3.A12 (GND), J3.B1 (GND), J3.B12 (GND), J3.P$6, J3.P$7, J3.P$8, J3.P$9, J5.P$2, J5.P$3, J5.P$4, J6.4, J6.SS1, J6.SS2, J7.4, J7.SS1, J7.SS2, J10.4, J10.SS1, J10.SS2, K1.1, K4.1, LED1.-, Q6.2 (S), R2.2, R6.1, R9.2, R21.2, R30.2, R33.2, R34.1, R38.2, SD1.6 (VSS), SD1.G1, SD1.G2, SD1.G3, SD1.G4, U1.2 (GND), U3.6 (GND), U6.1 (GND), U24.1 (GND), U24.15 (GND), U24.38 (GND), U24.41 (GND), U24.42 (GND), U24.43 (GND), U24.44 (GND), U24.45 (GND), U24.46 (GND), U24.47 (GND), U24.48 (GND), U24.49 (GND), U26.2 (GND)
IN-: R22.2, R37.1, U2.4 (-IN)
IO0_BOOT: K1.2, Q10.3 (C), U24.25 (GPIO0,ADC2_CH1,TOUCH1,RTC_GPIO11,CLK_OU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)
IO2_TFT_RS: J1.P$4 (D/C), U24.24 (GPIO2,ADC2_CH2,TOUCH2,RTC_GPIO12,HSPIWP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)
IO4_PROT_A/D: U24.26 (GPIO4,ADC2_CH0,TOUCH0,RTC_GPIO10,HSPIHD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)
IO5_TF_CS: R67.2, SD1.2 (CD/DATA3), U24.29 (GPIO5,VSPICS0,HS1_DATA6,EMAC_RX_CLK)
IO12_TFT_SDO/TP_OUT: R2.1, U3.12 (DOUT), U24.14 (GPIO12,ADC2_CH5,TOUCH5,RTC_GPIO15,MTDI,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)
IO13_TFT_SDI/TP_DIN: J1.P$6 (SDA), R29.1, U3.14 (DIN), U24.16 (GPIO13,ADC2_CH4,TOUCH4,RTC_GPIO14,MTCK,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)
IO14_TFT_CLK/TP_CLK: J1.P$3 (SCL), R28.1, U3.16 (DCLK), U24.13 (GPIO14,ADC2_CH6,TOUCH6,RTC_GPIO16,MTMS,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)
IO15_TFT_CS: J1.P$5 (CS), U24.23 (GPIO15,ADC2_CH3,TOUCH3,MTDO,HSPICS0,RTC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)
IO16_RXD2: J10.1, U24.27 (GPIO16,HS1_DATA4,U2RXD,EMAC_CLK_OUT)
IO17_TXD2: J10.2, U24.28 (GPIO17,HS1_DATA5,U2TXD,EMAC_CLK_OUT_180)
IO18_TF_SPI_CLK: SD1.5 (SCLK), U24.30 (GPIO18,VSPICLK,HS1_DATA7)
IO19_TF_SPI_MISO: R24.2, SD1.7 (DATA0), U24.31 (GPIO19,VSPIQ,U0CTS,EMAC_TXD0)
IO21_SCL: J6.1, R26.1, U24.33 (GPIO21,VSPIHD,EMAC_TX_EN)
IO22_SDA: J6.2, R27.1, U24.36 (GPIO22,VSPIWP,U0RTS,EMAC_TXD1)
IO23_TF_SPI_MOSI: R23.2, SD1.3 (CMD), U24.37 (GPIO23,VSPID,HS1_STROBE)
IO25_PROT_A/D: J7.1, R18.1, U24.10 (GPIO25,DAC_1,ADC2_CH8,RTC_GPIO6,EMAC_RX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)
IO26_SPEAK: R12.1, U24.11 (GPIO26,DAC_2,ADC2_CH9,RTC_GPIO7,EMAC_RX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)
IO27_LCD_BLK_CTR: Q6.1 (G), R38.1, U24.12 (GPIO27,ADC2_CH7,TOUCH7,RTC_GPIO17,EMAC_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)
IO32_PROT_A/D: J7.2, R1.1, U24.8 (GPIO32,XTAL_32K_P,ADC1_CH4,TOUCH9,RTC_G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)
IO33_TP_CS: U3.15 (CS), U24.9 (GPIO33,XTAL_32K_N,ADC1_CH5,TOUCH8,RTC_G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)
IO34_PROT_A/D: U24.6 (GPIO34,ADC1_CH6,RTC_GPIO4)
IO35_PROT_A/D: U24.7 (GPIO35,ADC1_CH7,RTC_GPIO5)
IO36_TP_IRQ: R10.1, U3.11 (PENIRQ), U24.4 (SENSOR_VP,GPIO36,ADC1_CH0,RTC_GPIO0)
IO39_PROT_A: U24.5 (SENSOR_VN,GPIO39,ADC1_CH3,RTC_GPIO3)
unnamed: LED1.+, R3.1
unnamed: Q6.3 (D), R7.2
unnamed: C46.2, R12.2, R19.1
unnamed: R35.2, U3.7 (VBAT)
unnamed: R9.1, U26.5 (PROG)
unnamed: J1.P$11 (LED-K), J1.P$12 (LED-K2), J1.P$13 (LED-K3), J1.P$14 (LED-K4), R7.1
unnamed: L4.1, U1.3 (SW)
unnamed: J3.B5 (CC2), R33.1
unnamed: J3.A5 (CC1), R34.2
unnamed: Q3.1 (G), R6.2, R25.1
unnamed: R20.2, R21.1, U1.5 (FB)
unnamed: C14.1, C51.2, R19.2
unnamed: C14.2, R22.1
unnamed: Q9.1 (B), R75.1
unnamed: Q10.1 (B), R74.1
unnamed: R72.2, U6.2 (TXD)
unnamed: R71.2, U6.3 (RXD)
unnamed: R16.2, SD1.1 (DATA2)
unnamed: R17.2, SD1.8 (DATA1)
RTS: Q9.2 (E), R74.2, U6.14 (RTS#)
TFT_RESET: C28.1, J1.P$2 (RESET), R5.1, R8.1
TP_X+: C18.2, J1.P$15 (XL), U3.2 (XP)
TP_X-: C20.2, J1.P$17 (XR), U3.4 (XN)
TP_Y+: C19.2, J1.P$18 (YD), U3.3 (YP)
TP_Y-: C21.2, J1.P$16 (YU), U3.5 (YN)
UART0_RXD0: R72.1, U24.34 (RXD0,GPIO3,CLK_OUT2)
UART0_TXD0: R71.1, U24.35 (TXD0,GPIO1,CLK_OUT3,EMAC_RXD2)
USB_D+: R32.2, U6.5 (UD+)
USB_D-: R11.2, U6.6 (UD-)
VBUS: C25.2, C27.1, D3.1 (+), J3.A4 (VBUS), J3.A9 (VBUS), J3.B4 (VBUS), J3.B9 (VBUS), R25.2, U26.4 (VCC)
VIN: C6.2, C42.2, D2.C, D3.2 (-), Q3.2 (S), U1.1 (EN), U1.4 (VIN)
VO1: J8.P$1, R37.2, U2.5 (VO1)
VO2: J8.P$2, U2.8 (VO2)

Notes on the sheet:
Vout=0.6*(R20/R21 +1)=3.3V
系统3.3V电源
UART1接口
主控 ESP32-WROOM-32-N4
USB type-c座子
电池及控制电路
IO0: 低电平：下载启动 高电平：SPI启动
EN: 高电平：芯片使能； 低电平：芯片关闭。
USB转串口
SPEAK 功放
TF Card
BOOT
RESET
POWER LED
LCD+TP 接口
TP驱动:XPT2046
Auto_DOWNLOAD
500mA
BAT

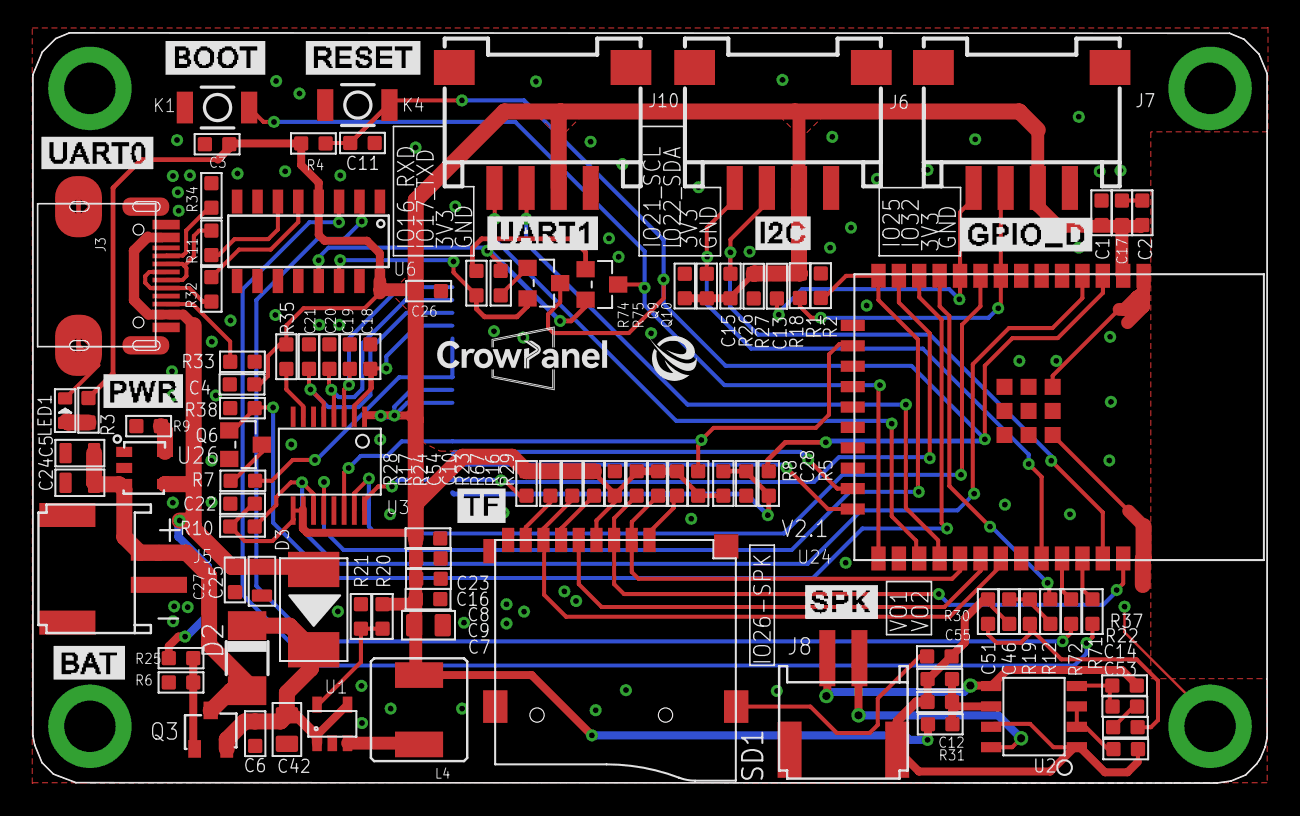
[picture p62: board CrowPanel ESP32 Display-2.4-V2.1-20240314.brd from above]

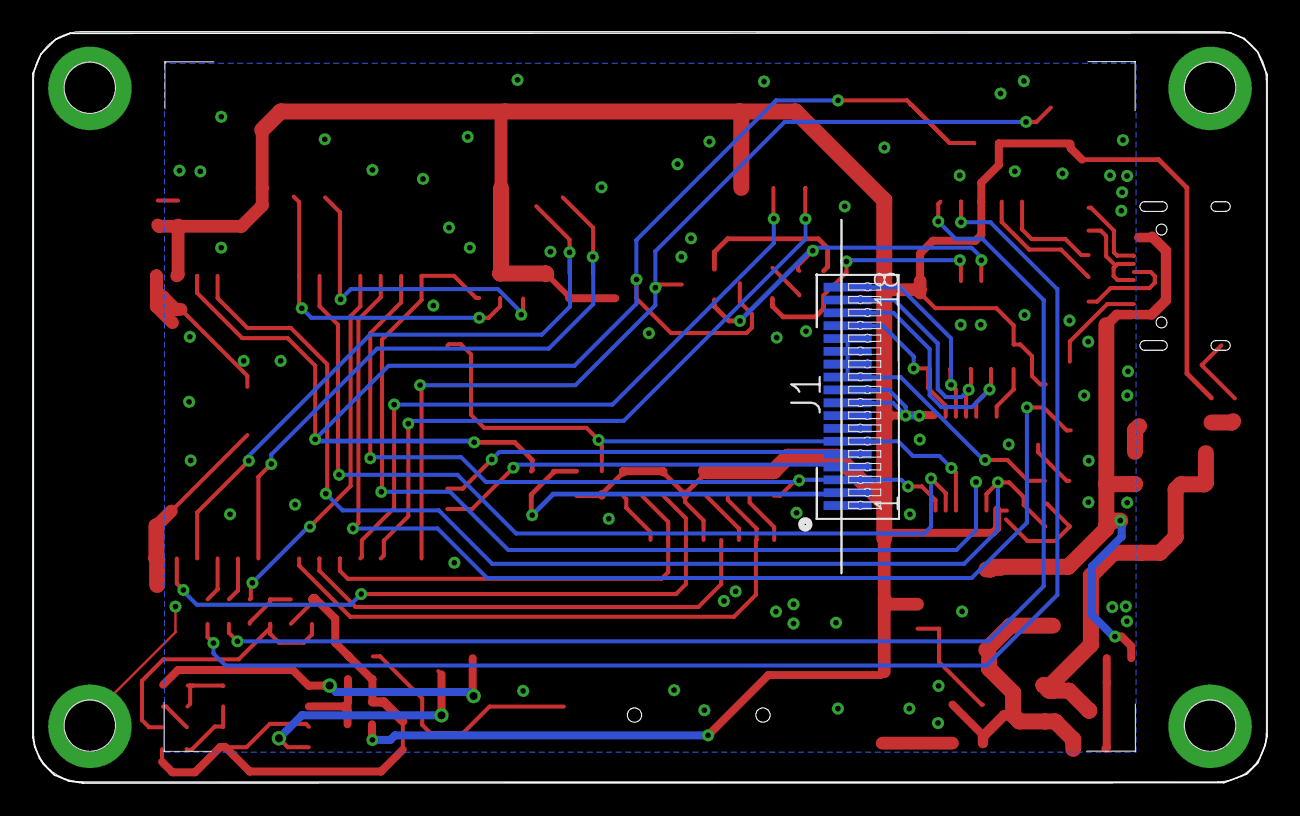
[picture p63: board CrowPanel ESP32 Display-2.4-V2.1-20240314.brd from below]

Board: 2 copper layers, 76.8 x 46.7 mm, 100 parts (2 on the bottom side), 64 nets.

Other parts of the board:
U$2: 2.4板框
U$3: LOGE-2.0
U$37: LOGLE

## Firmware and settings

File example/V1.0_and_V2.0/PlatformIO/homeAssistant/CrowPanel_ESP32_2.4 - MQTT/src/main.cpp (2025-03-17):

#include <TFT_eSPI.h>
#include <Arduino.h>
#include <SPI.h>
#include <WiFi.h>
#include <Wire.h>

extern "C" {
#include "freertos/FreeRTOS.h"
#include "freertos/timers.h"
}
#include <AsyncMqttClient.h>
#include <DHT20.h>

#define Display_24        //according to the board you using ,if you using the ESP32 Display 3.5inch board, please define 'Display_35'.if using 2.4inch board,please define 'Display_24'.

#define LED 32

#define WIFI_SSID "yanfa_software"
#define WIFI_PASSWORD "yanfa-123456"

// Raspberry Pi Mosquitto MQTT Broker
#define MQTT_HOST IPAddress(192, 168, 50, 233)

// For a cloud MQTT broker, type the domain name
//#define MQTT_HOST "example.com"
#define MQTT_PORT 1885

// Temperature MQTT Topics
#define MQTT_PUB_LED_S  "esp32/led/state"
#define MQTT_PUB_LED_C "esp32/led/command"
#define MQTT_PUB_TEMP "esp32/temperature"
#define MQTT_PUB_HUM  "esp32/humidity"
#define mqtt_username  "elecrow"
#define mqtt_password  "elecrow2014"

// Initialize DHT20 sensor
DHT20 dht20;

AsyncMqttClient mqttClient;
TimerHandle_t mqttReconnectTimer;
TimerHandle_t wifiReconnectTimer;

#include <lvgl.h>
#include "ui.h"


#if defined Display_35      //ESP32 Display 3.5inch Board
/*screen resolution*/
static const uint16_t screenWidth  = 480;
static const uint16_t screenHeight = 320;
uint16_t calData[5] = { 353, 3568, 269, 3491, 7  };     /*touch caldata*/

#elif defined Display_24    //ESP32 Display 2.4inch Board
static const uint16_t screenWidth  = 320;
static const uint16_t screenHeight = 240;
uint16_t calData[5] = { 557, 3263, 369, 3493, 3  };

#elif defined Display_28    //ESP32 Display 2.8inch Board
static const uint16_t screenWidth  = 320;
static const uint16_t screenHeight = 240;
uint16_t calData[5] = { 189, 3416, 359, 3439, 1 };
#endif


TFT_eSPI lcd = TFT_eSPI(); /* TFT entity */


static lv_disp_draw_buf_t draw_buf;
static lv_color_t buf1[ screenWidth * screenHeight / 13 ];


int led_flag = 0;
int led_flag_Lock = 0;
int  temp;
int  hum;

unsigned long previousMillis = 0;   // Stores last time temperature was published
const long interval = 10000;        // Interval at which to publish sensor readings

//_______________________
/* display flash */
void my_disp_flush( lv_disp_drv_t *disp, const lv_area_t *area, lv_color_t *color_p )
{
  uint32_t w = ( area->x2 - area->x1 + 1 );
  uint32_t h = ( area->y2 - area->y1 + 1 );

  lcd.startWrite();
  lcd.setAddrWindow( area->x1, area->y1, w, h );
  lcd.pushColors( ( uint16_t * )&color_p->full, w * h, true );
  lcd.endWrite();

  lv_disp_flush_ready( disp );
}

uint16_t touchX, touchY;
/*touch read*/
void my_touchpad_read( lv_indev_drv_t * indev_driver, lv_indev_data_t * data )
{

  bool touched = lcd.getTouch( &touchX, &touchY, 600);
  if ( !touched )
  {
    data->state = LV_INDEV_STATE_REL;
  }
  else
  {
    data->state = LV_INDEV_STATE_PR;

    /*set location*/
    data->point.x = touchX;
    data->point.y = touchY;

    Serial.print( "Data x " );
    Serial.println( touchX );

    Serial.print( "Data y " );
    Serial.println( touchY );
  }
}

void connectToWifi() {
  Serial.println("Connecting to Wi-Fi...");
  WiFi.begin(WIFI_SSID, WIFI_PASSWORD);
}

void connectToMqtt() {
  Serial.println("Connecting to MQTT...");
  mqttClient.connect();
}

void WiFiEvent(WiFiEvent_t event) {
  Serial.printf("[WiFi-event] event: %d\n", event);
  switch (event) {
    case SYSTEM_EVENT_STA_GOT_IP:
      Serial.println("WiFi connected");
      Serial.println("IP address: ");
      Serial.println(WiFi.localIP());
      connectToMqtt();
      break;
    case SYSTEM_EVENT_STA_DISCONNECTED:
      Serial.println("WiFi lost connection");
      xTimerStop(mqttReconnectTimer, 0); // ensure we don't reconnect to MQTT while reconnecting to Wi-Fi
      xTimerStart(wifiReconnectTimer, 0);
      break;
  }
}

void onMqttConnect(bool sessionPresent) {
  Serial.println("Connected to MQTT.");
  Serial.print("Session present: ");
  Serial.println(sessionPresent);
  uint16_t packetIdSub = mqttClient.subscribe(MQTT_PUB_LED_C, 2);
  Serial.print("Subscribing at QoS 2, packetId: ");
  Serial.println(packetIdSub);
}

void onMqttDisconnect(AsyncMqttClientDisconnectReason reason) {
  Serial.println("Disconnected from MQTT.");
  if (WiFi.isConnected()) {
    xTimerStart(mqttReconnectTimer, 0);
  }
}

void onMqttSubscribe(uint16_t packetId, uint8_t qos) {
  Serial.println("Subscribe acknowledged.");
  Serial.print("  packetId: ");
  Serial.println(packetId);
  Serial.print("  qos: ");
  Serial.println(qos);
}

void onMqttUnsubscribe(uint16_t packetId) {
  Serial.println("Unsubscribe acknowledged.");
  Serial.print("  packetId: ");
  Serial.println(packetId);
}

void onMqttMessage(char* topic, char* payload, AsyncMqttClientMessageProperties properties, size_t len, size_t index, size_t total)
{
  Serial.println("Publish received.");
  for (int i = 0; i < len; i++) {
    Serial.print((char) payload[i]);
  }
  Serial.println("");
  if (strncmp(payload, "ON", 2) == 0) {
    digitalWrite(LED, HIGH);
    mqttClient.publish(MQTT_PUB_LED_S, 0, true, "ON");
    //    lv_event_send(ui_Switch2, LV_EVENT_VALUE_CHANGED, NULL);
    lv_obj_add_state(ui_Switch2, LV_STATE_CHECKED);
    lv_label_set_text(ui_Label1, "ON");
  }
  if (strncmp(payload, "OFF", 3) == 0) {
    digitalWrite(LED, LOW);
    mqttClient.publish(MQTT_PUB_LED_S, 0, true, "OFF");
    lv_obj_clear_state(ui_Switch2, LV_STATE_CHECKED);
    lv_label_set_text(ui_Label1, "OFF");
  }
}

void onMqttPublish(uint16_t packetId) {
  Serial.print("Publish acknowledged.");
  Serial.print("  packetId: ");
  Serial.println(packetId);
}

void setup()
{
  pinMode(LED, OUTPUT);
  digitalWrite(LED, LOW);
  Serial.begin(9600); /*serial init */
  Wire.begin(22, 21);
  Serial.println();
  dht20.begin();
  mqttReconnectTimer = xTimerCreate("mqttTimer", pdMS_TO_TICKS(2000), pdFALSE, (void*)0, reinterpret_cast<TimerCallbackFunction_t>(connectToMqtt));
  wifiReconnectTimer = xTimerCreate("wifiTimer", pdMS_TO_TICKS(2000), pdFALSE, (void*)0, reinterpret_cast<TimerCallbackFunction_t>(connectToWifi));
  WiFi.onEvent(WiFiEvent);
  mqttClient.onConnect(onMqttConnect);
  mqttClient.onDisconnect(onMqttDisconnect);
  mqttClient.onSubscribe(onMqttSubscribe);
  mqttClient.onUnsubscribe(onMqttUnsubscribe);
  mqttClient.onMessage(onMqttMessage);
  mqttClient.onPublish(onMqttPublish);
  mqttClient.setServer(MQTT_HOST, MQTT_PORT);
  // If your broker requires authentication (username and password), set them below
  mqttClient.setCredentials(mqtt_username, mqtt_password);
  connectToWifi();
  //LCD init
  lcd.begin();
  lcd.setRotation(1);
  lcd.fillScreen(TFT_BLACK);
  lcd.setTouch(calData);
  delay(100);
  //background light pin
  pinMode(27, OUTPUT);
  digitalWrite(27, HIGH);


  //lvgl init
  lv_init();

  lv_disp_draw_buf_init( &draw_buf, buf1, NULL, screenWidth * screenHeight / 13 );

  /*Display init*/
  static lv_disp_drv_t disp_drv;
  lv_disp_drv_init( &disp_drv );
  /*Display driver port of LVGL*/
  disp_drv.hor_res = screenWidth;
  disp_drv.ver_res = screenHeight;
  disp_drv.flush_cb = my_disp_flush;
  disp_drv.draw_buf = &draw_buf;
  lv_disp_drv_register( &disp_drv );

  /*touch driver port of LVGL*/
  static lv_indev_drv_t indev_drv;
  lv_indev_drv_init( &indev_drv );
  indev_drv.type = LV_INDEV_TYPE_POINTER;
  indev_drv.read_cb = my_touchpad_read;
  lv_indev_drv_register( &indev_drv );

  ui_init();        //LVGL UI init
  Serial.println( "Setup done" );
}

char buffer_t[10];
char buffer_h[10];

void loop()
{
  lv_timer_handler();
  delay(5);
  if (led_flag_Lock == 1)
  {
    if (led_flag == 1)
    {
      led_flag_Lock = 0;
      digitalWrite(LED, HIGH);
      mqttClient.publish(MQTT_PUB_LED_S, 0, true, "ON");
      //        lv_switch_on(ui_Switch2, LV_ANIM_ON);
    }
    else
    {
      led_flag_Lock = 0;
      digitalWrite(LED, LOW);
      mqttClient.publish(MQTT_PUB_LED_S, 0, true, "OFF");
      //        lv_switch_off(ui_Switch2, LV_ANIM_ON);
    }
  }
  unsigned long currentMillis = millis();
  if (currentMillis - previousMillis >= interval)
  {
    previousMillis = currentMillis;
    // New DHT sensor readings
    hum = (int)dht20.getHumidity();
    // Read temperature as Celsius (the default)
    temp = (int)dht20.getTemperature();
    Serial.print("hum:");
    Serial.println( hum);
    Serial.print("temp:");
    Serial.println( temp);
    itoa(hum, buffer_h, 10);
    itoa(temp, buffer_t, 10);
    lv_label_set_text(ui_Label3, buffer_t);
    lv_label_set_text(ui_Label5, buffer_h);
    if (isnan(temp) || isnan(hum))
    {
      Serial.println(F("Failed to read from DHT20 sensor!"));
      return;
    }

    // Publish an MQTT message on topic esp32/dht20/temperature
    uint16_t packetIdPub1 = mqttClient.publish(MQTT_PUB_TEMP, 1, true, String(temp).c_str());
    Serial.printf("Publishing on topic %s at QoS 1, packetId: %i", MQTT_PUB_TEMP, packetIdPub1);
    Serial.printf("Message: %.2f \n", temp);
    // Publish an MQTT message on topic esp32/dht20/humidity
    uint16_t packetIdPub2 = mqttClient.publish(MQTT_PUB_HUM, 1, true, String(hum).c_str());
    Serial.printf("Publishing on topic %s at QoS 1, packetId %i: ", MQTT_PUB_HUM, packetIdPub2);
    Serial.printf("Message: %.2f \n", hum);
  }
}

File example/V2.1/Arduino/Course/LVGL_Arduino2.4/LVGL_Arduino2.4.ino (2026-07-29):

#include <lvgl.h>
#include <TFT_eSPI.h>
#include <Arduino.h>
#include <Crowbits_DHT20.h>
#include "ui.h"

// Receives the LED state selected by the generated UI event code.
int led;

/*---------------------------------------------------------------
 * Display configuration
 * The LVGL canvas matches the physical 320 x 240 landscape display.
 * A partial buffer reduces RAM use while TFT_eSPI transfers each area.
 *--------------------------------------------------------------*/
static const uint16_t screenWidth = 320;
static const uint16_t screenHeight = 240;
static lv_color_t buf1[screenWidth * screenHeight / 8];

// Controls the TFT display and its touch controller.
TFT_eSPI lcd = TFT_eSPI();

// Provides temperature and humidity readings over the I2C bus.
Crowbits_DHT20 dht20;

// Stores the latest touch position returned by TFT_eSPI.
uint16_t touchX, touchY;

// Retains serial data storage included by the original example.
unsigned char buffer[256];

// Tracks the number of valid bytes currently held in buffer.
int count = 0;

/**
 * @brief Transfer an LVGL drawing area to the physical LCD.
 *
 * LVGL calls this function whenever a rendered area is ready. The callback
 * must notify LVGL after the SPI transfer so the buffer can be reused.
 *
 * @param disp LVGL display requesting the transfer.
 * @param area Inclusive screen coordinates of the updated rectangle.
 * @param px_map Pixel data generated by LVGL for that rectangle.
 * @return Nothing.
 */
void my_disp_flush(lv_display_t *disp, const lv_area_t *area, uint8_t *px_map)
{
  // LVGL's area coordinates are inclusive, so both dimensions need +1.
  uint32_t w = (area->x2 - area->x1 + 1);
  uint32_t h = (area->y2 - area->y1 + 1);

  // Send the rendered rectangle to the LCD over the TFT_eSPI transaction.
  lcd.startWrite();
  lcd.setAddrWindow(area->x1, area->y1, w, h);
  lcd.pushColors((uint16_t *)px_map, w * h, true);
  lcd.endWrite();

  // Tell LVGL that the buffer is free for the next partial render.
  lv_display_flush_ready(disp);
}

/**
 * @brief Provide the current touch state and position to LVGL.
 *
 * LVGL calls this function while processing input devices. Only touches
 * that pass the TFT_eSPI pressure threshold are reported as pressed.
 *
 * @param indev LVGL input device requesting data.
 * @param data Destination for the state and calibrated coordinates.
 * @return Nothing.
 */
void my_touchpad_read(lv_indev_t * indev, lv_indev_data_t * data)
{
  // 600 is the TFT_eSPI pressure threshold used to reject noise and false touches.
  bool touched = lcd.getTouch(&touchX, &touchY, 600);
  if (!touched)
  {
    // Report release so LVGL does not keep the previous point pressed.
    data->state = LV_INDEV_STATE_RELEASED;
  }
  else
  {
    // Forward the calibrated touch state and coordinates to LVGL.
    data->state = LV_INDEV_STATE_PRESSED;

    data->point.x = touchX;
    data->point.y = touchY;

    // Serial output makes touch calibration and orientation easy to verify.
    Serial.print("Data x ");
    Serial.println(touchX);

    Serial.print("Data y ");
    Serial.println(touchY);
  }
}

/**
 * @brief Clear the used portion of the retained serial buffer.
 *
 * Call this helper after buffer contains count valid bytes and those bytes
 * are no longer needed. It is provided for the serial workflow retained in
 * this sketch, although the current loop does not call it.
 *
 * @param None.
 * @return Nothing.
 */
void clearBufferArray()
{
  for (int i = 0; i < count; i++)
  {
    buffer[i] = NULL;
  }
}

/**
 * @brief Initialize the board peripherals, LVGL display, touch input, and UI.
 *
 * Arduino calls this function once after startup or reset. The generated UI
 * is created only after display and input callbacks have been registered.
 *
 * @param None.
 * @return Nothing.
 */
void setup()
{
  Serial.begin(115200);
  Serial2.begin(9600);

  /*---------------------------------------------------------------
   * Initialize the LED and DHT20 sensor
   * The UI later changes led, while the loop applies that value to GPIO25.
   *--------------------------------------------------------------*/
  pinMode(25, OUTPUT);
  digitalWrite(25, LOW);

  Wire.begin(22, 21);
  dht20.begin();

  lv_init();
  lv_tick_set_cb(millis);

  /*---------------------------------------------------------------
   * Initialize the LCD and backlight
   * Keep the backlight off until the controller has been cleared.
   *--------------------------------------------------------------*/
  lcd.begin();
  lcd.fillScreen(TFT_BLACK);
  delay(300);
  pinMode(27, OUTPUT);
  digitalWrite(27, HIGH);
  lcd.setRotation(1);

  /*---------------------------------------------------------------
   * Register the LVGL display and touch devices
   * LVGL uses these callbacks to move pixels to the LCD and obtain input.
   *--------------------------------------------------------------*/
  lv_display_t *disp = lv_display_create(screenWidth, screenHeight);
  lv_display_set_flush_cb(disp, my_disp_flush);
  lv_display_set_buffers(disp, buf1, NULL, sizeof(buf1), LV_DISPLAY_RENDER_MODE_PARTIAL);

  lv_indev_t *indev = lv_indev_create();
  lv_indev_set_type(indev, LV_INDEV_TYPE_POINTER);
  lv_indev_set_read_cb(indev, my_touchpad_read);

  ui_init();
}

/**
 * @brief Update sensor labels, apply the UI LED state, and service LVGL.
 *
 * Arduino calls this function repeatedly after setup() finishes. The short
 * delay leaves time for the system while keeping touch and UI updates fluid.
 *
 * @param None.
 * @return Nothing.
 */
void loop()
{
  Serial.print(led);

  /*---------------------------------------------------------------
   * Refresh the temperature and humidity labels
   * Convert each integer reading to text because LVGL labels accept strings.
   *--------------------------------------------------------------*/
  char DHT_buffer[6];
  int a = (int)dht20.getTemperature();
  int b = (int)dht20.getHumidity();
  snprintf(DHT_buffer, sizeof(DHT_buffer), "%d", a);
  // LVGL labels receive text, so convert the temperature before updating it.
  lv_label_set_text(ui_Label1, DHT_buffer);
  snprintf(DHT_buffer, sizeof(DHT_buffer), "%d", b);
  // Reuse the buffer for humidity after the temperature label has been updated.
  lv_label_set_text(ui_Label2, DHT_buffer);

  // Apply the state selected by the generated ON/OFF button callbacks.
  /*---------------------------------------------------------------
   * Apply the UI-selected LED state
   * The generated event callbacks set led to either 1 or 0.
   *--------------------------------------------------------------*/
  if (led == 1) {
    digitalWrite(25, HIGH);
    Serial.print("led_on");
  }

  if (led == 0) {
    digitalWrite(25, LOW);
    Serial.print("led_off");
  }

  // Service LVGL timers, redraws, and pending touch events.
  lv_timer_handler();
  // Yield briefly so the UI remains responsive while the loop repeats.
  delay(10);
}

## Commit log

2025-03-19 修改了单个文件
2026-07-29 Update code 2026-07-29 09:25
    [Configuring options.txt, code-format.cfg]

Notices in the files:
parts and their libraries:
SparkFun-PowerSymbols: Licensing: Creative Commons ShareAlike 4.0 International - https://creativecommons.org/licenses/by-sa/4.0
